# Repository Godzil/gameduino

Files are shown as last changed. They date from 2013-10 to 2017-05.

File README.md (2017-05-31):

gameduino
=========

What is it?
-----------

Gameduino is a game adapter for Arduino - or anything else with an SPI interface - built as a single shield that stacks up on top of the Arduino and has plugs for a VGA monitor and stereo speakers.

Legal stuffs
------------

This project was created by James Bowman <jamesb@excamera.com>. I strongly recommand you to visit his website first as it always will contain the more recent and official information about the Gameduino: http://excamera.com/sphinx/gameduino/index.html

Why this repo?
--------------

This github repository is maintained by Manoel Trapier <godzil@godzil.net> for his own project around Gameduino and by the fact there is missing a central repository with all needed file to build/hack your own Gameduino on Internet. James' website will of course store all of thoses files, but they are stored sparses around, and could be difficult to find.

More informations on Gameduino
-----------------------------

The sound and graphics are definitely old-school, but thanks to the latest FPGA technology, the sprite capabilities are a step above those in machines from the past.

video output is 400x300 pixels in 512 colors
all color processed internally at 15-bit precision
compatible with any standard VGA monitor (800x600 @ 72Hz)
background graphics
512x512 pixel character background
256 characters, each with independent 4 color palette
pixel-smooth X-Y wraparound scroll
foreground graphics
each sprite is 16x16 pixels with per-pixel transparency
each sprite can use 256, 16 or 4 colors
four-way rotate and flip
96 sprites per scan-line, 1536 texels per line
pixel-perfect sprite collision detection
audio output is a stereo 12-bit frequency synthesizer
64 independent voices 10-8000 Hz
per-voice sine wave or white noise
sample playback channel
The adapter is controlled via SPI read/write operations, and looks to the CPU like a 32Kbyte RAM. (Unlike many 8-bit machines, there are no restrictions on when you can access this RAM). There is a handy reference poster showing how the whole system works, and a set of sample programs and library.

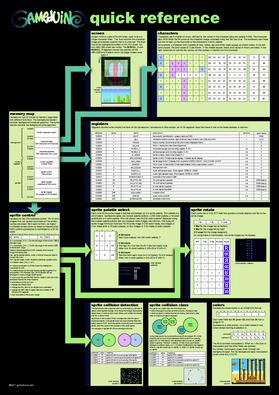
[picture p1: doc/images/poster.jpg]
Poster thumbnail


Contents
--------

You will find here all the data I've collected about the original Gameduino:
 - board/	contain the schematic and PCB design for the Gameduino
 - doc/		Documentation about the Gameduino and j1 CPU
 - fpga/	The FPGA source for the Gameduino
 - gd/		The Arduino library for the Gameduino
 - Python/	A set of tool writen in Python
 - j1/		The original j1 CPU with it's firmware and FPGA source
 - j0/		The slightly modified j1 CPU for the Gameduino, as the j0 is part of the Gameduino, only the firmware part is accessible here
 - archives/    Raw files found on James' website

Licensing
---------

Gameduino is open-source hardware (BSD license) and all its code is GPL licensed.

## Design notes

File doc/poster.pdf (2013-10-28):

# quick reference

# ©2011 gameduino.com

# screen

Screen RAM is a grid of 64×64 bytes, each byte is a single character index. This byte controls the character image and palette used for that 8×8 pixel cell. The total size of the background screen is 512×512 pixels, but only 400×300 pixels are visible. The SCROLL_X and SCROLL_Y registers control the position of this

400×300 pixel window within the larger screen area.

# memory map

### Gameduino has 32 kbytes of memory, organized into different functions. The background section controls background character graphics. The sprite

section controls the foreground sprite graphics.

# sprite control

### Gameduino has 256 hardware sprites: 16×16 pixel

images that can appear anywhere on the screen.

### Sprites are drawn from back-to-front, so higher-

numbered sprites cover up lower-numbered ones.

### Each sprite’s appearance is controlled by a 32-bit word:

# registers

Registers control some simple functions of the Gameduino. Gameduino is little-endian, so 16-bit registers have their lower 8 bits at the lower address in memory.

# characters

Characters are 8×8 grids of pixels, defined by the values in the character data and palette RAMs. The character data RAM holds the 64 pixels of the character image, encoded using two bits per pixel. The hardware uses these two bits to look up the final color in the character’s 4-entry palette.
For example, a character with a palette of blue, yellow, red and white might appear as shown below. In the left-hand square, the pixel values 0–3 are shown. In the middle square, these pixel values in binary are listed. In the right hand column are the hex values, as they appear in memory for this character.

# sprite palette select

Each pixel of the sprite image is fetched and looked up in a sprite palette. This palette is a list of colors. Gameduino gives you several palette options: a 256-color palette, a 16-color

### palette and a 4-color palette. Why not always use the 256-color palette? Because using the smaller palette options lets you squeeze more images into memory. 256 bytes of sprite image RAM can hold one 16x16 sprite image in 256-color mode, two images in

4-bit mode (with a 16 color palette), or four images in 2-bit mode (4 color palette).

# colors

### Gameduino stores colors in an ARGB1555 format:

### Each color field red (R) green (G) and blue (B) has a

range 0–31.

### Gameduino is little-endian, so a color stored in two bytes stored starting at address is:

### The A bit controls transparency. When A=1 the pixel is

transparent and the other fields are ignored.

### For sprites, transparent pixels show through the background layer. For the background layer, transparent

pixels show BG_COLOR.

# sprite rotate

### Each sprite has a 3-bit ROT field that applies a simple rotation and flip to the

sprite image.

background

0x0000

code
sample:
scroll

0x7FFF

control
registers

0x0FFF
0x1000

0x1FFF
0x2000

0x27FF
0x2800

0x2FFF
0x3000

0x37FF
0x3800

0x3FFF
0x2800

sprites

64x64 character screen

character data
256 characters of 8x8 pixels

character palettes
256 characters of 4 colors

control registers
collision RAM

sprite control
256x4 bytes

sprite palette
4 palettes of 256 colors

sprite images
64 images of 16x16 bytes

X X coordinate, 0-511. 0 is the left edge of the screen, 399 is the right edge.
Y Y coordinate, 0-511. 0 is the top edge of the screen, 299 is the bottom edge.
IMAGE Spriteimageselect,0-63. Selects which source image the sprite uses.
PAL Sprite palette select, 4 bits. Controls how pixel data is turned into color.
ROT Sprite rotate, 3 bits. Rotates a sprite by quarter-turns. C Collision class, 0 is J, 1 is K.
To hide a sprite park it off the screen by setting its Y coordinate to 400.
To make a large sprite draw several sprites together in a grid pattern. For example, four 16x16 sprites can be arranged to make a single 32x32 sprite.
To spin a sprite use the ROT field to rotate it, and use extra animation frames for finer rotations.
To animate a sprite you can
- change the IMAGE field
- change the PAL field to do simple color animation
- change the ROT field to apply flips and rotates of 90, 180 and 270 degrees
- load new data to the source image.

31 30 29 28 27 26 25 24 23 22 21 20 19 18 17 16 15 14 13 12 11 10 9 8 7 6 5 4 3 2 1 0
C | IMAGE | Y | PAL | ROT | X

SCROLL_X

SCROLL_Y

00 01 01 01

00 01 10 10

01 01 10 10

01 01 01 01

00 01 10 11

00 01 01 01

01 01 01 01

00 01 01 01

01 01 01 01

10 01 01 01

10 01 01 00

10 01 01 01

11 11 11 11

10 01 01 01

10 01 01 01

10 01 01 01

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
reset value
0x6d
0x10
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
0000 (black)
0000 (black)
0000 (black)
0000 (black)
0
0
0

access
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
name
IDENT
REV
FRAME
VBLANK
SCROLL_X
SCROLL_Y
JK_MODE
SPR_DISABLE
SPR_PAGE
IOMODE
BG_COLOR
SAMPLE_L
SAMPLE_R
SCREENSHOT_Y
PALETTE 16A
PALETTE 16B
PALETTE 4A
PALETTE 4B
COLLISION
VOICES
SCREENSHOT

bytes
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
address
0x2800
0x2801
0x2802
0x2803
0x2804
0x2806
0x2808
0x280A
0x280B
0x280C
0x280E
0x2810
0x2812
0x281E
0x2840
0x2860
0x2880
0x2888
0x2900
0x2A00
0x2B00

description
Gameduino identification—always reads as 0x6D
Hardware revision number. High 4 bits are major revision, low 4 bits are minor Frame counter, increments at the end of each displayed frame
Set to 1 during the video blanking period
Horizontal background scrolling register, 0–511
Vertical background scrolling register, 0–511
Sprite collision class mode enable 0–1
Sprite control: 0 enable sprite display, 1 disable sprite display
Sprite page select: 0 display from locations 0x3000–0x33FF, 1 from 0x3400–0x37FF Pin 2 mode: 0=disconnect, 0x46=flash enable, 0x4A=coprocessor control Background color
Audio left sample value, 16 bit signed -32768 to +32767
Audio right sample value, 16 bit signed -32768 to +32767
Screenshot line select 0–299
16-color sprite A palette
16-color sprite B palette
4-color sprite A palette
4-color sprite B palette
Collision RAM
Audio voice controls
Screenshot line RAM

### 8–bit mode Each byte indexes into 256-color palette, P

3 | 2 | 1 | 0
0 | 0
0 | 1 | N | AB
1 | N | AB

P

### 2–bit mode Two bits from each byte (N=3 is highest, N=0 is lowest) index into 4-color palette A (AB=0) or B (AB=1)

### 4–bit mode The high (N=1) or low (N=0) 4 bits from each byte index into 16-color palette A (AB=0) or B (AB=1)

code sample:
palettes
Y flip | X flip | XY swap
2 | 1 | 0

### Y flip flip the image top-to-bottom X flip flip the image left-to-right XY swap flip the image diagonally By using these in combination, the sprite image can be rotated:

code sample: rotation

ROT | Y flip | X flip | XY swap | results
7 | 1 | 1 | 1
6 | 1 | 1 | 0
5 | 1 | 0 | 1
4 | 1 | 0 | 0
3 | 0 | 1 | 1
2 | 0 | 1 | 0
1 | 0 | 0 | 1
0 | 0 | 0 | 0

code sample:
bgcolor

# sprite collision class

In a game you might have the following rules:
- when the player touches an enemy bomb, the player dies
- when a player’s missile touches an enemy, that enemy dies. Here is a typical in-game situation:

missile
01 (J)

player
player | 02 (K)
00 (J)

bomb
03 (K)

Notice that bomb 04 covers both bomb 03 and player 00. In this situation we’re much more interested that bomb 04 is covering player 00. For this reason, the hardware has a mode JK_MODE where it ignores “friendly” collisions. In this mode, each sprite belongs a collision class J or K. Collision notifications only happen when a J sprite covers up a K sprite, or when a K sprite covers up a J sprite.

code sample:
jkcollision

sprite 00 no collision

meaning

sprite 01 no collision
sprite 02 covers some pixels from sprite 01 sprite 03 no collision
sprite 04 covers some pixels from sprite 00

0x2900

address

0x2901
0x2902
0x2903
0x2904

FF

value

FF
01
FF
00

bomb
04 (K)

# sprite collision detection

The Gameduino has a special memory area that you can use to detect when sprites overlap. As it draws the image, Gameduino keeps track of which pixels cover others, and writes the results into the collision RAM.
Each byte in the collision RAM corresponds with the same numbered sprite. If the sprite does not cover another then the byte’s value is 0xFF. But if the sprite covers any part of another sprite, then the value is the number of the other sprite.
For example, if sprites 00–03 are arranged like this:
00 | 01 | 02

code sample:
collision

sprite 00 did not cover up any other sprite

meaning

sprite 01 covered up some pixels from sprite 00 sprite 02 did not cover up any other sprite sprite 03 covered some pixels from sprite 02

0x2900

address

0x2901
0x2902
0x2903

FF

value

00
FF
02

03

15 | 14 | 13 | 12 | 11 | 10 | 9 | 8 | 7 | 6 | 5 | 4 | 3 | 2 | 1 | 0
A | | | R | | | | | G | | | | | B

A

G2 | G1 | G0 | B4
7 | 6 | 5 | 4 | 3 | 2 | 1 | 0
| | | | B3 | B2 | B1 | B0
| R4 | R3 | R2 | R1 | R0 | G4 | G3

address

address+1

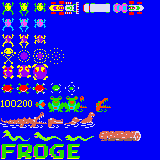
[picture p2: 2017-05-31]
python/471fcf9e.png

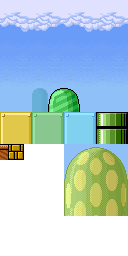
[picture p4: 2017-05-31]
python/platformer.png

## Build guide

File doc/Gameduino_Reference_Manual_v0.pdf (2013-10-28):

!"#$%&'()*+$,$-$(.$*/"(&"0

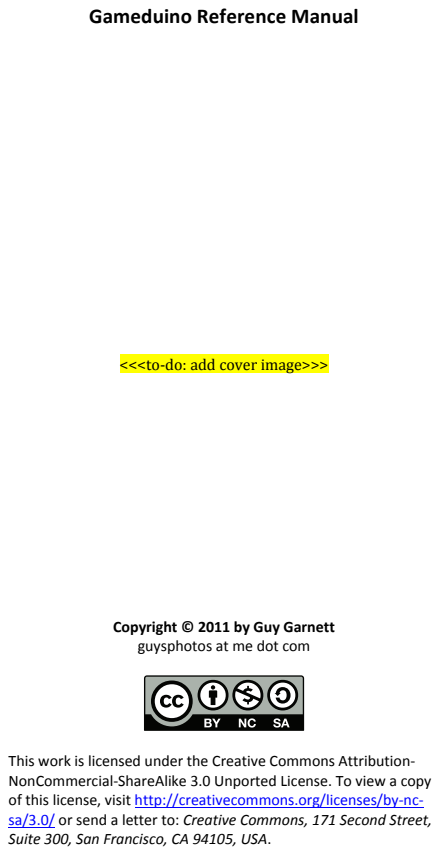
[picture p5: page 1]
/&0$)1'23)0$)40.,5$,-)"5-,2)(&,)62,*(07,)6'++'5$)8((209"(0'5: ;'56'++,2.0*4:<&*2,8403,)=>?)@5%'2(,-)A0.,5$,>)/')70,1)*).'%#) 'B)(&0$)40.,5$,C)70$0()&((%DEE.2,*(07,.'++'5$>'2!E40.,5$,$E9#:5.: $*E=>?E '2)$,5-)*)4,((,2)('D)!"#$%&'#(!)**)+,-(./.(0#1)+2(0%"##%-( 03&%#(455-(0$+(6"$+1&,1)-(!7 89.5:-(;07>

12345!6(.+&7-8$!2+9+,+8)+!:(87(;

1)(6$(6<
=.>()?0$%4$#$(6< @@@@@@@@@@@@@@@@@@@@@@@@@@@@@@@@@@@@@@@@@@@@@@@@@@@@@@@@@@@@@@@@@@@@@@@@@@@@@@@@@@: A(6-)%&.6')( @@@@@@@@@@@@@@@@@@@@@@@@@@@@@@@@@@@@@@@@@@@@@@@@@@@@@@@@@@@@@@@@@@@@@@@@@@@@@@@@@@@@@@@@@@@@@: !"#$*B-)4-"##'(4*?'65*!"#$%&'()@@@@@@@@@@@@@@@@@@@@@@@@@@@@@@@@@@@@@@@@@@@@@@@@@@@@@@@8
6+##-8/!<#(,#+&============================================================================================================================================================ > !"#$%"#&((((((((((((((((((((((((((((((((((((((((((((((((((((((((((((((((((((((((((((((((((((((((((((((((((((((((((((((((((((((((((((((((((((((((((((((((((((((((((((((((((((((() *&+&,-./&01'20+3#-0/&01((((((((((((((((((((((((((((((((((((((((((((((((((((((((((((((((((((((((((((((((((((((((((((((((((((((((((((((((((((((((((((((((((((4 1+*+;$?-8/!(!6(.+ =================================================================================================================================================== @ 5$$;A!(8&!5+)B8-C7+A============================================================================================================================================== D 50313",'6-%&#78. (((((((((((((((((((((((((((((((((((((((((((((((((((((((((((((((((((((((((((((((((((((((((((((((((((((((((((((((((((((((((((((((((((((((((((((((((((((((((9 :"/&$;30-'6<1=-0'813,313&>(((((((((((((((((((((((((((((((((((((((((((((((((((((((((((((((((((((((((((((((((((((((((((((((((((((((((((((((((((((((((((((((((((9 ?-0>&#+30@'A#$;30-'B&/-#< ((((((((((((((((((((((((((((((((((((((((((((((((((((((((((((((((((((((((((((((((((((((((((((((((((((((((((((((((((((((((((((((((C :"/&$;30-'D&>-;#E&'F3G#"#< (((((((((((((((((((((((((((((((((((((((((((((((((((((((((((((((((((((((((((((((((((((((((((((((((((((((((((((((((((((((((((((((C
C65$-*=220'."6')(<@@@@@@@@@@@@@@@@@@@@@@@@@@@@@@@@@@@@@@@@@@@@@@@@@@@@@@@@@@@@@@@@@@@@@@@@@@@@@@@@@@@@D
6+8+,(;%E7,?$A+!1-A?;(F!3&(?#+,====================================================================================================================== G H8&7A#,-(;!E,$)+AA!I$8#,$;===================================================================================================================================== G

### =%E"(.$%*!"#$%&'()*B-)4-"##'(4@@@@@@@@@@@@@@@@@@@@@@@@@@@@@@@@@@@@@@@@@@@@@@@@@@@@@@@@@F

G'%$)*H'#'(4 @@@@@@@@@@@@@@@@@@@@@@@@@@@@@@@@@@@@@@@@@@@@@@@@@@@@@@@@@@@@@@@@@@@@@@@@@@@@@@@@@@@@@@@@@@@@F
4,(.+!2(#+ =================================================================================================================================================================== J K+(.!<F8)B,$8-L(#-$8 ==========================================================================================================================================MN *-;G,&'H;II&#30@ ((((((((((((((((((((((((((((((((((((((((((((((((((((((((((((((((((((((((((((((((((((((((((((((((((((((((((((((((((((((((((((((((((((((((((((((((((((( JK 8.$"130@'LII7ME#&&0'LGN&E1> (((((((((((((((((((((((((((((((((((((((((((((((((((((((((((((((((((((((((((((((((((((((((((((((((((((((((((((((((((((((((((((( JJ O&#13E",'H,"0P30@ (((((((((((((((((((((((((((((((((((((((((((((((((((((((((((((((((((((((((((((((((((((((((((((((((((((((((((((((((((((((((((((((((((((((((((((((((((( J) D">1&#'?=">30@(((((((((((((((((((((((((((((((((((((((((((((((((((((((((((((((((((((((((((((((((((((((((((((((((((((((((((((((((((((((((((((((((((((((((((((((((((((((((( J4 K-#.(??+&!6,(?B-)A===============================================================================================================================================MD
I"-%?"-$*I".>'(4 @@@@@@@@@@@@@@@@@@@@@@@@@@@@@@@@@@@@@@@@@@@@@@@@@@@@@@@@@@@@@@@@@@@@@@@@@@@@@@@@@@:J 1'-.&'6*K)"-%*/)%','."6')(< @@@@@@@@@@@@@@@@@@@@@@@@@@@@@@@@@@@@@@@@@@@@@@@@@@@@@@@@@@@@@@@@@@@@:J
6(.+&7-8$!:$&-9-)(#-$8A ====================================================================================================================================MO P$FA#-)Q!<B-+;&!:$&-9-)(#-$8A==============================================================================================================================MO
L)MA6MN)&-<$0,*B-)O$.6<@@@@@@@@@@@@@@@@@@@@@@@@@@@@@@@@@@@@@@@@@@@@@@@@@@@@@@@@@@@@@@@@@@@@@@@@@@@@:D
H8?7#A!(8&!I$8#,$;;+,A ==========================================================================================================================================MG R8);$A7,+A!(8&!I(A+A=============================================================================================================================================MG
!"#$%&'()*H$.5('."0*+$,$-$(.$@@@@@@@@@@@@@@@@@@@@@@@@@@@@@@@@@@@@@@@@@@@@@@@@@@@@@@@@@@@@@:F I"-%?"-$*A(6$-,".$@@@@@@@@@@@@@@@@@@@@@@@@@@@@@@@@@@@@@@@@@@@@@@@@@@@@@@@@@@@@@@@@@@@@@@@@@@@@@@@@@:F
S(,&T(,+!I$.?(#-U-;-#F=======================================================================================================================================MJ <EH!I$..78-)(#-$8 ================================================================================================================================================MV F3G#"#<'M;..-#1 ((((((((((((((((((((((((((((((((((((((((((((((((((((((((((((((((((((((((((((((((((((((((((((((((((((((((((((((((((((((((((((((((((((((((((((((((((((((( )K A,1&#0"1&'M65'A$$#&>>(((((((((((((((((((((((((((((((((((((((((((((((((((((((((((((((((((((((((((((((((((((((((((((((((((((((((((((((((((((((((((((((((((((((((((( )K
/$#)-3*/"2@@@@@@@@@@@@@@@@@@@@@@@@@@@@@@@@@@@@@@@@@@@@@@@@@@@@@@@@@@@@@@@@@@@@@@@@@@@@@@@@@@@@@@@@@@89
6(.+&7-8$!:+.$,F!:(?=====================================================================================================================================>M

I$8#,$;!2+/-A#+,A =====================================================================================================================================================>> M="#&$'D&@3>1&#>(((((((((((((((((((((((((((((((((((((((((((((((((((((((((((((((((((((((((((((((((((((((((((((((((((((((((((((((((((((((((((((((((((((((((((((((((((((( )4
G'%$)*L'<20"3@@@@@@@@@@@@@@@@@@@@@@@@@@@@@@@@@@@@@@@@@@@@@@@@@@@@@@@@@@@@@@@@@@@@@@@@@@@@@@@@@@@@@@@@@@8F
<),$;;-8/=======================================================================================================================================================================>V Q#"."#-;0$(((((((((((((((((((((((((((((((((((((((((((((((((((((((((((((((((((((((((((((((((((((((((((((((((((((((((((((((((((((((((((((((((((((((((((((((((((((((((((((( )R M.,31'ME#&&0'ME#-,,30@((((((((((((((((((((((((((((((((((((((((((((((((((((((((((((((((((((((((((((((((((((((((((((((((((((((((((((((((((((((((((((((((((((((((((((( 4K K()Q/,$78&!I$;$,====================================================================================================================================================WN IB(,()#+,!6,(?B-)A =================================================================================================================================================WN DABS65?T'6,"<I3&,$'63E1;#& ((((((((((((((((((((((((((((((((((((((((((((((((((((((((((((((((((((((((((((((((((((((((((((((((((((((((((((((((((((((((((((((((( 4J DABS?!DT'6,"<I3&,$'?="#"E1&#'M&1(((((((((((((((((((((((((((((((((((((((((((((((((((((((((((((((((((((((((((((((((((((((((((((((((((((((((((((((((( 4J DABS6AFT'6,"<I3&,$'?="#"E1&#'6",&11&>(((((((((((((((((((((((((((((((((((((((((((((((((((((((((((((((((((((((((((((((((((((((((((((((((((((((( 4) <?,-#+A===========================================================================================================================================================================@W M.#31&'?-01#-,(((((((((((((((((((((((((((((((((((((((((((((((((((((((((((((((((((((((((((((((((((((((((((((((((((((((((((((((((((((((((((((((((((((((((((((((((((((((((((( U4 M.#31&'?-,,3>3-0'*&1&E13-0 (((((((((((((((((((((((((((((((((((((((((((((((((((((((((((((((((((((((((((((((((((((((((((((((((((((((((((((((((((((((((((((((((((( UU M.#31&'5/"@&'*"1"((((((((((((((((((((((((((((((((((((((((((((((((((((((((((((((((((((((((((((((((((((((((((((((((((((((((((((((((((((((((((((((((((((((((((((((((((( U9 M.#31&'6",&11&>((((((((((((((((((((((((((((((((((((((((((((((((((((((((((((((((((((((((((((((((((((((((((((((((((((((((((((((((((((((((((((((((((((((((((((((((((((((((((( U9 I$;$, ==============================================================================================================================================================================@G F-@3E",'?-,-# ((((((((((((((((((((((((((((((((((((((((((((((((((((((((((((((((((((((((((((((((((((((((((((((((((((((((((((((((((((((((((((((((((((((((((((((((((((((((((((( UV !"#$%"#&'?-,-# ((((((((((((((((((((((((((((((((((((((((((((((((((((((((((((((((((((((((((((((((((((((((((((((((((((((((((((((((((((((((((((((((((((((((((((((((((((((( UV L;1.;1'?-,-# (((((((((((((((((((((((((((((((((((((((((((((((((((((((((((((((((((((((((((((((((((((((((((((((((((((((((((((((((((((((((((((((((((((((((((((((((((((((((((((( UW
=&%')@@@@@@@@@@@@@@@@@@@@@@@@@@@@@@@@@@@@@@@@@@@@@@@@@@@@@@@@@@@@@@@@@@@@@@@@@@@@@@@@@@@@@@@@@@@@@@@@@@@@@@PQ
<$78&!<F8#B+A-A!2+/-A#+,A===================================================================================================================================@V O-3E&'?-01#-,((((((((((((((((((((((((((((((((((((((((((((((((((((((((((((((((((((((((((((((((((((((((((((((((((((((((((((((((((((((((((((((((((((((((((((((((((((((((((((( UR D30@'B-$;,"1-# (((((((((((((((((((((((((((((((((((((((((((((((((((((((((((((((((((((((((((((((((((((((((((((((((((((((((((((((((((((((((((((((((((((((((((((((((((((((( 9J <(.?;+!2+/-A#+,A======================================================================================================================================================DM
R:*1)2-).$<<)-@@@@@@@@@@@@@@@@@@@@@@@@@@@@@@@@@@@@@@@@@@@@@@@@@@@@@@@@@@@@@@@@@@@@@@@@@@@@@@@@@@@@@@@@ST
I$?,$)+AA$,!H8#+,9()+============================================================================================================================================DW ?-.#-E&>>-#'?-01#-,((((((((((((((((((((((((((((((((((((((((((((((((((((((((((((((((((((((((((((((((((((((((((((((((((((((((((((((((((((((((((((((((((((((((((((((( 94 ?-.#-E&>>-#'B3E#-E-$&((((((((((((((((((((((((((((((((((((((((((((((((((((((((((((((((((((((((((((((((((((((((((((((((((((((((((((((((((((((((((((((((((((((((( 94 ?-.#-E&>>-#'?-//;03E"13-0>'H,-EP((((((((((((((((((((((((((((((((((((((((((((((((((((((((((((((((((((((((((((((((((((((((((((((((((((((((((((((( 94 ?-.#-E&>>-#7L0,<'D&@3>1&#>(((((((((((((((((((((((((((((((((((((((((((((((((((((((((((((((((((((((((((((((((((((((((((((((((((((((((((((((((((((((((((((((( 9U PM!3,)B-#+)#7,+!(8&!E,$/,(..-8/ ===================================================================================================================DO X-#1=7H">&$'A>>&/G,<'F"0@;"@&((((((((((((((((((((((((((((((((((((((((((((((((((((((((((((((((((((((((((((((((((((((((((((((((((((((((((((((((((((( 9W 8>30@'1=&'YJ'A>>&/G,&#(((((((((((((((((((((((((((((((((((((((((((((((((((((((((((((((((((((((((((((((((((((((((((((((((((((((((((((((((((((((((((((((((((((((((( CJ YJ'A>>&/G,<'F"0@;"@&'D&I&#&0E&((((((((((((((((((((((((((((((((((((((((((((((((((((((((((((((((((((((((((((((((((((((((((((((((((((((((((((((((((((( CJ I$&+!X?#-.-L(#-$8===================================================================================================================================================GD YJ'B3E#-E-$&(((((((((((((((((((((((((((((((((((((((((((((((((((((((((((((((((((((((((((((((((((((((((((((((((((((((((((((((((((((((((((((((((((((((((((((((((((((((((((((( VV
U.-$$(<5)6*V$"6&-$@@@@@@@@@@@@@@@@@@@@@@@@@@@@@@@@@@@@@@@@@@@@@@@@@@@@@@@@@@@@@@@@@@@@@@@@@@@@@@@@@DF
<),++8AB$#!Y-8+!<+;+)#!2+/-A#+, ========================================================================================================================GJ <),++8AB$#!Y-8+!K799+, ==========================================================================================================================================GV
!0)<<"-3@@@@@@@@@@@@@@@@@@@@@@@@@@@@@@@@@@@@@@@@@@@@@@@@@@@@@@@@@@@@@@@@@@@@@@@@@@@@@@@@@@@@@@@@@@@@@@@@@@F9
3),$8F.A ====================================================================================================================================================================JN 5-.+===============================================================================================================================================================================JN

-*

1)%$
<Q+#)B!M'!Z(-#!9$,!6(.+&7-8$!H8-#-(;-L(#-$8================================================================================== D <Q+#)B!>'!H8-#-(;-L(#-$8!T-#B!<?;(AB!<),++8 ==================================================================================== D <Q+#)B!W'!6(.+!Y$$?!7A-8/!61''T(-#*U;(8Q[\=============================================================================MW <Q+#)B!@'!<EH!H8-#-(;-L(#-$8===================================================================================================================>N <Q+#)B!D'!PM!3AA+.U;F!E,$/,(.!5+.?;(#+====================================================================================DO <Q+#)B!O'!R](.?;+!<7U,$7#-8+===========================================================================================================GW <Q+#)B!G'!R](.?;+!:7;#-?;+%R8#,F!<7U,$7#-8+ ===========================================================================GW <Q+#)B!J'!H8),+.+8#-8/!Y$$? =============================================================================================================G@ <Q+#)B!V'!1+),+.+8#-8/!Y$$? ============================================================================================================G@

*

H";0$<
5(U;+!M'!JNN]ONN!<^63!^-&+$!X7#?7#============================================================================================== J 5(U;+!>'!^-&+$!4,(.+!2(#+ ==================================================================================================================== V 5(U;+!W'!^+,#-)(;!K;(8Q-8/====================================================================================================================M> 5(U;+!@'!S$A#!H8#+,9()+==========================================================================================================================MJ 5(U;+!D'!S(,&T(,+!I$.?(#-U-;-#F!Y-A#============================================================================================MJ 5(U;+!O'!6(.+&7-8$!:+.$,F!:(?===================================================================================================>M 5(U;+!G'!H1R_5!2+/-A#+, =======================================================================================================================>@ 5(U;+!J'!2R^!2+/-A#+, ============================================================================================================================>@ 5(U;+!V'!423:R!2+/-A#+,======================================================================================================================>@ 5(U;+!MN'!^KY3_`!2+/-A#+, ================================================================================================================>@ 5(U;+!MM'!<I2XYYab!(8&!<I2XYYac!2+/-A#+,A============================================================================>D 5(U;+!M>'!P`a:X1R!2+/-A#+,===============================================================================================================>O 5(U;+!MW'!PMa2R<R5!2+/-A#+, ==============================================================================================================>O 5(U;+!M@'!<E2a1H<3KYR!2+/-A#+,======================================================================================================>O 5(U;+!MD'!<E2aE36R!2+/-A#+,=============================================================================================================>G 5(U;+!MO'!HX:X1R!2+/-A#+, ================================================================================================================>G 5(U;+!MG'!K6aIXYX2!2+/-A#+,============================================================================================================>G 5(U;+!MJ'!<3:EYRaY!(8&!<3:EYRa2!2+/-A#+,A==========================================================================>G 5(U;+!MV'!<I2RR_<SX5ac!2+/-A#+,=================================================================================================>J 5(U;+!>N'!<I2XYY!2+/-A#+,A================================================================================================================>V 5(U;+!>M'!K6aIXYX2!2+/-A#+,============================================================================================================WN 5(U;+!>>'!23:aIS2!K-#.(?!X,/(8-L(#-$8 ===================================================================================WM 5(U;+!>W'!IB(,()#+,!<+#A=======================================================================================================================W> 5(U;+!>@'!23:aE3Y!E(;+##+!4$,.(# ================================================================================================WW 5(U;+!>D'!23:aEHI!:+.$,F!:(?=====================================================================================================W@ 5(U;+!>O'!23:aIS2!:+.$,F!:(?===================================================================================================WD 5(U;+!>G'!23:aE3Y!:+.$,F!:(?====================================================================================================WV 5(U;+!>J'!<?,-#+!I$8#,$;!Z$,&===========================================================================================================@W 5(U;+!>V'!<?,-#+!E(;+##+!:$&+A==========================================================================================================@@ 5(U;+!WN'!<?,-#+!2$#(#-$8=====================================================================================================================@@ 5(U;+!WM'!<?,-#+!H.(/+!K-#.(?==========================================================================================================@D 5(U;+!W>'!23:a<E2E3Y!:+.$,F!:(?============================================================================================@O 5(U;+!WW'!E3YR55RMO!:+.$,F!:(?===============================================================================================@O 5(U;+!W@'!MO%I$;$,!<?,-#+!E(;+##+ =====================================================================================================@O 5(U;+!WD'!E3YR55R@!:+.$,F!:(?==================================================================================================@G 5(U;+!WD'!@%I$;$,!<?,-#+!E(;+##+========================================================================================================@G 5(U;+!WO'!E(;+##+!R8#,F!4$,.(#=========================================================================================================@J 5(U;+!WG'!I$;$,!<?()+ ============================================================================================================================@J 5(U;+!WV'!^XHIR<!:+.$,F :(? ========================================================================================================@V 5(U;+!@N'!<3:EYRaY!(8&!<3:EYRa2!2+/-A#+,A==========================================================================D> 5(U;+!WJ'!PMa2R<R5!2+/-A#+, ==============================================================================================================DW 5(U;+!WV'!PMaIX1R!:+.$,F!:(?======================================================================================================DW 5(U;+!@N'!IX::!:+.$,F!:(?==========================================================================================================D@

*-

5(U;+!@M'!cYH_R!2+/-A#+, =====================================================================================================================D@ 5(U;+!@>'!4E63!HI3E!2+/-A#+,A==========================================================================================================DD 5(U;+!@W'!42RdSe!(8&!42Rd5HI`!2+/-A#+,A===============================================================================DD 5(U;+!@@'!E>!HfX!2+/-A#+,A===================================================================================================================DD 5(U;+!@D'!23_1X:!2+/-A#+,===============================================================================================================DO 5(U;+!@O'!IYXI`!2+/-A#+,====================================================================================================================DO 5(U;+!@G'!4Y3<S!<EH!2+/-A#+,A ==========================================================================================================DO 5(U;+!@J'!PM!3AA+.U;F!Y(8/7(/+!<7..(,F =================================================================================DV 5(U;+!@V'!PM!3AA+.U;+,!1-,+)#-*+A ===================================================================================================OM 5(U;+!DN'!PM!Y-#+,(;!H8A#,7)#-$8A =======================================================================================================O> 5(U;+!DM'!PM!3_<!4$,#B!H8A#,7)#-$8A================================================================================================OW 5(U;+!D>'!PM!3&&-#-$8(;!H8A#,7)#-$8A ===============================================================================================OO 5(U;+!DW'!PM!:7;#-%Z$,&!H8A#,7)#-$8A=============================================================================================OO 5(U;+!D@'!PM!:+,/+&!H8A#,7)#-$8A =====================================================================================================OG 5(U;+!DD'!PM!3AA+.U;+,!4;$T!I$8#,$; =============================================================================================GM 5(U;+!DO'!PM!:-),$)$&+!H8A#,7)#-$8A ===============================================================================================GG 5(U;+!DG'!3Yg!X?+,(#-$8!I$&+A ========================================================================================================GJ 5(U;+!DJ'!1(#(!<#()Q!3&h7A#.+8# =====================================================================================================GJ 5(U;+!DV'!2+#7,8!<#()Q!3&h7A#.+8#=================================================================================================GJ 5(U;+!ON'!<I2RR_<SX5ac!2+/-A#+,=================================================================================================GJ 5(U;+!OM'!<I2RR_<SX5!:+.$,F!:(?===========================================================================================GV

*--

V'4&-$<
4-/7,+!M'!^-&+$!1-A?;(F!Y(F+,A==========================================================================================================>G 4-/7,+!>'!<),$;;-8/ ===================================================================================================================================>G 4-/7,+!W'!<),$;;!Z,(?(,$78&==============================================================================================================>J 4-/7,+!@'!PM!Y$/-)(;!3,)B-#+)#7,+ ======================================================================================================DO

*---

+$<)&-.$<
2+A$7,)+!M'!S(,&T(,+!<$7,)+A =========================================================================================================== > 2+A$7,)+!>'!<$9#T(,+!1$T8;$(&!Y-8QA ============================================================================================ W

M

## FMK'6*!"#'(4*?'65*=-%&'()*"(%*!"#$%&'()

=.>()?0$%4$#$(6<
P(.+A!K$T.(8!),+(#+&!#B+!6(.+&7-8$i!(8&!T-#B$7#!B-A!B+;?i!-8?7#i!(8&!)$,,+)#-$8A! #B-A!&$)7.+8#!T$7;&!8$#!+]-A#=!!38F!*(;7(U;+!-89$,.(#-$8!-8!#B-A!.(87(;!7;#-.(#+;F! )$.+A!9,$.!P(.+Ai!(8&!(8F!+,,$,A!#B(#!T+,+!-8#,$&7)+&!-8!#B+!?,$)+AA!(,+!.-8+=

5B+!.+.U+,A!$9!#B+!6(.+&7-8$%K+#(!.(-;-8/!;-A#i!?(,#-)7;(,;F!I$;-8 1$$;+F! ?,$*-&+&!*(;7(U;+!9++&U()Q!(8&!+8)$7,(/+.+8#!U(A+&!$8!-8-#-(; &,(9#A!$9!#B-A! .(87(;=
A(6-)%&.6')(
:$&+,8!.-),$)$8#,$;;+,Ai!;-Q+!#B+!3#.+;!3^2!?,$)+AA$,A!#B(#!?$T+,!#B+!$?+8% A$7,)+!3,&7-8$!U$(,&Ai!(,+!(#!;+(A#!(A!?$T+,97;!(A!#B+!J%U-#!IEgA!#B(#!?$T+,+&! (,)(&+!*-&+$!/(.+A!-8!#B+!j/$;&+8!(/+k!$9!#B+!MVJNlA=!!4$,!+](.?;+i!#B+!e-;$/!eJN! T(A!(8!(&*(8)+&!J%U-#!IEg!#B(#!(;A$!9+(#7,+&!;-.-#+&!MO%U-#!-8A#,7)#-$8A=!!5B+!eJN! ,(8!(#!A?++&A!$9!7?!#$!(!.-;;-$8!-8A#,7)#-$8A!?+,!A+)$8&i!(8&!?$T+,+&!);(AA-)!/(.+A! A7)B!(A E()!:(8i!1$8Q+F!`$8/i!(8&!6(;(]-(8=!!KF!)$.?(,-A$8i!#B+!35.+/(W>J!#B(#! -A!(#!#B+!B+(,#!$9!#B+!3,&7-8$!g8$!+]+)7#+A!7?!#$!MO .-;;-$8!J%U-#!-8A#,7)#-$8A!?+,! A+)$8&=

5B+!6(.+&7-8$!-A!(8!3,&7-8$!AB-+;&!#B(#!?,$*-&+A!^63 *-&+$!(8&!A#+,+$!(7&-$! $7#?7# A7-#(U;+!9$,!j);(AA-)k!*-&+$!/(.-8/!7A-8/!)7A#$. 4E63 B(,&T(,+= g8;-Q+! $#B+,!3,&7-8$%U(A+&!*-&+$!/(.+!?,$h+)#Ai!#B+!6(.+&7-8$!?,$*-&+A!+]#+8A-*+! B(,&T(,+!A7??$,#!9$,!9$,+/,$78&!(8&!U()Q/,$78&!)$;$,!/,(?B-)Ai!)$;;-A-$8! &+#+)#-$8i!(8&!A$78&!/+8+,(#-$8=!!5B+!6(.+&7-8$!7A+A!(!A-.?;+!<EH!-8#+,9()+!A$!-#!-A! (&(?#(U;+!#$!.(8F!&-99+,+8#!.-),$)$8#,$;;+,Ai!(8&!-A!?$T+,97;!(8&!9;+]-U;+!+8$7/B! #B(#!-#!)(8!U+!7A+&!9$,!A-/8-9-)(8#!8$8%/(.+!(??;-)(#-$8A=

>

!"#$*B-)4-"##'(4 ?'65*!"#$%&'()

!"##$%&'(#)*#"+

I"-%?"-$
5$!&$!(8F#B-8/ 7A+97;!T-#B!(!6(.+&7-8$i!F$7!T-;;!8++&!(!)$.?(#-U;+! .-),$)$8#,$;;+,i!(!6(.+&7-8$!U$(,&i!(A!T+;;!(A!(!.$8-#$,i!A?+(Q+,Ai!(8&!A$.+!A$,#! $9!/(.+!)$8#,$;;+,!$,!$#B+,!-8?7#!&+*-)+=!!H9!F$7!T(8#!#$!/+#!A#(,#+&!T-#B!#B+!+](.?;+! )$&+!(8&!AQ+#)B+A!-8!#B-A!U$$Qi!-8 (&&-#-$8!#$!F$7,!)$.?7#+,i!F$7!T-;;!8++&'
- 38!3,&7-8$!g8$!$,!:+/(>DON
- 3!6(.+&7-8$ AB-+;&i!(8&
- 3!<?(,Q478!h$FA#-)Q!AB-+;&m!?;7A
- <?+(Q+,A!$,!B+(&?B$8+A!9$,!A$78&!$7#?7#i!(8&
- 3!.$8-#$,!#B(#!A7??$,#A!JNN]ONN!n!G>SL!(8&!(8!(8(;$/!^63!-8?7#= 5B+!S(,&T(,+!<$7,)+A!#+]#!U$]!U+;$T!A7//+A#A!A$.+!?;()+A!TB+,+!F$7!)(8!$U#(-8! #B+!)$.?$8+8#A!.+8#-$8+&!-8!#B-A!U$$Q=!!X#B+,!B(,&T(,+!)$89-/7,(#-$8A!(,+! )+,#(-8;F!?$AA-U;+!o A-8)+!#B-A!-A!(8!3,&7-8$!?,$h+)#i!),+(#-*+!$,!B$.+%U7-;#!A$;7#-$8A! (,+!+8)$7,(/+&=

"""5$%&$'!,+9+,+8)+!(!A+)#-$8!$8!U7-;&-8/!F$7,!$T8!-8#+,9()+!B(,&T(,+000

!"#$%"#&'())&*+,-
3,,(8/+!#B+!.$8-#$,!(8&!A?+(Q+,A!-8!F$7,!T$,Q!(,+(!A$!#B(#!#B+F!(,+!())+AA-U;+!U7#! $7#!$9!#B+!T(F=!!c$7!T-;;!T(8#!#$!?;()+!#B+!3,&7-8$!(8&!6(.+&7-8$!B(,&T(,+! A$.+TB+,+!)$8*+8-+8#i!A$ #B(#!F$7!)(8!7A+!#B+!h$FA#-)Q!U$(,&!#$!#+A#!F$7,!/(.+! AQ+#)B+A!TB-;+!Q++?-8/!-#!)$88+)#+&!#$!F$7,!)$.?7#+,!(8&!#B+!.$8-#$,!(8&! A?+(Q+,A=!!5B+8!?7#!+*+,F#B-8/!#$/+#B+,'
M= IB+)Q!#B+!AB-+;&A!9$,!U+8#!?-8Ai!(8&!/+8#;F!A#,(-/B#+8!(8F!#B(#!(,+!$7#!$9! ?;()+=
>= <#()Q #B+!6(.+&7-8$!AB-+;&!$8!#$?!$9!#B+!3,&7-8$i!(8&!?7AB!#B+!AB-+;&lA!?-8A! -8#$!#B+!B+(&+,=!!IB+)Q!9$,!U+8#!?-8A!(8&!.(Q+!A7,+!#B+!AB-+;&!-A!A+)7,+;F! A+(#+&=

3,&7-8$ U$(,&A'!B##?'ff(,&7-8$=))f+8f:(-8fK7F

6(.+&7-8$!AB-+;&'!5$!U+!&+#+,.-8+&p

P$FA#-)Q!AB-+;&!Q-#'!B##?'ffTTT=A?(,Q978=)$.f?,$&7)#AfVGON K(,+!h$FA#-)Q!AB-+;&!U$(,&'!B##?'ffTTT=A?(,Q978=)$.f?,$&7)#AfV@VN

!"#$%&'"()*(+,&-.,&"(/$%&'"#

W

W= <#()Q!#B+!h$FA#-)Q!AB-+;&!$8!#$?!$9!#B+!6(.+&7-8$i!(/(-8!)B+)Q-8/!9$,!U+8#! ?-8A!(8&!+8A7,-8/!#B(#!#B+ AB-+;&!-A!9-,.;F!A+(#+&=!!H#!T$7;&!8$#!&$!#$!B(*+!#B+! A#()Q!)$.+!(?(,#!TB-;+!?;(F-8/!F$7,!/(.+!AQ+#)B=
@= I$88+)#!#B+!.$8-#$,!(8&!A?+(Q+,A!#$!#B+!?$,#A!$8!#B+!6(.+&7-8$=

.*/0&'1&)2
3!jA.$Q+!#+A#k!-A!#B+!-8-#-(;!#+A#!$9!(!8+T!B(,&T(,+!AFA#+.!o #B+!-&+(!-A!#$!.(Q+!A7,+! #B(#!+*+,F#B-8/!T$,QA![(8&!&$+A8l#!B(*+!(8F!AB$,#!)-,)7-#A!$,!$#B+,!AB$T%A#$??+,A\! U+9$,+!&$-8/!(8F#B-8/!.$,+!)$.?;-)(#+&=!!5$!#+A#!F$7,!B(,&T(,+'
M= E$T+,%$8!#B+!.$8-#$,!(8&!A?+(Q+,A=
>= K$$#!7?!F$7,!)$.?7#+,=!!X8)+!#B+!)$.?7#+,!-A!,788-8/i
W= I$88+)#!F$7,!)$.?7#+,!#$!#B+!3,&7-8$!7A-8/!(!g<K!)(U;+![$,!$?#-$8(;;Fi!F$7! )(8!7A+!(!T(;;%?$T+,!(&(?#+,!A7-#(U;+!9$,!#B+!3,&7-8$\=
@= E,+AA!#B+!,+A+#!U7##$8!$8!#B+!h$FA#-)Q!AB-+;&=

c$7!AB$7;&!/+#!A$.+!$7#?7#!9,$.!#B+!6(.+&7-8$!$8!#B+!.$8-#$,!(8&!A?+(Q+,A=!! ZB(#!F$7!/+#!T-;;!&+?+8&!$8!TB(#!-A!;$(&+&!$8#$!#B+!AFA#+.i!+-#B+,'
- 5B+!3A#+,$-&A!/(.+!AQ+#)B!T-;;!A#(,#!T-#B!#B+!j3<5R2XH1<k!;$/$!A),$;;i!-9! F$7,!3,&7-8$!)(.+!T-#B!#B+!6(.+&7-8$i!-#!AB$7;&!U+!?,+%;$(&+&!T-#B!#B-A! AQ+#)Bm!$,!
- H9!F$7!B(*+!(!jA#$)Qk!3,&7-8$!#B(#!&$+A8l#![F+#\!B(*+!(8F!6(.+&7-8$%(T(,+! AQ+#)B+A!;$(&+&!$8#$!-#i!F$7!T-;;!/+#!#B+!6(.+&7-8$lA!U$$#!A),++8i!9+(#7,-8/! #B+!6(.+&7-8$!;$/$!(8&!A#(,#%7?!A$78&= H9!F$7!&$8l#!/+#!$7#?7#!9,$.!#B+!6(.+&7-8$i!$,!/+#!A$.+#B-8/!T-;&;F!&-99+,+8#i!#,F! A$.+!$9!#B+!#,$7U;+AB$$#-8/!A#+?A!U+;$T!#$!-A$;(#+!#B+!?,$U;+.=

1#/3+,&)4//2567

"""5$%&$'!(&&!#,$7U;+AB$$#-8/!-89$,.(#-$8000

L$E$0)2#$(6*W(E'-)(#$(6
_$T!#B(#!#B+!B(,&T(,+!-A!A+#!7?i!F$7!T-;;!(;A$!8++&!(!&+*+;$?.+8#!+8*-,$8.+8#! U+9$,+!F$7!)(8!A#(,#!),+(#-8/!F$7,!$T8!*-&+$!/(.+!AQ+#)B+A=!!5B+!U(A-)!6(.+&7-8$! &+*+;$?.+8#!+8*-,$8.+8#!)$8A-A#A!$9'
- 3!)$.?7#+,!,788-8/!,+)+8#!*+,A-$8A!$9!+-#B+,!Z-8&$TAi!:()!X<!bi!$,!Y-87]i!
- 5B+!3,&7-8$!-8#+/,(#+&!&+*+;$?.+8#!+8*-,$8.+8#![H1R\i (8&!
- 5B+!6(.+&7-8$!A$9#T(,+!&+*+;$?.+8#!Q-#![<1`\=
^-A-# #B+!&$T8;$(&!;-8QA!;-A#+&!U+;$T #$!/+#!#B+!A$9#T(,+!F$7!8++&=

3,&7-8$!H1R' B##?'ff(,&7-8$=))f+8f:(-8f<$9#T(,+
6(.+&7-8$!<1`' B##?'ff+])(.+,(=)$.fA?B-8]f/(.+&7-8$fA(.?;+Af-8&+]=B#.;

!"#$%&'"(0*(/$12.,&"(3$.45$,-(6748#

@

86)2",,"25/6'"6$'.&29:;
X8)+!F$7!B(*+!(;;!$9!#B+!?-+)+Ai!F$7!)(8!A+#!7?!F$7,!&+*+;$?.+8#!+8*-,$8.+8#=!!5B+! +]()#!A#+?A!T-;;!*(,F!&+?+8&-8/!$8!F$7,!)B$-)+!$9!$?+,(#-8/!AFA#+.i!U7#!#B+! 9$;;$T-8/!A#+?A!AB$7;&!A+,*+!#$!/+#!F$7!A#(,#+&'
M= H8A#(;;!#B+!3,&7-8$!H1R!9$;;$T-8/!#B+!-8A#,7)#-$8A!#B(#!)(.+!T-#B!#B+!U-8(,F! &-A#,-U7#-$8!9$,!F$7,!?;(#9$,.=!!
>= ^+,-9F!#B(#!#B+!3,&7-8$!H1R!-A!T$,Q-8/!)$,,+)#;F!UF!;(78)B-8/!#B+!H1R!(8&! A+;+)#-8/!(8!+](.?;+!AQ+#)B!9,$.!#B+!4-;+!.+87=!!1$!8$#!(##+.?#!#$!)$.?-;+! $,!,78!#B-A!+](.?;+m!T+!(,+!h7A#!*+,-9F-8/!#B(#!#B+!3,&7-8$!H1R!-A!T$,Q-8/= W= g8?()Q!#B+!6(.+&7-8$!<1`!&-A#,-U7#-$8!UF!78L-??-8/!#B+!6(.+&7-8$=eHE! (,)B-*+!9-;+=!!5B-A!T-;;!),+(#+!(!j6(.+&7-8$k!&-,+)#$,F!T-#B!.7;#-?;+!9-;+A!(8&! A7U&-,+)#$,-+A!-8A-&+!$9!-#=!!_$#+!#B+!;$)(#-$8!$9!#B+!6(.+&7-8$!&-,+)#$,F!9$,! 7A+!-8!A#+?!O!U+;$T=
@= Y$)(#+!F$7,!3,&7-8$!AQ+#)BU$$Q!&-,+)#$,F=!!5B+!&+9(7;#!;$)(#-$8!T-;;!*(,F! &+?+8&-8/!$8!F$7,!$?+,(#-8/!AFA#+.i!U7#!AB$7;&!U+!(!A7U&-,+)#$,F!$9!F$7,! 7A+,!$,!B$.+!&-,+)#$,F=!!c$7!)(8!9-8&!(8&!)B(8/+!#B+!AQ+#)BU$$Q!;$)(#-$8! 7A-8/!#B+!E,+9+,+8)+A!$?#-$8!$9!#B+!3,&7-8$!H1R=
D= H9!-#!&$+A8l#!(;,+(&F!+]-A#i!),+(#+!(!&-,+)#$,F!)(;;+&!j;-U,(,-+Ak!-8A-&+!$9!#B+! 3,&7-8$!AQ+#)BU$$Q!&-,+)#$,F=!!H9!#B+!&-,+)#$,F!(;,+(&F!+]-A#Ai!AQ-?!#B-A!A#+?= O= :$*+!#B+!6(.+&7-8$!&-,+)#$,F!9,$.!A#+?!W!-8#$!#B+!;-U,(,-+A!&-,+)#$,F! ),+(#+&!-8!A#+?!D!(U$*+=

8<='"6$'.<>'1&)2567
X8)+!+*+,F#B-8/!-A!-8A#(;;+&i!F$7!AB$7;& #+A# #B+!6(.+&7-8$!&+*+;$?.+8#! +8*-,$8.+8#!U+9$,+!A#(,#-8/!#$!T$,Q!$8!F$7,!$T8!AQ+#)B+A=!!5$!#+A#!#B+!#$$;!)B(-8' M= d7-#!#B+!3,&7-8$!H1R!-9!-#!-A!A#-;;!,788-8/i!#B+8!;(78)B!#B+!3,&7-8$!H1R=!! d7-##-8/!(8&!,+%A#(,#-8/!#B+!H1R!9$,)+A!-#!#$!,+%A)(8!#B+!AQ+#)BU$$Q!(8&! ;-U,(,-+A=
>= Y$(&!(!6(.+&7-8$!&+.$!?,$/,(.'!/$!#$!#B+!4-;+!.+87i!(8&!7A-8/!#B+! A7U.+87A!?-)Q!R](.?;+Ai!6(.+&7-8$i!@=1+.$i!(8&!9-8(;;F!jU(;;k=!!5B+!U(;;! AQ+#)B!AB$7;&!$?+8!-8!(!8+T!T-8&$T=
W= I$.?-;+!#B+!AQ+#)B!7A-8/!#B+!^+,-9F!U7##$8!$8!#B+!3,&7-8$!H1R=!!H#!AB$7;&! )$.?-;+!T-#B!8$!+,,$,A!$,!T(,8-8/A=
@= g?;$(&!#B+!AQ+#)B!#$!#B+!3,&7-8$!(8&!,78!-#i!UF!7A-8/!#B+!g?;$(&!U7##$8!$8! #B+!H1R=!!39#+,!(!U,-+9!?(7A+i!#B+!U$78)-8/%U(;;!&+.$!AB$7;&!U+!&-A?;(F+&!$8! #B+!.$8-#$,!T-#B!())$.?(8F-8/!(7&-$!$7#?7#!$8!#B+!A?+(Q+,A= I$8/,(#7;(#-$8Ap!!c$7!8$T!B(*+!(!978)#-$8-8/!6(.+&7-8$!&+*+;$?.+8#! +8*-,$8.+8#i!(8&!F$7!(,+!,+(&F!#$!A#(,#!T,-#-8/!F$7,!9-,A#!/(.+!AQ+#)B=
,"-"./0$%&')'!)1"

"""#$%&$'!(&&!-89$,.(#-$8!(A!#B+!5Sg1!/(.+!-A!&+*+;$?+&000

D

2//.3')%+'2"45%$67"3

A('6'"0*B)?$-MX2
4$;;$T-8/!(!B(,&!,+A+#i!A7)B!(A!-8-#-(;!?$T+,%$8i!#B+!6(.+&7-8$!,+C7-,+A!(!AB$,# (.$78#!$9!#-.+!#$!,+U$$#i!;$(&!#B+!4E63!)$89-/7,(#-$8i!(8&!-8-#-(;-L+!U+9$,+!-#!-A! ,+(&F!#$!())+?#!)$..(8&A=!5B-A!-A8l#!8$,.(;;F!(8!-AA7+!TB+8!&+*+;$?-8/!)$&+!-8!#B+! 3,&7-8$!H1Ri!A-8)+!&$T8;$(&-8/!(!8+T!AQ+#)B!$,!,+A+##-8/!#B+!3,&7-8$!&$+A8l#!9$,)+! (!6(.+&7-8$!,+A+#=!!5B+!6(.+&7-8$!;-U,(,F!8$,.(;;F!B(8&;+A!#B-A!-8!#B+!61=U+/-8[\! .+#B$&!UF!.(Q-8/!A7,+!#B(#!#B+!6(.+&7-8$!-A!,+(&F!#$!())+?#!)$..(8&A!U+9$,+! -8-#-(;-L-8/!#B+!U$(,&!(8&!,+#7,8-8/=

H9!F$7!(,+!8$#!7A-8/!#B+!;-U,(,Fi!F$7,!AQ+#)B!T-;;!B(*+!#$!B(8&;+!#B-A!.(87(;;F=!H#! #(Q+A!#B+!6(.+&7-8$!U+#T++8!MGD.A (8&!>DN.A #$!)$.?;+#+!-#A!?$T+,%$8! -8-#-(;-L(#-$8=!!5B+!6(.+&7-8$!.(F!-/8$,+!$,!9(-;!#$!97;;F!,+A?$8&!#$ <EH!)$..(8&A! #B(#!(,,-*+!U+9$,+!#B-A!#-.+i!A$!AQ+#)B+A!.(F B(*+!78?,+&-)#(U;+!A$78&!(8&!/,(?B-)! (,#-9()#A!78#-;!#B+!3,&7-8$!-A!,+A+#=!!2+A+##-8/!#B+!3,&7-8$!9-]+A!#B+!?,$U;+.i!A-8)+! #B+!,+A+#!9$,)+A!#B+!3,&7-8$!#$!,+%,78!-#A A+#7?[\!.+#B$& T-#B$7#!9$,)-8/!(!B(,&! ,+A+#!$9!#B+!6(.+&7-8$=!!S$T+*+,i!#B-A!A$;7#-$8!-A8l#!*+,F!?,()#-)(;!9$,!9-8(;!)$&+! #B(#!-A!/$-8/!#$!U+!+.U+&&+&!-8!(!&+*-)+=

5B+!U+A#!A$;7#-$8!#$!#B+!?,$U;+.!-A!#$!
+8A7,+!#B(#!#B+!6(.+&7-8$!-A!
,+A?$8&-8/!#$!)$..(8&A!U+9$,+!
A+8&-8/!-8A#,7)#-$8A!#$!-#=!!<Q+#)B!M'!
Z(-#!9$,!6(.+&7-8$!H8-#-(;-L(#-$8 AB$TA!$8+!A7)B!(??,$()B!7A-8/!61!;-U,(,F!978)#-$8A!9$,!U,+*-#F!(8&!);(,-#F=!!5B-A! )$&+!9,(/.+8#!,+?+(#+&;F!T,-#+A!(!Q8$T8i!8$8%&+9(7;#!*(;7+!#$!6(.+&7-8$!23:i! 78#-;!(##+.?#-8/!#$!,+(&!#B+!23:!,+A7;#A!-8!#B+!*(;7+!T,-##+8!o &+.$8A#,(#-8/!#B(#! #B+!6(.+&7-8$!B(A!())+?#+& (8&!?,$)+AA+&!U$#B!)$..(8&A=

38$#B+,!(??,$()B!-A!#$!-8A+,#!(!&+;(F!
-8#$!#B+!)$&+!U+9$,+!(##+.?#-8/!#$!
)$..78-)(#+!T-#B!#B+!6(.+&7-8$=!!3! &+;(F!$9!(#!;+(A#!>DN.A!T-;;!(;;$T!#B+!
6(.+&7-8$!+8$7/B!#-.+!#$!-8-#-(;-L+!
(8&!,+A?$8&!#$!)$..(8&Am!(!;$8/+,! &+;(F!T-;;!(;;$T!#B+!?$T+,%$8!A?;(AB!A),++8!#$!&-A?;(F=!!!3A!AB$T8!UFi!<Q+#)B!>'! H8-#-(;-L(#-$8!T-#B!<?;(AB!<),++8+*+8!-9!F$7!(,+!7A-8/!#B+!6(.+&7-8$!;-U,(,Fi! -8A+,#-8/!(!&+;(F!U+9$,+!)(;;-8/!61=U+/-8[\!T-;;!(;;$T!#B+!A?;(AB!A),++8!#$!(??+(,!(#! ?$T+,%7?=

!"#$%&'()*B365)(*X6'0'6'$<

"""#$%&$'!(&&!-89$,.(#-$8!(U$7#!#B+!EF#B$8!7#-;-#F!?()Q(/+000

do {
GD.wr(RAM_SPRIMG, 0xFF);
} while (GD.rd(RAM_SPRIMG) != 0xFF); GD.wr(RAM_SPRIMG, 0x00);

/8"2'9()*(:,72(1$&(;,<"-%74$(=4727,57>,27$4(

void setup() {
delay(2500);
GD.begin();
}

/8"2'9(0*(=4727,57>,27$4(.729(/?5,#9(/'&""4

O

1)(<$-E'(4*=-%&'()*/$#)-3

"""#$%&$'!(&&!8$#+!(U$7#!E2X6:R:!9,$.!#B+!)$$QU$$Q!?(/+000 """#$%&$'!(&&!8$#+A!9,$.!6(.+&7-8$%K+#(!;-A#!(U$7#!)$8A+,*-8/ .+.$,F000

!"#$%&'()*+$<)&-.$*Y';-"-3

"""#$%&$'!(&&!&+A),-?#-$8!$9!#B+!;-U,(,F!(8&!B$T!#$!())+AA!-#000

G

C65$-*=220'."6')(<
5B+!6(.+&7-8$!B(A!(!87.U+,!$9!?$T+,97;!8$8%/(.+!(??;-)(#-$8A!(A!(!*+,A(#-;+! *-&+$!(&(?#+,!9$,!3,&7-8$!(8&!?$#+8#-(;;F!$#B+,!.-),$)$8#,$;;+,A=!!<-8)+!-#!7A+A! A#(8&(,&!^63!.$8-#$,A!9$,!-89$,.(#-$8!$7#?7#i!-#!-A!(!)$A#%+99+)#-*+!(8&!*+,A(#-;+! &-A?;(F!(&(?#+,=!I$.?(,+&!#$!.$A#!$#B+,!3,&7-8$!$7#?7#!&+*-)+Ai!#B+!6(.+&7-8$lA! *-&+$!&-A?;(F!)(8!?,+A+8#!(!;$#!$9!-89$,.(#-$8=!!3!6(.+&7-8$!)(8!?,+A+8#!(#!;+(A#!#+8! #-.+A!#B+!)B(,()#+,!-89$,.(#-$8!(A!(!#F?-)(;!.7;#-%;-8+!YI1!&-A?;(Fi!$,!(;.$A#!#T-)+! (A!.(8F!$8%A),++8!?-]+;A!(A!(!d^63!A),++8=!!
!"%"*).897*0/3"',$30.):';+)0#"*
3A!(!/+8+,(;%?7,?$A+!&-A?;(F!(&(?#+,i!#B+!6(.+&7-8$!^63!A),++8!)(8!)$8#(-8!WG! ;-8+A!$9!DN!)B(,()#+,A!+()Bi!TB-)B!)$.?(,+A!T+;;!#$!(!#F?-)(;!A+,-(;!YI1=!!<+,-(;!YI1A! )$..$8;F!7A+&!T-#B!#B+!3,&7-8$!&-A?;(F!M!#$!@!;-8+A!$9!J!#$!W>!)B(,()#+,A=!!5B+!#T$! &+*-)+A!#F?-)(;;F!B(*+!A-.-;(,!-8#+,9()+!,+C7-,+.+8#A'!(8!<EH!$,!A+,-(;!)$88+)#-$8 7A+A!(!9+T!3,&-8$!?-8A=!!:(8F!YI1!)$8#,$;;+,A!T-;;!(;A$!())+?#!&$T8;$(&(U;+! )B(,()#+,!A+#Ai!(;;$T-8/!#B+!?,$/,(..+,!#$!&+9-8+!(??;-)(#-$8%A?+)-9-)!/;F?BA=

g8;-Q+!A+,-(;!&-A?;(F!(&(?#+,Ai!#B+!6(.+&7-8$!,+C7-,+A!.$,+!-8-#-(;-L(#-$8'!(! )$.?;+#+!)B(,()#+,!A+#![+*+8!#B+!U(A+!3<IHH!/;F?BA\!.7A#!U+!A#$,+&!-8!#B+!B$A#! .-),$)$8#,$;;+,lA!?,$/,(.!RRE2X:!(8&!&$T8;$(&+&!#$!#B+!6(.+&7-8$!U+9$,+!(8F! &(#(!)(8!U+!$7#?7#=!!:$A#!YI1!&-A?;(FA!-8);7&+!(!U7-;#%-8!+]#+8&+&!3<IHH!)B(,()#+,! A+#!#B(#!)(8!U+!7A+&!-..+&-(#+;F=

<?,-#+!/,(?B-)A!)(8!U+!7A+&!#$!-.?;+.+8#!)7,A$,A!$,!?$-8#+,A=!!3;#+,8(#-*+;Fi!#B+! 6(.+&7-8$lA!A?,-#+!.+.$,F!)(8!U+ (,,(8/+&!(A!(!B-/B%,+A$;7#-$8!/,(?B-)A!$*+,;(F #B(#!)(8!U+!(&&,+AA+&!(#!#B+!A-8/;+!?-]+;!;+*+;i!(A!&+A),-U+&!-8 #B+!A+)#-$8!$8 K-#.(??+&!6,(?B-)A U+/-88-8/!$8!?(/+!MD=!!5B-A!(;;$TA!(8!(,+(!$9!(,U-#,(,F!B-/B% ,+A$;7#-$8!/,(?B-)A!$8!(8!$#B+,T-A+!#+]#%U(A+&!A),++8=
<%+73#*$).'9*/4"33'=/%#*/.
5B+!6(.+&7-8$!)(8!(;A$!U+!7A+&!9$,!-8&7A#,-(;!?,$)+AA%)$8#,$;!(8&!AFA#+.A!A#(#7A! .$8-#$,-8/!(??;-)(#-$8A=!!K+)(7A+!-#!B(A!(!,+;(#-*+;F!A-.?;+i!<EH%U(A+&!B$A#!-8#+,9()+i! -#!)(8!U+!)$8#,$;;+&!UF!8+(,;F!(8F!?,$)+AA!)$8#,$;;+,!$,!(7#$.(#-$8!.-),$)$8#,$;;+,! #B(#!A7??$,#A!<EH!)$..78-)(#-$8=!!K+)(7A+!#B+!+8#-,+!)B(,()#+,!A+#!-A!)7A#$.-L(U;+! $8!#B+!6(.+&7-8$i!A?+)-(;-L+&!AF.U$;A!A?+)-9-)!#$!#B+!(??;-)(#-$8!)(8!U+! &$T8;$(&+&!(8&!+(A-;F!&-A?;(F+&=!!!!

IB(,()#+,!/,(?B-)A!-8!)$.U-8(#-$8!T-#B!#B+!6(.+&7-8$lA!A?,-#+!/,(?B-)A!)(8!U+! 7A+&!#$!-.?;+.+8#!/(7/+A!(8&!?$-8#+,Ai!(8&!?,$*-&+!(!78-C7+!T(F!$9!?,+A+8#-8/! -89$,.(#-$8!-8!(8!+(AF%#$%78&+,A#(8&!*-A7(;!9$,.(#=!!4$,!+](.?;+i!(!U(,!/,(?B!A)(;+! )(8!U+!U7-;#!9,$.!(!A.(;;!87.U+,![W!$,!@\!$9!)B(,()#+,Ai!(8&!(!A?,-#+!)(8!U+!7A+&!(A! (8!-8&-)(#$,!#$!*-A7(;;F!,+?,+A+8#!#B+!.+(A7,+.+8#!*(;7+=

"""#$%&$'!-8A+,#!A),++8AB$#!(8&!+](.?;+!AQ+#)B!AB$T-8/!/(7/+A000

J

=%E"(.$%*!"#$%&'() B-)4-"##'(4
G'%$)*H'#'(4
5B+!6(.+&7-8$!/+8+,(#+A!(!<^63!*-&+$!A-/8(;!#B(#!)$89$,.A!#$!#B+!A#(8&(,&A!9$,! G>SL!JNN]ONN!*-&+$!T-#B!(!DN:BL!&$#!);$)Q=!!5(U;+!M'!JNN]ONN!<^63!^-&+$!X7#?7# A7..(,-L+A!#B+!),-#-)(;!*-&+$!#-.-8/!?(,(.+#+,A=!!<++!B##?'ff#-8F*/(=)$.f*/(% #-.-8/fJNN]ONNnG>SL 9$,!&+#(-;+&!^R<3!^63!A-/8(;!#-.-8/!-89$,.(#-$8=

@,A5"()*(BCCDECC(/F;G(F7-"$(H%2?%2
S$,-L$8#(;!5-.-8/
E-]+;!I;$)Q | DN=N:BL!!!!
4,+C7+8)F | @J=NGGQSL
2+A$;7#-$8 | JNN!?-]+;A!qMr
3)#-*+!^-&+$ | MO=NsA
K;(8Q-8/ | @=JsA
^+,#-)(;!5-.-8/
4,+C7+8)F | G>SL
2+A$;7#-$8 | ONN!;-8+A!q>r
3)#-*+!^-&+$ | M>=@JN.A
K;(8Q-8/ | M=WG>J.A
_$#+A'
qMr 6(.+&7-8$!&$7U;+A ?-]+;A!9$,!(!B$,-L$8#(;!,+A$;7#-$8!$9!@NN!&$7U;+%A-L+!?-]+;A=
q>r 6(.+&7-8$!&$7U;+A!A)(8!;-8+A!9$,!(!*+,#-)(;!,+A$;7#-$8!$9!WNN!&$7U;+%A-L+!?-]+;A=

5B+,+!(,+!#T$!Q+FA!#$!()B-+*-8/!A.$$#B!*-&+$!/(.+!(8-.(#-$8'!9,(.+!,(#+A!(8&! U+(.!AF8)B,$8-L(#-$8=!4,(.+!,(#+!,+9+,A!#$!B$T!$9#+8!T+!7?&(#+!#B+!A),++8! -89$,.(#-$8i!(8&!U+(.!AF8)B,$8-L(#-$8!&-)#(#+A!TB+8!T+!7?&(#+!#B(#!-89$,.(#-$8=
>*)1"'?)#"
5B+!6(.+&7-8$!/+8+,(#+A!*-&+$!(#!G>SLi!$,!G>!9,(.+A!?+,!A+)$8&![9?A\!8$!.(##+,! TB(#!$7,!/(.+!?,$/,(..-8/!-A!&$-8/=!S$T+*+,i!T+!)(8!)B$$A+!B$T!$9#+8!$7,! ?,$/,(.!7?&(#+A!#B+!A),++8i!,+A7;#-8/!-8!(!;$/-)(;!9,(.+!,(#+!#B(#!&-99+,A!9,$.!#B+! G>9?A!B(,&T(,+!9,(.+!,(#+=!KF!7?&(#-8/!#B+!&-A?;(F!+*+,F!>⁸&i!W,&i!$,!@#B 9,(.+i! 6(.+&7-8$!A$9#T(,+!)(8!/+8+,(#+!;$T+,%9,+C7+8)F!&-A?;(FA=!5B+!;$T+,!&-A?;(F! 9,+C7+8)-+A!(;;$T!#B+!/(.+!?,$/,(.!.$,+!)$.?7#(#-$8!#-.+!U+#T++8!7?&(#+Ai!(8&! (;A$!,+&7)+!#B+!(.$78#!$9!-89$,.(#-$8!#B(#!B(A!#$!U+!#,(8A9+,,+&!+()B!A+)$8&=

^-&+$!&-A?;(FA!&+?+8&!$8!?+,A-A#+8)+!$9!*-A-$8!#$!A.$$#B!$7#!#B+!9;-)Q+,!U+#T++8! &-99+,+8#!9,(.+A=!5B+!?$-8#!TB+,+!-8&-*-&7(;!9,(.+A!A.$$#B!$7#!*(,-+A!U+#T++8! ?+,A$8!#$!?+,A$8i!)B(8/+A!T-#B!&-99+,+8#!;-/B#-8/!)$8&-#-$8Ai!(8&!)(8!(;A$!&+?+8&!$8! #B+!A?++&!$9!#B+!/(.+!$,!(8-.(#-$8=!3!B-/B+,!9,(.+!,(#+!.+(8A!.$,+!9,+C7+8#! [9(A#+,\!7?&(#+A!.+(8!#B(#!$8%A),++8!$Uh+)#A!(??+(,!#$!.$*+!A.$$#B;F=!3!;$T!9,(.+! ,(#+!.(Q+A!$8%A),++8!$Uh+)#A!(??+(,!#$!9;-)Q+,!$,!h+,Q!(),$AA!#B+!A),++8=!38! -8)$8A-A#+8#!$,!*(,-(U;+!9,(.+!,(#+!.(F!.(Q+!#B-8/A!(??+(,!#$!A#7##+,!$,!.$*+! +,,(#-)(;;F=!5B+!?$-8#!TB+,+!#B-8/A!(??+(,!#$!U+!A.$$#B!-A!7A7(;;F!A$.+TB+,+!

V

U+#T++8!WN9?A!(8&!ON9?Ai!U7#!&+?+8&A!/,+(#;F!$8!U$#B!#B+!)$8#+8#!$9!#B+!A),++8!(8&! #B+!*-+T+,=!!4$,!+](.?;+i!.$*-+!#B+(#+,A!7A+!(!>@9?A!9,(.+!,(#+!9$,!.$A#!)-8+.(#-)! ,+;+(A+Ai!U7#!A#-;;!()B-+*+!#B+!-;;7A-$8!$9!A.$$#B!)$8#-87$7A!.$#-$8=

5B+!6(.+&7-8$lA!G>9?A!B(,&T(,+!*-&+$!/+8+,(#-$8!-A!)$.9$,#(U;F!(U$*+!#B-A!*-A7(;! ;-.-#=!6(.+A!#B(#!)(8!,78!(#!#B-A!,(#+!AB$7;&!U+!A.$$#B!(8&!9;-)Q+,%9,++i!A$!.$A#! /(.+!AQ+#)B+A!AB$7;&!A#,-*+!9$,!#B-A!/$(;=!<$9#T(,+!.(F!()B-+*+!B-/B+,!7?&(#+! 9,+C7+8)-+Ai!U7#!#B+!B(,&T(,+!#B(#!/+8+,(#+A!#B+!^63!$7#?7#!A-/8(;!$8;F!7?&(#+A!#B+! A),++8!G>!#-.+A!?+,!A+)$8&=

3!WO9?A!9,(.+!,(#+i!$,!7?&(#+A!+*+,F!$#B+,!9,(.+i!-A!A#-;;!9(A#!+8$7/B!#$!(??+(,! A.$$#B!78&+,!.(8F )$8&-#-$8A=!4(A#%.$*-8/!$Uh+)#A [;-Q+!(!?,$h+)#-;+\!$,!B-/B% )$8#,(A#!-#+.A![;-Q+!TB-#+!A#(,A!$8!(!U;()Q!U()Q/,$78&\ .(F!(??+(,!#$!9;-)Q+,!$,! A#7##+,!9$,!A$.+!*-+T+,A=!5B-A!,(#+!-A!$9#+8!(!/$$&!)$.?,$.-A+i!A-8)+!-#!(;;$TA!#T-)+! #B+!)$.?7#(#-$8!#-.+!U+#T++8!9,(.+A!U7#!-A!A#-;;!A.$$#B=

5B+!>@9?A!9,(.+!,(#+!-A!#B+!A(.+!(A!.$*-+!?,$h+)#$,Ai!(8&!-A!#B+!A;$T+A#!,(#+!#B(#! )(8!(??+(,!A.$$#B!#$!.$A#!*-+T+,A=!XUh+)#-$8(U;+!9;-)Q+,i!h-##+,i!$,!$#B+,!*-A7(;! (,#-9()#A!.(F!U+!(??(,+8#!78&+,!A$.+!;-/B#-8/!)$8&-#-$8Ai!$8!9(A#%.$*-8/!$Uh+)#Ai!$,! TB+8!#B+,+!-A!B-/B!)$8#,(A#!U+#T++8!A+C7+8#-(;!9,(.+A=

4,(.+!,(#+A!$9!MJ9?A!T-;;!(??+(,!#$!9;-)Q+,i!A#7##+,i!$,!B(*+!8$#-)+(U;+!*-A7(;!(,#-9()#A! #$!.$A#!*-+T+,A=!S$T+*+,i!#B-A!9,(.+!,(#+!(;;$TA!9$,!?;+8#F!$9!)$.?7#(#-$8!#-.+! U+#T++8!9,(.+Ai!(8&!.(F!U+!A7-#(U;+!9$,!)+,#(-8!Q-8&A!$9!/(.+Ai!?(,#-)7;(,;F! A#,(#+/-)!/(.+A!#B(#!&$8l#!9+(#7,+!9(A#%.$*-8/!()#-$8=

<$.+!Q-8&A!$9!/(.+A!)(8!U+8+9-#!9,$.!A+;+)#-*+!7?&(#+A'!9(A#%.$*-8/!$,!B-/B )$8#,(A#!?$,#-$8A!$9!#B+!&-A?;(F!AB$7;&!U+!7?&(#+&!.$,+!9,+C7+8#;Fi!TB-;+!$#B+,! -#+.A!(,+!7?&(#+&!;+AA!$9#+8=!!4$,!+](.?;+i!(!A?()+!/(.+!.-/B#!7?&(#+!(!A),$;;-8/! U()Q/,$78&!(#!G>9?Ai!U7#!)$7;&!7A+!(!WO9?A!9,(.+!,(#+!9$,!A?,-#+!(8-.(#-$8A!#$!A(*+! .+.$,F!(8&!?,$)+AA$,!#-.+=

5B+!.(-8!,+(A$8!9$,!)B$$A-8/!(!;$/-)(;!9,(.+!,(#+!;$T+,!#B(8!G>9?A!-A!#$!(;;$T! ?,$/,(.A!#B(#!,+C7-,+!+]#+8A-*+!)$.?7#(#-$8!U+#T++8!9,(.+A!#$!)$.?;+#+!#B+-,! T$,Q!(8&!7?&(#+!#B+!A),++8=!5B+!#(U;+!U+;$T!AB$TA!B$T!.7)B!#-.+!-A!(*(-;(U;+=

@,A5"(0*(F7-"$(I&,<"(!,2"
2(#+ | 1-* | <Q-? | 5-.+ | IF);+A!?+,!4,(.+
3,&7-8$ | <EH | PM
G>!9?A | M | N | MW=JJ.A | >>>i>>> | MWiJJJ | OV@i@@@
WO!9?A | > | M | >G=GG.A | @@@i@@@ | >GiGGG | MiWJJiJJJ
>@!9?A | W | > | @M=OO.A | OOOiOOO | @MiOOO | >iNJWiWWW
MJ!9?A | @ | W | DD=DD.A | JJJiJJJ | DDiDDD | >iGGGiGGG
D"1&'!Y$/-)(;!9,(.+!,(#+i!-8!9,(.+A!?+,!A+)$8&![9?A\=
*3+'!4,(.+!,(#+!&-*-A$,= Y$/-)(;!9,(.+!,(#+!t!G>9?A!B(,&T(,+!9,(.+!,(#+!u!1-*= MP3.'!_7.U+,!$9!9,(.+A!AQ-??+&!U+#T++8!7?&(#+A=

MN

Z3/&'!R;(?A+&!#-.+!U+#T++8!7?&(#+Ai!-8!.-;;-A+)$8&A![.Am!M.A!t!MvMN%W!A+)$8&A\= A#$;30-'!_7.U+,!$9!-8A#,7)#-$8!)F);+A!U+#T++8!7?&(#+A!(AA7.-8/!(!MO:BL!35.+/(J! ?,$)+AA$,= <$.+!3^2!-8A#,7)#-$8A!#(Q+!.$,+!#B(8!$8+!)F);+= M65'!_7.U+,!$9!<EH!UF#+!#,(8A9+,A!U+#T++8!7?&(#+A!(AA7.-8/!(!MO:BL!<EH!U7A!);$)Q= 5B+!6(.+&7-8$!<EH!-8#+,9()+!,+C7-,+A!#T$!(&&,+AA!UF#+A!#$!A+#!7?!(!#,(8A9+,i!?;7A! $8+!UF#+!?+,!&(#(!UF#+!,+(&!$,!T,-##+8!#$!6(.+&7-8$!.+.$,F= YJ'!_7.U+,!$9!-8A#,7)#-$8!)F);+A!U+#T++8!7?&(#+A!9$,!#B+!6(.+&7-8$lA!PM!)$?,$)+AA$,= :$A#!)$?,$)+AA$,!-8A#,7)#-$8A!#(Q+!$8+!)F);+i!(;#B$7/B!.+.$,F!,+(&!(8&!T,-#+! -8A#,7)#-$8A!#(Q+!#T$!)F);+A=
@")1'(:%45*/%$A)#$/%
3;#B$7/B!#B+!6(.+&7-8$lA!&$7U;+%?$,#+&!23:!(;;$TA!?,$/,(.A!#$!7?&(#+!/,(?B-)A! &(#(!T-#B$7#!?,+*+8#-8/!#B+!*-&+$!/+8+,(#$,!9,$.!9+#)B-8/!&(#(i!7?&(#-8/!/,(?B-)A! &(#( #B(#!-A!)7,,+8#;F!U+-8/!&,(T8!$8!#B+!A),++8!)(8!)(7A+!#+(,-8/!$,!$#B+,!/;-#)B+A! -8!#B+!*-&+$!$7#?7#=!4$,!+](.?;+i!-9!T+!7?&(#+!(!A?,-#+lA!c!?$A-#-$8!TB-;+!-#!-A!U+-8/! &,(T8!$8!A),++8i!(!9+T!;-8+A!$9!#B+!A?,-#+!T-;;!(??+(,!(#!#B+!$;&!;$)(#-$8i!(8&!#B+!,+A#! T-;;!(??+(,!(#!#B+!8+T!;$)(#-$8i!.(Q-8/!#B+!A?,-#+!;$$Q!;-Q+!-#!-A!#$,8!-8!B(;9=

"""#$%&$'!-8A+,#!#$,8!A?,-#+!-.(/+000

5B+!A$;7#-$8!-A!#$!7?&(#+!$Uh+)#A!TB+8!#B+F (,+!8$#!U+-8/!&,(T8!$8!#B+!A),++8=!!5B-A! )(8!U+!&$8+!*-(!&$7U;+!U799+,-8/i!7?&(#-8/!$99%A),++8!$Uh+)#Ai!UF!T(-#-8/!9$,!*+,#-)(;! U;(8Q-8/i!(8&!UF!,(A#+,!)B(A-8/!#+)B8-C7+A=

L)&;0$*K&,,$-'(4
X8+!$U*-$7A!A$;7#-$8!#$!#B+!?,$U;+.!-A!#$!Q++?!#T$!)$?-+A![U799+,A\!$9!+*+,F#B-8/'! $8+!-A!7A+&!#$!&,(T!#B+!&-A?;(F TB-;+ #B+!$#B+,!-A!U+-8/!7?&(#+&=!ZB+8!#B+!7?&(#+!-A! &$8+i!#B+!#T$!U799+,A!(,+!AT(??+&!(8&!#B+!8+T;F!7?&(#+&!)$?F!-A!7A+&!#$!&,(T!#B+! 8+]#!9,(.+!$9!#B+!&-A?;(F=!5B+!U-/!&,(TU()Q!#$!&$7U;+!U799+,-8/!-A!#B(#!-#!,+C7-,+A!(! ;$#!$9!.+.$,Fi!(8&!A$.+!T(F!$9!C7-)Q;F AT(??-8/!#B+!#T$!U799+,A=!5B+!6(.+&7-8$! B(,&T(,+!A7??$,#A!#,7+!&$7U;+!U799+,-8/!9$,!A?,-#+!)$8#,$;!&(#(i!(8&!;-.-#+&!&$7U;+! U799+,-8/!9$,!#B+!A?,-#+!U-#.(?A!(8& )B(,()#+,!?-)#7,+=

1$7U;+!U799+,-8/!9$,!A?,-#+A!-A!)$8#,$;;+&!UF!#B+!<E2aE36R!,+/-A#+,!(#!N]>JNK! [MN>DM!&+)-.(;\=!!ZB+8!<E2aE36R!-A!Ni!A?,-#+!)$8#,$;!&(#(!?(/+!N!-A!$8!A),++8'!#B+! &(#(!-8!;$)(#-$8A!N]WNNN!#$!N]WW44![M>>JJ!#$!MWWMM!&+)-.(;\!-A!7A+&!#$!/+8+,(#+! #B+!&-A?;(F=!!ZB+8!?(/+!N!-A!U+-8/!&-A?;(F+&i!#B+!A?,-#+!)$8#,$;!&(#(!A#,7)#7,+A!$8! ?(/+!M!(#!;$)(#-$8A!N]W@NN!#$!N]WG44![MWWM>!#$!M@WWD!&+)-.(;\!)(8!U+!7?&(#+&! T-#B$7#!)(7A-8/!*-A7(;!/;-#)B+A=!!<+##-8/!<E2aE36R!#$!M!,+*+,A+A!#B+!A-#7(#-$8'!?(/+! M!&(#(!-A!7A+&!#$!&,(T!#B+!A),++8!&-A?;(Fi!(8&!?(/+!N!)(8!U+!7?&(#+&=

5$!-.?;+.+8#!A?,-#+!&$7U;+!U799+,-8/!-8!F$7,!AQ+#)B+Ai!(AA7.-8/!#B(#!F$7,!AQ+#)B!-A! 9(A#!+8$7/B!#$!7?&(#+!#B+!A?,-#+A!+*+,F!9,(.+'
M= H8-#-(;-L+!A?,-#+!)$8#,$;!&(#(!?(/+A!N!(8&!M!T-#B!#B+!A(.+!&(#(i!&+9-8-8/!#B+! A(.+!A?,-#+A!$8!+()B!?(/+=
>= H8-#-(;-L+!<E2aE36R!#$!N=
W= Z(-#!9$,!*+,#-)(;!U;(8Q-8/=

MM

@= 5$//;+!<E2aE36R'!A+#!-#!#$!M!-9!-#!-A!)7,,+8#;F!Ni!$,!A+#!-#!#$!N!-9!-#!T(A!M=
D= g?&(#+!A?,-#+!?$A-#-$8Ai!U-#.(?Ai!(8&!$#B+,!(##,-U7#+A!UF!)B(8/-8/!*(;7+A!-8! #B+!8$8%&-A?;(F+&!?(/+'!-9!<E2aE36R!-A!Ni!7?&(#+!#B+!A?,-#+A!A#(,#-8/!(#! N]W@NNm!-9!<E2aE36R!-A!M!7?&(#+!#B+!A?,-#+A!A#(,#-8/!(#!N]WNNN=
O= 6$!#$!<#+? W!#$!&,(T!#B+!8+]#!9,(.+=

H9!F$7,!/(.+!&$+A8l#!7A+!(;;!$9!#B+!A?,-#+!U-#.(?!.+.$,Fi!F$7!)(8!(;A$!&$7U;+!U799+,! A?,-#+!U-#.(?A=!!Z-#B$7#!7A-8/!#B-A!#F?+!$9!&$7U;+!U799+,-8/i!#B+!*+,#-)(;!U;(8Q-8/! ?+,-$&!-A!A$!AB$,#!#B(#!-#!-A!&-99-)7;#!#$!,+&+9-8+!A?,-#+!-.(/+!&(#(!-8!23:a<E2H:6 U+9$,+!#B+!&-A?;(F!-A!&,(T8=!!K+)(7A+!+()B!U-#.(?!-A!>DO!UF#+Ai #B+,+!-A!+8$7/B!#-.+! #$!7?&(#+!@!$,!D!A?,-#+!U-#.(?A!-9!#B+!<EH!U7A!-A8l#!7A+&!9$,!(8F#B-8/!+;A+!&7,-8/! *+,#-)(;!U;(8Q-8/=!!S$T+*+,i!UF!&$7U;+!U799+,-8/!A?,-#+!U-#.(?Ai!)B(8/+A!)(8!U+! .(&+!&7,-8/!#B+!+8#-,+!*-&+$!9,(.+i!(;;$T-8/!?;+8#F!$9!#-.+!#$!7?&(#+!W>!U-#.(?A=! K-#.(?A!#B(#!(,+8l#!)7,,+8#;F!U+-8/!7A+&!)(8!U+!)B(8/+&!78&+,!?,$/,(.!)$8#,$;i! (8&!#B+8!#B+!A?,-#+!A$7,)+!-.(/+!&(#(![U-#A!>D%WN!$9!#B+!A?,-#+!)$8#,$;!&(#(! A#,7)#7,+\!)(8!U+!)B(8/+&!#$!?$-8#!#$!#B+!.$&-9-+&!U-#.(?=!!4$,!+](.?;+i!(!/-*+8! A?,-#+!)$7;&!7A+!A$7,)+!-.(/+A!N!(8&!W>=!!ZB+8!A$7,)+!-.(/+!N!-A!U+-8/!7A+&!UF!#B+! A?,-#+i!A$7,)+!-.(/+!W> )(8!U+!7?&(#+&=!!5B+!A?,-#+lA!&(#(!A#,7)#7,+!)(8!U+!)B(8/+&! #$!AT(?!A$7,)+!-.(/+!U-#.(?A!&7,-8/!#B+!*+,#-)(;!U;(8Q-8/!?+,-$&i!,+A7;#-8/!-8! /;-#)B%9,++!A?,-#+!U-#.(?!(8-.(#-$8= 5B-A!A)B+.+!T$,QA!U+A#!TB+8!#B+,+!(,+!9+T! +8$7/B!A?,-#+A!#B(#!#T$!U-#.(?A!)(8!U+!(;;$)(#+&!#$!+()B!A?,-#+=!!5B(#!T(Fi!;$T% 87.U+,+&!U-#.(?A![N!#$!WM\!)(8!U+!7?&(#+&!TB-;+!B-/B%87.U+,+&!U-#.(?A![W>!#$! OW\ (,+!$8!A),++8i!(8&!*-)+%*+,A(=

<-.-;(,;Fi!AQ+#)B+A!)(8!,+&+9-8+!#B+!)B(,()#+,!U-#.(?A=!!H9!#B+!)B(,()#+,!U+-8/! ,+&+9-8+&!-A8l#!?,+A+8#!$8%A),++8i!#B+!U-#.(?!)(8!U+!7?&(#+&!(#!(8F!#-.+=!!5B+!A(.+! ;$TfB-/B!A)B+.+!)(8!U+!7A+&!T-#B!)B(,()#+,!U-#.(?Ai!U7#!78;-Q+!A?,-#+Ai!+()B! )B(,()#+,!$8!#B+!&-A?;(F!.7A#!U+!)B(8/+&!-8&-*-&7(;;F!&7,-8/!#B+!*+,#-)(;!U;(8Q-8/! ?+,-$&!#$!(8-.(#+!#B+!U-#.(?i!TB-)B!A+*+,+;F!;-.-#A!#B+!+99+)#-*+8+AA!$9!#B+! (??,$()B=

ZB+8!&+A-/8-8/!&$7U;+%U799+,-8/!A)B+.+Ai!-#!-A!(!/$$&!-&+(!#$!.(]-.-L+!<EH!&(#(! #,(8A9+,!+99-)-+8)F!UF!Q++?-8/!(;;!$9!#B+!&(#(!#$!U+!7?&(#+&!-8!(!)$8#-/7$7A!U;$)Q=!! 4$,!+](.?;+i!7?&(#-8/!W>!A?,-#+!U-#.(?A!-8!(!A-8/;+!U;$)Q!#(Q+A!JMV@!<EH!)F);+A![>!#$! A+#!7?!#B+!(&&,+AA!(8&!JMV>!#$!#,(8A9+,!W>!U-#.(?A!$9!>DO!UF#+A!+()B\=!!g?&(#-8/!W>! A?,-#+!U-#.(?A!-8&-*-&7(;;F!,+C7-,+A!J>DO!<EH!)F);+A![W>!U-#.(?Ai!+()B!$9!TB-)B! ,+C7-,+A!(!>%UF#+!(&&,+AA!9$;;$T+&!UF!>DO!&(#(!UF#+A\i!A$!Q++?-8/!#B+!&(#(!#$/+#B+,! A(*+A!O>!<EH!)F);+A=

X2%"6'(4*C,,MU.-$$(*C;O$.6< 5B+!6(.+&7-8$!B(A!(!;$/-)(;!DM>vDM>!?-]+;!&-A?;(Fi!U7#!)(8!$8;F!AB$T!(!@NNvWNN! ?-]+;!T-8&$T!$8!#B+!.$8-#$,=!!H89$,.(#-$8!#B(#!-A!8$#!)7,,+8#;F!*-A-U;+!T-#B-8!#B+! &-A?;(F!T-8&$T!)(8!U+!7?&(#+&!T-#B$7#!)(7A-8/!*-A7(;!/;-#)B+A=!!5B-A!#+)B8-C7+!-A! 9,+C7+8#;F!7A+&!UF!A),$;;-8/%A),++8!*-&+$!/(.+A=!!E$,#-$8A!$9!#B+!?;(F9-+;&!#B(#!(,+! )7,,+8#;F!$7#A-&+!$9!#B+!*-A-U;+!T-8&$T!(,+!7?&(#+&i!(8&!+*+8#7(;;F!A),$;;!-8#$!#B+!

M>

*-A-U;+!T-8&$T=!!5B+!/(.+!AQ+#)B!)$8A#(8#;F!7?&(#+A!#B+!?;(F9-+;&!j(B+(&k!$9!#B+! A),$;;-8/=

G$-6'."0*K0"(>'(4
^-&+$!&-A?;(F!#-.-8/!-A!U(A+&!(,$78&!#B+!8++&!#$!A)(8!(8!+;+)#,$8!U+(.!(),$AA!(! )(#B$&+%,(F!#7U+=!!17,-8/!?(,#!$9!#B-A!A)(8i!#B+!U+(.!-A #7,8+& $99!(8&!,+#7,8+&!#$! #B+!#$?!$9!#B+!A),++8!A$!#B(#!-#!-A U+!,+(&F!#$!&,(T!(!8+T!9,(.+!$9!&(#(=!!5B+!?+,-$&! $9!#-.+!#B(#!#B+!U+(.!-A #7,8+&!$99!(8&!U+-8/!,+#7,8+&!#$!#B+!#$?!$9!#B+!A),++8!-A!#B+! *+,#-)(;!U;(8Q-8/!-8#+,*(;=!!ZB-;+!.$&+,8!YI1!?(8+;A!&$8l#!7A+ +;+)#,$8!U+(.Ai!#B+! #-.-8/!9$,!#B(#!*+,#-)(;!U;(8Q-8/!-8#+,*(;!-A!A#-;;!U7-;#!-8#$!#B+!^63!*-&+$!A#(8&(,&=

<-8)+!8$!*-&+$!-A!$7#?7#!&7,-8/!#B+!*+,#-)(;!U;(8Q-8/!-8#+,*(;i!$7,!/(.+!A$9#T(,+!)(8! 7A+!#B-A!#-.+!#$!7?&(#+!#B+!A),++8!T-#B$7#!)(7A-8/!*-A7(;!/;-#)B+A!$8!#B+!A),++8=!!5B+! *+,#-)(;!U;(8Q-8/!-8#+,*(;!-A!8$.-8(;;F!M=WG>J.A=! H8!(!A-8/;+!*+,#-)(;!U;(8Q-8/! -8#+,*(;'
- 38!3,&7-8$lA!35.+/(!IEg!,788-8/!(#!MO:SL!)(8!+]+)7#+!>MiVO@!.()B-8+! )F);+A=!:(8F!3^2!-8A#,7)#-$8A!#(Q+!$8+!)F);+i!U7#!A$.+!#(Q+!>i!Wi!$,!@!)F);+A=
- 5B+!6(.+&7-8$lA!PM!)$?,$)+AA$,!)(8!+]+)7#+!OJiO@N!.()B-8+!)F);+A=!3;.$A#! (;;!PM!-8A#,7)#-$8A!#(Q+!$8+!)F);+i!U7#!A$.+![-8);7&-8/!.+.$,F!,+(&A!(8&! T,-#+A\!#(Q+!>!)F);+A=
- 5B+!3,&7-8$!)(8!7A+!-#A!<EH!U7A!)(8!#,(8A9+,!MiWG>!UF#+Ai!(AA7.-8/!#B+! .(]-.7.!<EH!);$)Q!A?++&=!<EH!&(#(!#,(8A9+,A!,+C7-,+!A+8&-8/!>!(&&,+AA!UF#+A! #$!A+#!7?!(!#,(8A9+,!?;7A!M!UF#+!?+,!&(#(!UF#+!,+(&!9,$.!$,!T,-##+8!#$!#B+! 6(.+&7-8$=
5B+!T$,Q!#B(#!)(8!U+!&$8+!-A!A7..(,-L+&!-8!5(U;+!W'!^+,#-)(;!K;(8Q-8/=

@,A5"(J*(F"&27',5(K5,4874L
^+,#-)(;!K;(8Q-8/ | M=WG>J.A
3,&7-8$!IEg | >MiVO@ )F);+A
PM!I$?,$)+AA$, | OJiO@N )F);+A
<EH!#,(8A9+, | MiWG> UF#+A

3;#B$7/B!-8!#B+$,F!(;;!#B,++!#F?+A!$9!()#-*-#-+A!)(8!U+!/$-8/!$8!(#!$8)+i!-8!?,()#-)+! #B+,+!(,+!A$.+!;-.-#(#-$8A=!!4-,A#i!#B+!3,&7-8$!IEg!-A!,+A?$8A-U;+!9$,!-8-#-(#-8/!<EH! #,(8A()#-$8A!(8&!Q++?-8/!#B+!<EH!U7A!U7AFi!A$!#B+!(.$78#!$9!(&&-#-$8(;!T$,Q!#B(#!-#! )(8!/+#!&$8+!(#!#B+!A(.+!-A!;-.-#+&=!<-.-;(,;Fi!TB-;+!#B+!PM!)$?,$)+AA$,!)(8!+]+)7#+! -#A!-8A#,7)#-$8A!-8&+?+8&+8#;F!$9!#B+!3,&7-8$i!+()B!<EH!,+(&!$,!T,-#+!$?+,(#-$8! A#+(;A!(!.()B-8+!)F);+!9,$.!#B+!PMi!,+&7)-8/!-#A!?+,9$,.(8)+!UF!(U$7#!>w=!!4-8(;;Fi! U+)(7A+!$9!#B+!T(F!#B(#!#B+!6(.+&7-8$lA!*-&+$%)$.?$A-#-$8!B(,&T(,+!T$,QAi!#B+! ()#7(;!#-.+!TB+,+!-#!-A!A(9+!#$!7?&(#+!#B+!A),++8!.(F!*(,F!UF!7?!#$!>w!9,$.!#B+! 8$.-8(;!9-/7,+=!!<++!#B+!&-A)7AA-$8!78&+,!2(A#+,!IB(A-8/ U+;$T!9$,!(!.$,+! )$.?,+B+8A-*+!&-A)7AA-$8=

MW

<&2&?2567'@&#25?",'A,"60567' 3,&7-8$!AQ+#)B+A!(8&!)$?,$)+AA$,!)$&+!)(8!7A+!#B+!^KY3_`!,+/-A#+,!#$!AF8)B,$8-L+! #B+-,!7?&(#+A!#$!#B+!*+,#-)(;!U;(8Q-8/!-8#+,*(;=!^KY3_` T-;;!,+(&!M!TB+8!#B+! 6(.+&7-8$!-A!/+8+,(#-8/!(!*+,#-)(;!U;(8Q-8/!A-/8(;i!$,!N!$#B+,T-A+=

5B+!61!;-U,(,F!?,$*-&+A!(!978)#-$8i!T(-#*U;(8Q[\!#B(#!T-;;!T(-#!9$,!^KY3_` #$!/$! 9,$.!N!#$!M!7A-8/!( TB-;+!
;$$?=!!5B+!/+8+,(;!A#,7)#7,+!
$9!(!/(.+!AQ+#)B!#B(#!7A+A!
T(-#*U;(8Q[\ -A!-;;7A#,(#+&! -8!<Q+#)B!W'!6(.+!Y$$?!
7A-8/!61''T(-#*U;(8Q[\ (#! #B+!,-/B#=!!gA-8/!#B-A!
978)#-$8!/7(,(8#++A!#B(#!
#B+!3,&7-8$!B(A!#B+!

.(]-.7.!(.$78#!$9!#-.+!#$!7?&(#+!#B+!A),++8'!-#!T(-#A!9$,!^KY3_`!#$!)B(8/+!9,$.! N!#$!M!U+9$,+!,+#7,8-8/=!!H9!F$7,!AQ+#)B!)(;;A!T(-#*U;(8Q[\!-8!#B+!.-&&;+!$9!(!*+,#-)(;! U;(8Q-8/!-8#+,*(;i!-#!T-;;!T(-#!9$,!#B+!8+]#!*+,#-)(;!U;(8Q-8/!-8#+,*(;i!AQ-??-8/!(8 +8#-,+!9,(.+i!#$!+8A7,+!#B(#!F$7,!AQ+#)B!B(A!#B+!97;;!#-.+!(*(-;(U;+=

ZB-;+!#B-A!(??,$()B!-A!A799-)-+8#!9$,!.(8F!/(.+!AQ+#)B+Ai!-#!-A!A$.+TB(#!T(A#+97;'! #B+!3,&7-8$!)(8!&$!8$#B-8/!+])+?#!,+A?$8&!#$!-8#+,,7?#A TB-;+!-#!-A!T(-#-8/ 9$,!#B+! *+,#-)(;!U;(8Q-8/ -8#+,*(;!#$!A#(,#=!!X8!#$?!$9!#B(#i!)$8#-87$7A!<EH!,+(&!)F);+A!7A+&!#$! ,+?+(#+&;F!)B+)Q!^KY3_`!A#+(;!(!9+T!.+.$,F!)F);+A!9,$.!#B+!)$?,$)+AA$,i!)(7A-8/! -#!#$!,78!A;-/B#;F!A;$T+,=!!5B-A!)(8!U+!(8!-AA7+!-9!F$7,!)$?,$)+AA$,!)$&+!&+?+8&A!$8! ?,+)-A+!#-.-8/ o9$, +](.?;+i!-9!F$7!(,+!(;A$!&$-8/!,(A#+,!)B(A-8/=!!

38$#B+,!T(F!$9!AF8)B,$8-L-8/!3,&7-8$!)$&+!T-#B!*+,#-)(;!U;(8Q-8/!-A!#$!B(*+! )$?,$)+AA$,!.-),$)$&+!#B(#!(;;$TA!#B+!PM!)$?,$)+AA$,!-8#+,,7?#!#B+!3,&7-8$!(#!#B+! A#(,#!$9!#B+!*+,#-)(;!U;(8Q-8/!-8#+,*(;=!!38!"""+](.?;+!AQ+#)B000!-A!AB$T8!(#!,-/B#=!! 5B-A!AQ+#)B!)(8!U+!+]#+8&+&!UF!(&&-#-$8!(&&-#-$8(;!)$?,$)+AA$,!)$&+!(9#+,!#B+! -8#+,,7?#!-A!-AA7+&!#B(#!T-;;!U+!+]+)7#+&!&7,-8/!*+,#-)(;!U;(8Q-8/=

"""#$%&$'!-8A+,#!-8#+,,7?#!AQ+#)B000

+"<6$-*15"<'(4
P7A#!(A!#B+!*-&+$!U+(.!8++&A!#$!U+!,+#7,8+&!#$!#B+!#$?!$9!#B+!A),++8!U+9$,+!A#(,#-8/! +()B!9,(.+i!-#!(;A$!8++&A!#$!U+!,+#7,8+&!#$!#B+!;+9#!A-&+!$9!#B+!A),++8!?,-$,!#$!+()B! ;-8+!$9!*-&+$=!!S$,-L$8#(;!U;(8Q-8/!-A!#B+!?+,-$&!$9!#-.+!#B(#!#B+!*-&+$!A-/8(;!-A! #7,8+&!$99!TB-;+!-#!-A!U+-8/!,+#7,8+&!#$!#B+!;+9#!A-&+!$9!#B+!A),++8=!!<-8)+!#B+,+!(,+! B78&,+&A!$9!;-8+A!?+,!9,(.+i!#B+!B$,-L$8#(;!U;(8Q-8/!#-.+!$9!@=JsA -A!.7)B!AB$,#+,! #B(8!#B+!*+,#-)(;!U;(8Q-8/!-8#+,*(;= H9!#B+!()#-$8!#$!U+!#(Q+8!-A!U(A+&!$8!#B+!)7,,+8#! ;-8+i!#B+8!#B+!#+)B8-C7+!-A!Q8$T8!(A!j,(A#+,!)B(A-8/k=!!4$,!+](.?;+i!(!?,$/,(.!)$7;&! )B(8/+!#B+!U()Q/,$78&!)$;$,!U(A+&!$8!#B+!)7,,+8#!;-8+=!!

loop()
{
// Code that does game calculations here. waitvblank()
// Code that updates the Gameduino screen here. }

/8"2'9(J*(;,<"(6$$?(%#74L(;3**.,72MA5,48NO

M@

S$T+*+,i!#B+!6(.+&7-8$!&$+A8l#!$7#?7#!^63!*-&+$!&-,+)#;F=!!H8A#+(&i!+()B!?-]+;!-A! &$7U;+&!B$,-L$8#(;;F!(8&!*+,#-)(;;F=!!5$!&$!#B-Ai!#B+!6(.+&7-8$!)$.?$A+A!+()B!;-8+! $9!*-&+$!-8#$!$8+!$9!#T$ U799+,A UF!U7-;&-8/!-#!7?!9,$.!#B+!U()Q/,$78&!)$;$,i! )B(,()#+,!/,(?B-)Ai!(8&!A?,-#+A=!!X8)+!#B+!;-8+!-A!U7-;#!7?!-8!#B+!U799+,i!-#!-A!$7#?7#!#$! #B+!&-A?;(Fi!(8&!#B+!$#B+,!U799+,!-A!(*(-;(U;+!#$!)$.?$A+!#B+!8+]#!;-8+=!5B+! 6(.+&7-8$!$7#?7#A!+()B!?-]+;!#T-)+!#$!&$7U;+!#B+-,!A-L+!B$,-L$8#(;;Fi!(8&!+()B!;-8+! -A!$7#?7#!#T-)+!#$!&$7U;+!-#!*+,#-)(;;F=!!5B+,+!-A!(!U,-+9!?(7A+!#$!AT-#)B!U799+,A!(8&! AF8)B,$8-L+!#B+!#-.-8/!$9!#B+!)$.?$A-#$,!U+9$,+!#B+ 6(.+&7-8$!U+/-8A!)$.?$A-8/! #B+!8+]#!;-8+=!!

<$i!-8A#+(&!$9!(!A#(8&(,&!^63!B$,-L$8#(;!,+#,()+i!#B+!6(.+&7-8$!B(A!(!A.(;;!#-.+! T-8&$T!U+#T++8 )$.?$A-8/!A7))+AA-*+!;-8+A!$9!#B+!&-A?;(F=!17,-8/!#B-A!T-8&$Ti!-#! -A!A(9+!#$!7?&(#+!$8%A),++8!-89$,.(#-$8i!A-8)+!8$!*-&+$!)$.?$A-#-$8!-A!/$-8/!$8=!! <-8)+!+()B!;-8+!$9!*-&+$!)(8!#(Q+!(!&-99+,+8#!(.$78#!$9!#-.+!#$!)$.?$A+&i!U(A+&! .(-8;F!$8!#B+!87.U+,!$9!A?,-#+A!?,+A+8#!-8!#B(#!;-8+i!#B+!A-L+!$9!#B+!T-8&$T!)(8!U+! &-99+,+8#!9,$.!;-8+!#$!;-8+'!#B+!T-8&$T!-A!(#!;+(A#!@D!PM!)F);+A!;$8/i!(8&!)(8!U+!(A!;$8/! (A!MOGG!)F);+A= 5B+!#-.+!#(Q+8!&+?+8&A!$8!#B+!87.U+,!$9!A?,-#+A!#B(#!.7A#!U+! )$.?$A-#+&!$8#$!#B+!;-8+'!#B+!.-8-.7.!#-.+!$9!@D!)F);+A!)$,,+A?$8&A!#$!#B+! .(]-.7.!$9!VO!A?,-#+A!?+,!;-8+=!!

5B+,+!-A!8$!&-,+)#!+C7-*(;+8#!#$!#B+!VBLANK ,+/-A#+,!#$!-8&-)(#+!TB+8!-#!-A!A(9+!#$! ?+,9$,.!7?&(#+Ai!U7#!#B+,+!3> )$?,$)+AA$,%$8;F!,+/-A#+,![YLINEi!(#!N]JNNN\!#B(#! -8&-)(#+A!#B+!)7,,+8#!B$,-L$8#(;!;-8+!87.U+,=!5B+!6(.+&7-8$!-8),+.+8#A YLINE -..+&-(#+;F!(9#+,!#B+!,-/B#.$A#!?-]+;!$9!( ;-8+!-A )$.?$A+&=!!PM!?,$/,(.A!#B(#!T(-#! 9$,!YLINE #$!)B(8/+!(,+!/7(,(8#++&!#$!B(*+!(#!;+(A#!@D!)F);+Ai!(8&!?$AA-U;F!;$8/+,i! #$!.(Q+!)B(8/+A!#$!#B+!*-&+$!&(#(=

YLINE -A!(!)$?,$)+AA$,%$8;F!,+/-A#+,=!!5B+,+!-A!8$!+C7-*(;+8# (*(-;(U;+!#$!#B+! 3,&7-8$!#B(#!-8&-)(#+A!TB+8!B$,-L$8#(;!U;(8Q-8/!-A!#(Q-8/!?;()+!o (8&!8$#!+8$7/B! #-.+!#$!#(Q+!(&*(8#(/+!$9!-#!+*+8!-9!#B+,+!T+,+'!+*+8!(!A-8/;+%UF#+!<EH!#,(8A9+,! ,+C7-,+A!MJN!PM!)F);+Ai!A$!#B+!T-8&$T!.(F!T+;;!U+!);$A+&!U+9$,+!#B+!&(#(!)$7;&!U+! T,-##+8= 5B+!)$?,$)+AA$,!)$7;&!-8#+,,7?#!#B+!3,&7-8$!TB+8!(!)B(8/+!-8!YLINE -A! &+#+)#+& 7A-8/!(!?,$/,(.!A-.-;(,!#$!#B+!$8+!&+A),-U+&!(U$*+!9$,!*+,#-)(;!U;(8Q-8/i! U7#!#B+,+!-A!A$!;-##;+!#-.+!(*(-;(U;+!#B(#!-#!T$7;&!U+!)B(;;+8/-8/!#$!T,-#+!(8!-8#+,,7?#! A+,*-)+!,$7#-8+!#B(#!&-&!(8F#B-8/!7A+97;=

5B+!U+A#!(??,$()B!9$,!-A!#$!T,-#+!(!)$?,$)+AA$,!,$7#-8+!#B(# &+#+)#A!(!)B(8/+!-8!#B+! YLINE ,+/-A#+, &$+A!#B+!8+)+AA(,F!T$,Q=!5B+,+!-A!8$!-8&-)(#-$8!TB+8!*-&+$! )$.?$A-#-8/!,+A7.+Ai!A$!)$?,$)+AA$,!?,$/,(.A!#B(#!7?&(#+!#B+!A),++8!&7,-8/!#B-A! T-8&$T!AB$7;&!&$!#B+-,!T$,Q!C7-)Q;F= 5B+!""+](.?;+!AQ+#)B00!#$!#B+!,-/B#! -;;7A#,(#+A!,(A#+,%)B(A-8/!#+)B8-C7+A!#B(#!.(8-?7;(#+!#B+!K6IXYX2!,+/-A#+,!#$! ),+(#+!(!AQF!(8&!/,$78&!U()Q/,$78&!+99+)#=

"""#$%&$'!-8A+,#!,(A#+,%)B(A-8/!+](.?;+000

MD

BC8D='@",5$52-
ZB+8!)$&-8/!PM!,$7#-8+A!#B(#!T$,Q!T-#B!cYH_Ri!,+.+.U+,!#B(# #B+ *(;7+!$9!cYH_R!-A! 78&+9-8+&!&7,-8/!#B+!*+,#-)(;!U;(8Q-8/!-8#+,*(;=!!I$?,$)+AA$,!)$&+!)(8!)$78#!$8! cYH_R!/$-8/!9,$.!N!#$!>VV!&7,-8/!#B+!*-A-U;+!?$,#-$8!$9!#B+!&-A?;(Fi!(8&!(!*(;7+! /,+(#+,!#B(8!>VV!&7,-8/!*+,#-)(;!U;(8Q-8/=!S$T+*+,i!&7,-8/!*+,#-)(;!U;(8Q-8/!#B+! cYH_R!,+/-A#+,!.(F!#(Q+!$8!78?,+&-)#(U;+!(8&!(,U-#,(,F!*(;7+A!(U$*+!>VV=!4$,! +](.?;+i!-# .(F!)$78#!9,$.!N!#$!>VV!&7,-8/!#B+!*-A-U;+!9,(.+i!(8&!#B+8!)$78#!WNNi! WNMi!WN>i!WNWi!@J>i!@JWi!+#)=!TB-;+!#B+!&-A?;(F!-A!U;(8Q+&!9$,!*+,#-)(;!,+#,()+=
@$#1)00"+'!*)05$43

"""#$%&$'!&+A),-U+!B$T!#$!7A+!A?,-#+A!#$!.(Q+!(!U-#.(?!/,(?B-)A!9-+;&000

MO

I"-%?"-$*I".>'(4
1'-.&'6*K)"-%*/)%','."6')(<

!)1"+7$%/'B/+$C$4)#$/%3
5B+!6(.+&7-8$!U$(,&!-A!&+A-/8+&!#$!7A+!3,&7-8$!?-8!V!(A!#B+!A+;+)#![<RY!$,!<<\!?-8! 9$,!<EH!)$..78-)(#-$8=!!S$T+*+,i!#B+!6(.+&7-8$!.(F!8++&!#$!)$%+]-A#!T-#B!$#B+,! B(,&T(,+!#B(#!7A+A!?-8!V!9$,!-#A!$T8!?7,?$A+A=!!H#!B(A!U++8!&+A-/8+&!#$!+8(U;+!#B-A! #$!U+!)B(8/+&!-9!8++&+&!UF!)7##-8/!(!#,()+!$8!#B+!)-,)7-#!U$(,&!(8&!-8A#(;;-8/!(! h7.?+,!T-,+=!!

38F!(*(-;(U;+!&-/-#(;!?-8!)(8!U+!7A+&!(A!#B+!8+T!<EH!<RY!?-8i!U7#!8$#+!#B(#!&-/-#(;! ?-8A!MMi!M>i!(8&!MW!(,+!7A+&!UF!#B+!6(.+&7-8$lA!<EH!-8#+,9()+i!(8&!&-/-#(;!?-8!>!.(F! (;A$!U+!-8!7A+!UF!A$.+!AQ+#)B+A=!!5$!,+)$89-/7,+!#B+!6(.+&7-8$!#$!7A+!(!&-99+,+8#! ?-8!9$,!<EH!<RY'

M= K,+(Q!#B+!)-,)7-#!U$(,&!#,()+!(#!;$)(#-$8!b $8!#B+!?B$#$/,(?Bi!(8&

>= <$;&+,!(!h7.?+,!T-,+!9,$.!#B+!#B,$7/B%B$;+!(#!;$)(#-$8!3 #$!#B+!8+T!<EH!<RY! ?-8m!#B+!+]()#!?-8!T-;;!&+?+8&!$8!F$7,!AFA#+.lA!B(,&T(,+!)$89-/7,(#-$8=

"""5$%&$'!-8A+,#!?B$#$!B+,+000

### D/:3#$4E'(5$".+'B/+$C$4)#$/%3

5B+!<?(,Q478!h$FA#-)Q!AB-+;&!-A!(A!);$A+!(A!(8F#B-8/!/+#A!#$!(!A#(8&(,&!/(.-8/!-8?7#! &+*-)+!9$,!#B+!3,&7-8$=!!4,$.!#B+!?$-8#!$9!*-+T!$9!7A-8/!-#!T-#B!(!6(.+&7-8$i!-#!B(A! $8+!A-/8-9-)(8#!&,(TU()Q'!#B+!h$FA#-)Q!?7ABU7##$8!-A!(##()B+&!#$!3,&7-8$!&-/-#(;!?-8! >=!!5B-A!.(F!U+!(8!-AA7+!U+)(7A+!?-8!>!)(8!U+!7A+&!UF!6(.+&7-8$!)$?,$)+AA$,!)$&+! #$!-8#+,,7?#!#B+!3,&7-8$i!$,!?-8 >!)(8!U+!7A+&!#$!())+AA!#B+!6(.+&7-8$lA!$8U$(,&! 4;(AB!.+.$,F=!!Y7)Q-;Fi!-#!-A!,+;(#-*+;F!+(AF!#$!.$&-9F!#B+!h$FA#-)Q!AB-+;&!#$!,+.(?! #B-A!U7##$8!#$!(!&-99+,+8#!-8?7#=!!Z+!,+)$..+8&!,+.(??-8/!#B+!-8?7#!#$!?-8!G!T-#B! #B+!9$;;$T-8/!?,$)+&7,+'

M= K,+(Q!#B+!)-,)7-#!U$(,&!#,()+!(#!;$)(#-$8!b -8!#B+!?B$#$/,(?Bi!(8&

>= <$;&+,!(!h7.?+,!T-,+!9,$.!;$)(#-$8!K #$!3,&7-8$!&-/-#(;!?-8!G!(#!;$)(#-$8!I=

"""#$%&$'!-8A+,#!?B$#$!B+,+000

MG

## L)MA6MN)&-<$0,*B-)O$.6<

<%07#3')%+'=/%#*/.."*3

"""#$%&$'!-89$,.(#-$8!(U$7#!U7-;&-8/!F$7,!$T8!)$8#,$;;+,000

F%4./37*"3')%+'=)3"3

"""#$%&$'!-89$,.(#-$8!(U$7#!U7-;&-8/!F$7,!$T8!U$]!$,!)(A+000

MJ

!"#$%&'()*H$.5('."0*+$,$-$(.$ I"-%?"-$*A(6$-,".$
3;#B$7/B!&+A-/8+&!(A!(8!3,&7-8$!AB-+;&i!#B+!B(,&T(,+!-A!;(,/+;F!A+;9%)$8#(-8+&i!(8&! )(8!U+!-8#+,9()+&!T-#B!(8F!.-),$?,$)+AA$,!$,!)$.?7#+,!AFA#+.!#B(#!)(8!?,$*-&+! ?$T+,!(8&!(!<EH!-8#+,9()+=!38!(&&-#-$8(;!$7#?7#!9,$.!#B+!6(.+&7-8$!-A!)$88+)#+&!#$! 3,&7-8$!&-/-#(;!?-8!>!9$,!7A+!(A!(8!-8#+,,7?#!9,$.!#B+!6(.+&7-8$!#$!#B+!B$A#!AFA#+.=! 5B+A+ )$88+)#-$8A!(,+!A7..(,-L+&!-8!5(U;+!@'!S$A#!H8#+,9()+=

@,A5"(P*(+$#2(=42"&1,'"
3,&7-8$!E-8 | 478)#-$8
6_1 | <-/8(;!6,$78&
xW=W^ | <7??;F!^$;#(/+i!W=W^1I
xD^ | <7??;F!^$;#(/+i!D=N^1Ii!>W.3
> | H8#+,,7?#![$?#-$8(;\
V | <EH!<RY!$,!<<
MM | <EH!:X<H
M> | <EH!:H<X
MW | <EH!<I`

### G)*+H)*"'=/10)#$I$.$#:

5B+!6(.+&7-8$!-A!A?+)-9-)(;;F!-8#+8&+&!9$,!7A+!T-#B!#B+!3,&7-8$!g8$=!!H#!-A! ?BFA-)(;;F!(8&!+;+)#,-)(;;F!)$.?(#-U;+!T-#B!.$A# 3,&7-8$!U$(,&A!A7)B!(A!#B+! -8);7&-8/!#B+!:+/(!>DONi!17+.-;(8$*+i!:+/(i!(8&!1-+)-.-;(=!35.(/(MOJ%U(A+&! U$(,&A!;-Q+!1-+)-.-;(!(8&!+(,;-+,!,+*-A-$8A!$9!#B+!17+.-;(8$*+!.(F!8$#!B(*+!+8$7/B! 4;(AB!.+.$,F!$,!<#(#-)!23:![<23:\!9$,!.(8F!6(.+&7-8$!AQ+#)B+A!?,+A+8#+&!-8! #B-A!.(87(;=!3,&7-8$%&+,-*+&!&+A-/8A!A7)B!(A!#B+!4,++&7-8$!(8&!<+++&7-8$!#B(#! -8)$,?$,(#+!(8!35.+/(W>Ji!35.+/(M>JNi!$,!35.+/(>DON!AB$7;&!(;A$!T$,Q!T-#B! #B+!6(.+&7-8$=!!X#B+,!&+*+;$?.+8#!U$(,&A!T-#B!3,&7-8$%)$.?(#-U;+!B+(&+,A!)(8! (;A$!A7??$,#!#B+!6(.+&7-8$m!A$.+!$9!#B+A+!;-Q+!#B+!_+#&7-8$i!4Re!1$.-8$i!$,!4Re! E(8&(!-8)$,?$,(#+!)$8A-&+,(U;F!.$,+!)$.?7#(#-$8(;!?$T+,!#B(8!#B+!A#(8&(,&! 3,&7-8$!?;(#9$,.=!!5B+!A#(#7A!$9!Q8$T8!B$A#!U$(,&A!9$,!#B+!6(.+&7-8$!-A!?,+A+8#+&! -8!5(U;+!D'!S(,&T(,+!I$.?(#-U-;-#F!Y-A#=

@,A5"(Q*(+,&-.,&"(R$<?,27A7572S(67#2
S$A#!K$(,& | | | I$.?(#-U-;-#F!(8&!<7??$,#
_(.+ | E,$)+AA$, | :+.$,F | | S(,&T(,+ | <$9#T(,+ | 3)#-*+ | _$#+
3,&7-8$!g8$ | MO:SL!35.+/(W>J | W>f> | | c+A | c+A | c+A
3,&7-8$!:+/(>DON | MO:SL!35.(/(>DON | >DOfJ | | c+A | c+A | c+A
3,&7-8$!17+.-;(8$*+ | MO:SL!35.+/(W>J | W>f> | | c+A | c+A
3,&7-8$!17+.-;(8$*+ | MO:SL!35.+/(MOJ | MOfM | | c+A | :(FU+ | | M
3,&7-8$!1-+)-.-;( | MO:SL!35.+/(MOJ | MOfM | | c+A | :(FU+ | | M
3,&7-8$!:+/( | MO:SL!35.+/(M>JN | M>JfJ | | c+A | c+A
4,++&7-8$ *>=> | MO:SL!35.+/(W>J | W>f> | | | | | >
<++&7-8$ *>=> | MO:SL!35.+/(W>J | W>f> | | | | | >

MV

S$A#!K$(,& | | | I$.?(#-U-;-#F!(8&!<7??$,#
_(.+ | E,$)+AA$, | :+.$,F | | S(,&T(,+ | <$9#T(,+ | 3)#-*+ | _$#+
Y+(9Y(UA!:(?;+ | G>:SL!32:!I$,#+] | M>Nf>N | | c+A | c+A | c+A | @
_+#&7-8$ | @J:SL!32:G | M>VfON | | | _$ | | W
_+#&7-8$!E;7A | @J:SL!32:G | O@f>J | | | _$ | | W
4Re!1$.-8$ | G>:SL!32:G | M@JfO> | | | _$ | | W
4Re!E(8&( | G>:SL!32:G | M@JfO> | | | _$ | | W
4Re!E(8&(!HH | G>:SL 32:G | M@JfO> | | | _$ | | W
S$A#!K$(,&'!_(.+!$9!#B+!B$A#!U$(,&= E,$)+AA$,'!IEg!A?++&!(8&!&+A-/8(#-$8i!?,$/,(.![4;(AB\!(8&!,+(&fT,-#+![<23:\!.+.$,F!-8!QUF#+A= I$.?(#-U-;-#F!(8&!<7??$,#'!<#(#7A!$9!#B+!6(.+&7-8$!$8!+()B!?;(#9$,.i!A++!U+;$T=
!"#$%"#& E 6=<>3E",'"0$ &,&E1#3E",'E-/."13G3,31<'%31='1=&':"/&$;30-T
- c+A!t!47;;F!)$.?(#-U;+i!)$88+)#A!#$!B$A#!U$(,&!(A!(!AB-+;&
- :(FU+!t!I(8!U+!.(&+!#$!T$,Q!UF!.$&-9F-8/!U$(,&A!$,!,788-8/!T-,+A
- _$!t!1$+A!8$#!T$,Q
- K;(8Q!t!_$#!#+A#+&i!-89$,.(#-$8!8++&+&=
./F2%"#& [ ?-/."13G3,31<'%31='>-;#E&'E-$&'30E,;$&$'30'1=3>'G--PT
- c+A!t!I$.?(#-U;+i!97;;!61!;-U,(,F!A7??$,#!(8&!(;;!AQ+#)B+A!T$,Q
- :(FU+!t!<$.+!AQ+#)B+A!.(F!8$#!T$,Q!&7+!#$!.+.$,F!$,!#-.-8/!)$8A#,(-8#Ai! A++!8$#+A
- _$!t!_$#!3,&7-8$!A$7,)+%)$&+!)$.?(#-U;+i!A++!8$#+A=
- K;(8Q!t!_$#!#+A#+&i!-89$,.(#-$8!8++&+&
(?25G& [ A+"3,"G3,31<'-I':*',3G#"#<'"0$'"E13+&'E-//;031<'>;..-#1T
- c+A!t!^+,F!()#-*+!)$..78-#F!(8&!A7??$,#+&!61!;-U,(,F
- <$.+!t!Y-.-#+&!()#-*-#F!U7#!A$.+!T$,Q!-A!U+-8/!&$8+i!A++!8$#+A
- W,&!E(,#F t!3)#-*+!&+*+;$?.+8#!)$..78-#F!7A-8/!(!W,&%?(,#F!61!;-U,(,Fi!A++! 8$#+A
- _$!t!_$!()#-*-#F!(8&!8$!;-U,(,Fi!?,$U(U;F!U+)(7A+!$9!-8)$.?(#-U-;-#F
- K;(8Q!t!g8Q8$T8i!-89$,.(#-$8!8++&+&=
D/2& [ M<>1&/7>.&E3I3E'E-/."13G3,31<'0-1&>T
M= 5B+A+!AFA#+.A!(,+!.+)B(8-)(;;F!(8&!+;+)#,-)(;;F!)$.?(#-U;+i!U7#!;-.-#+&! ?,$/,(.!A#$,(/+!(8&!<23:!.(F!?,+*+8#!.(8F!AQ+#)B+A!9,$.!T$,Q-8/=!!! g8#+A#+&!(#!#B-A!#-.+=
>= K+;-+*+&!#$!U+!97;;F!)$.?(#-U;+i!U7#!78#+A#+&!(#!#B-A!#-.+=
W= K$(,&A!U(A+&!$8!=_+#!:-),$!4,(.+T$,Q!AB$7;&!U+!B(,&T(,+!)$.?(#-U;+m! 78#+A#+&!(8&!8$!)$..78-#F!$,!;-U,(,F!A7??$,#!(#!#B-A!#-.+=
@= K$(,&A!U(A+&!$8!3,&7-8$fE,$)+AA-8/!H1R!T-#B!32:!),$AA%)$.?-;+,=!! <$9#T(,+!-A A$7,)+%)$&+![U7#!8$#!$Uh+)#%)$&+\!)$.?(#-U;+=
(9<'=/117%$4)#$/%
5B+!6(.+&7-8$lA!?,$/,(..-8/!-8#+,9()+!-A!(!W>%Q-;$UF#+!(&&,+AA!A?()+!#B(#!-A! (*(-;(U;+!#$!#B+!B$A#!)$.?7#+,!*-(!(8!<EH!-8#+,9()+=!!5B+!6(.+&7-8$!+]?+)#A!&(#(!#$! U+!A+8#!:<K!9-,A#![1X21tN\i!7A-8/!<EH!:$&+!N!9$,!(!);$)Q!A-/8(;!#B(#lA!;$T!TB+8!-&;+! [1X21tN\!(8&!A(.?;+&!$8!#B+!,-A-8/!+&/+![IES3tN\=!!ZB-;+!#B+!6(.+&7-8$!AB$7;&!

>N

U+!(U;+!#$!Q++?!?()+!T-#B!(8!<EH!);$)Q!7?!#$!MO=G:SLi!-#!B(A!$8;F!U++8!#+A#+&!#$!#B+! 3,&7-8$lA!.(]-.7.!);$)Q!A?++&!$9!J:SL=

Y';-"-3*U&22)-6
5B+!3,&7-8$!+8*-,$8.+8#!-8);7&+A!(!
A#(8&(,&!;-U,(,F!9$,!B(8&;-8/!<EH! )$..78-)(#-$8A=!!<Q+#)B!@'!<EH! H8-#-(;-L(#-$8 AB$TA!#B+!3,&7-8$!)$&+!#$!
A+#!7?!#B+!<EH!;-U,(,F!#$!)$..78-)(#+!
T-#B!(!6(.+&7-8$=!!5B+!61!;-U,(,F!9$,! 3,&7-8$!?,$*-&+A!)$8*+8-+8#!T,(??+,!978)#-$8A!(,$78&!#B+!<EH!;-U,(,F!9$,!)$..$8! 6(.+&7-8$!$?+,(#-$8A=

=06$-("6$*UBA*=%%-$<<
H5$ !"#$%&'()*;)"-%*'<*%$<'4($%*6)*&<$ =-%&'()*2'(*Q*"<*65$*

## <$0$.6*ZUWY*)-*UU[*2'(*,)-*UBA*.)##&('."6')(@**I)?$E$-\*65$*

;)"-%*5"<*;$$(*%$<'4($%*6)*$(";0$*65'<*6)*;$*.5"(4$%*',*($$%$%]* ,)-*$^"#20$\*6)*.)M$^'<6*?'65*)65$-*5"-%?"-$*65"6*&<$<*2'(*Q*,)-* '6<*)?(*2&-2)<$<@**U$$*1'-.&'6*K)"-%*/)%','."6')(<
6(.+&7-8$!:$&-9-)(#-$8A $8!?(/+!MO -8!#B+!S(,&T(,+!S()Q-8/!A+)#-$8!9$,!&+#(-;+&! -8A#,7)#-$8A=!!
/$#)-3*/"2
5B+A+!.+.$,F!.(?A!?,+A+8#!#B+!6(.+&7-8$!(&&,+AA!A?()+!-8!(A)+8&-8/!$,&+,!9,$.! ;$T+A#!(&&,+AA!#$!B-/B+A#!(&&,+AAm!#B+!)B(,#A!AB$T!(&&,+AA+A!-8),+(A-8/ 9,$.!;+9#!#$! ,-/B#!(8&!#$?!#$!U$##$.= 5B-A!.+(8A!#B(#!3<IHH!)B(,()#+,!A#,-8/A!(,+!?,+A+8#+&!-8!#B+! $,&+,!#B(#!#B+F!T$7;&!U+!,+(&!(A!R8/;-AB!#+]#= 4$,!+](.?;+i!#B+!A#,-8/!jSRYYX! ZX2Y1k!T$7;&!U+ T,-##+8!#$!#B+!7??+,%;+9#!)$,8+,!$9!#B+!)B(,()#+,!?-)#7,+!(A'
3&&,+AA | KF#+!X99A+#!(8&!:+.$,F!I$8#+8#A
[B+]\ | [&+)\ | +0 | +1 | +2 | +3 | +4 | +5 | +6 | +7 | +8 | +9 | +10
0x0000 | 0 | 0x48 | 0x45 | 0x4C | 0x4C | 0x4F | 0x20 | 0x57 | 0x4F | 0x52 | 0x4C | 0x44
| | H | E | L | L | O | | W | O | R | L | D
S$T+*+,i!TB+8!A#$,-8/!MO%U-#!U-8(,F!87.U+,Ai!#B+!6(.+&7-8$!-A!(!;-##;+%+8&-(8! &+*-)+'!MO%U-#!*(;7+A!(,+!A#$,+&!T-#B!#B+!;+(A#%A-/8-9-)(8#!UF#+!-8!#B+!;$T+,!(&&,+AA= 4$,!+](.?;+i!#B+!MO%U-#!*(;7+!N]>4JK!T$7;&!U+!A#$,+&!-8!#B+!>%UF#+!K6aIXYX2! ,+/-A#+,!A#(,#-8/!(#!N]>JNR!(A'
<F.U$; | | 3&&,+AA | Y+8/#B | KF#+!X99A+#!(8&!I$8#+8#A
| | [B+]\ | [&+)\ | [B+]\ | [&+)\ | +0 | +1
BG_COLOR | RW | 0x280E | 10254 | 0x2 | 2 | 0x8B | 0x2F

#define GAMEDUINO_SS 9

pinMode(GAMEDUINO_SS,OUTPUT); SPI.begin();
SPI.setClockDivider(SPI_CLOCK_DIV2); SPI.setBitOrder(MSBFIRST); SPI.setDataMode(MODE0);

/8"2'9(P*(/T=(=4727,57>,27$4

>M

:(8F!6(.+&7-8$!.+.$,F!;$)(#-$8A!(,+!U-#%.(??+&i!T-#B!A?+)-9-)!U-#A!$,!/,$7?A!$9! U-#A!T-#B-8!(!T$,&!B(*-8/!&-A#-8)#!978)#-$8A= ZB+8!.(??-8/!(!UF#+!$,!T$,&i!#B+! -8&-*-&7(;!U-#A!(,+!?,+A+8#+&!-8!(A!&-/-#A!$9!(!87.U+,i!T-#B!#B+!.$A#%A-/8-9-)(8#!U-#! #$!#B+!9(,#B+A#!;+9#!(8&!#B+!;+AA%A-/8-9-)(8#!U-#A!#$!#B+!,-/B#=!H8&-*-&7(;!U-#A!T-#B-8!(! .7;#-%U-#!9-+;&!(,+!-8&-)(#+&!T-#B!A7UA),-?#Ai!T-#B!L+,$!U+-8/!#B+!;+(A#%A-/8-9-)(8#!U-#! (8&!B-/B+,!87.U+,A!-8&-)(#-8/!?,$/,+AA-*+;F!.$,+!A-/8-9-)(8#!U-#A=!4$,!+](.?;+i!KN -A!#B+!;+(A#%A-/8-9-)(8#!U-#!-8!9-+;&!Ki!TB-;+!KO -A!#B+!G#B (8&!.$A#%A-/8-9-)(8#!U-#!-8!(!G% U-#!9-+;&=!
!)1"+7$%/'B"1/*:'B)0

@,A5"(E*(;,<"-%74$(U"<$&S(U,?
<F.U$; | | 3&&,+AA | Y+8/#B | E7,?$A+
RAM_PIC | RW | 0x0FFF 0x0000 | 4096 | R9,&,'2"&(T7'2%&"V()B(,()#+,%.(??+&!?;(F9-+;& 6,-&!$9!O@vO@!M%UF#+!)B(,()#+,A
RAM_CHR | RW | 0x1FFF 0x1000 | 4096 | R9,&,'2"&(K72<,?#V(>DO!)B(,()#+,A JvJ ?-]+;Ai!>!U-#A!?+,!?-]+;![MO!UF#+Af)B(,()#+,\
RAM_PAL | RW | 0x27FF 0x2000 | 2048 | R9,&,'2"&(T,5"22"#V(>DO!?(;+##+A!$9!@!)$;$,A!+()B 326KMDDD 9$,.(#![>!UF#+Af)$;$,\
IDENT | R | 0x2800 | 1 | ;,<"-%74$(=3V (;T(FA!,+(&A!N]O1
REV | R | 0x2801 | 1 | +,&-.,&"(!"M7#7$4V (;T(FA!,+(&A!N]MN
FRAME | R | 0x2802 | 1 | F7-"$(I&,<"(R$%42"&
VBLANK | R | 0x2803 | 1 | F"&27',5(K5,4874L I5,LV(M!&7,-8/!*+,#-)(;!U;(8Q
SCROLL_X | RW | 0x2805 0x2804 | 2 | /'&$55(Wi!)B(,()#+,!?-)#7,+!B$,-L$8#(;!A),$;; <),$;;!$99A+#i!N!#$!DMM!?-]+;A
SCROLL_Y | RW | 0x2806 0x2807 | 2 | /'&$55(Xi )B(,()#+,!?-)#7,+!*+,#-)(;!A),$;; <),$;;!$99A+#i N!#$!DMM!?-]+;A
JK_MODE | RW | 0x2808 | 1 | /?&72"(YZ[(U$-"i!N!#$!&-A(U;+i!M!#$!+8(U;+
J1_RESET | RW | 0x2809 | 1 | R$?&$'"##$&(!"#"2V(M!#$!,+A+#!(8&!B(;#i!N!#$!,78
SPR_DISABLE | RW | 0x280A | 1 | /?&72"(37#,A5"V(M!#$!&-A(U;+!A?,-8#Ai!N!#$!+8(U;+
SPR_PAGE | RW | 0x280B | 1 | /?&72"(T,L"(/"5"'2V(N!9$,!N]WNNNi!M!9$,!N]W@NN
IOMODE | RW | 0x280C | 1 | T74(0(=ZH(U$-"V(N]NNt&-A(U;+i!N]@Dt<EHi!N]@3tPM
| R | 0x280D | 1 | \4%#"-(!"L7#2"&(9$,!97#7,+!7A+i!(;T(FA!,+(&A!N
BG_COLOR | RW | 0x280F 0x280E | 2 | K,'8L&$%4- R$5$&V(9$,!#,(8A?(,+8#!?;(F9-+;&!?-]+;A 326KMDDD 9$,.(#i!B-/B![(;?B(\!U-#!-A!-/8$,+&
SAMPLE_L | RW | 0x2811 0x2810 | 2 | G%-7$(/,<?5"V(;+9#!)B(88+; MO%U-#!A-/8+&!(7&-$!A(.?;+!*(;7+
SAMPLE_R | RW | 0x2813 0x2812 | 2 | G%-7$(/,<?5"V(,-/B#!)B(88+; MO%U-#!A-/8+&!(7&-$!A(.?;+!*(;7+
RING_MOD | RW | 0x2814 | 1 | !74L(U$-%5,2$&i!*$-)+!7A+&!9$,!.$&7;(#-$8i!(99+)#A! (;;!;$T+,%87.U+,+&!*$-)+Am!O@![&+9(7;#\!#$!&-A(U;+=
| R | 0x281D 0x2815 | 9 | \4%#"-(!"L7#2"&#V(,+A+,*+&!9$,!97#7,+!7A+ 3;T(FA!,+(&A!N
SCREENSHOT_Y | RW | 0x281F 0x281E | 2 | /'&""4#9$2(674"(/"5"'2V(N%WMM <+;+)#A!,(A#+,!;-8+!#$!;$(&!-8#$!A),++8AB$#!U799+,
| R | 0x283F 0x2820 | 32 | \4%#"-(!"L7#2"&#V(,+A+,*+&!9$,!97#7,+!7A+ 3;T(FA!,+(&A!N
PALETTE16A/B RAM_SPRPAL16 | RW | 0x287F 0x2840 | 64 | /?&72"(T,5"22"()EV(> ?(;+##+A![3yK\i!MO!)$;$,A +()B 326KMDDD 9$,.(#![>!UF#+Af)$;$,\

>>

<F.U$; | | 3&&,+AA | Y+8/#B | E7,?$A+
PALETTE4A/B RAM_SPRPAL4 | RW | 0x288F 0x2880 | 16 | /?&72"(T,5"22"(Pi!> ?(;+##+A![3yK\i @!)$;$,A +()B 326KMDDD 9$,.(#![>!UF#+Af)$;$,\
COMM | RW | 0x28BF 0x2890 | 48 | R$?&$'"##$&(R$<<%47',27$4#(K5$'8 <?+)-9-)!7A+!#$!U+!&+#+,.-8+&!UF!#B+!?,$/,(..+,
| | 0x28FF 0x28C0 | 64 | \4%#"-(G--&"##(/?,'" 3;T(FA!,+(&A!N
COLLISION | R | 0x29FF 0x2900 | 256 | /?&72"(R$557#7$4(3"2"'27$4V(*(;-&!TB+8!^KY3_`tM <?,-#+!87.U+,!$9!)$;;-&-8/!A?,-#+i!44t8$!)$;;-A-$8
VOICES | RW | 0x2AFF 0x2A00 | 256 | F$7'" R$42&$5V((7&-$!AF8#B+A-A!)$8#,$; O@ *$-)+Ai!@!UF#+Af*$-)+
J1_CODE | RW | 0x2BFF 0x2B00 | 256 | R$?&$'"##$&(U7'&$'$-" M>J!-8A#,7)#-$8Ai!>!UF#+Af-8A#,7)#-$8
SCREENSHOT | R | 0x2F1F 0x2C00 | 800 | /'&""4#9$2(674"(K%11"&i!A+;+)#+&!&-A?;(F!;-8+!&(#( 326KMDDD 9$,.(#![>!UF#+Af?-]+;\i!(;?B(!(;T(FA!N
| R | 0x2FFF 0x2F20 | 224 | \4%#"-(G--&"##(/?,'" 3;T(FA!,+(&A!N
RAM_SPR | RW | 0x37FF 0x3000 | 2048 | /?&72"(R$42&$5V(>!?(/+A!$9!>DO!A?,-#+A!+()B @!UF#+AfA?,-#+
RAM_SPRPAL RAM_SPRPAL256 | RW | 0x3800 0x3FFF | 2048 | /?&72"(T,5"22" 0QEV(@!?(;+##+A!$9!>DO!)$;$,A!+()B 326KMDDD 9$,.(#![>!UF#+Af)$;$,\
RAM_SPRIMG | RW | 0x7FFF 0x4000 | 16384 | /?&72"(=<,L"(3,2, O@!-.(/+Ai!MOvMO!?-]+;Ai!M!UF#+f?-]+;
YLINE | R | 0x8000 | 2 | R%&&"42(!,#2"&(674"V(N%>VV
ICAP_O | R | 0x8002 | 2 | IT;G(=RGT(T$&2V(J%U-#!$7#?7#
| | 0x8004 | 2 | \4%#"-(G--&"##(/?,'"i (;T(FA!,+(&A!N
ICAP | W | 0x8006 | 2 | IT;G(=RGT(T$&2V J%U-#!-8?7# (8&!HI3E!)$8#,$;!U-#A
| | 0x8008 | 2 | \4%#"-(G--&"##(/?,'"i (;T(FA!,+(&A!N
FREQHZ | W | 0x800A | 2 | @7<"&(I&"]%"4'Si!NSL!#$!ODDWDSL
FREQTICK | R | 0x800C | 2 | @7<"&(@7'8i!#$//;+A!U+#T++8!N!(8&!M!(#!42RdSe
P2_V | RW | 0x800E | 2 | T74(0(F,5%"i!N!$,!M
P2_DIR | R | 0x8010 | 2 | T74(0(37&"'27$4V(Nt$7#?7#i!Mt-8?7#
RANDOM | R | 0x8012 | 2 | )E^A72(!,4-$<(F,5%"V 9,$.!TB-#+%8$-A+!/+8+,(#$,
CLOCK | R | 0x8014 | 2 | )E^A72(R5$'8(F,5%"i!DN:SL!.()B-8+!)F);+A
FLASH_MISO | R | 0x8016 | 2 | H4A$,&-(/T=(I5,#9V(:H<X!;-8+
FLASH_MOSI | W | 0x8018 | 2 | H4A$,&-(/T=(I5,#9V(:X<H!;-8+
FLASH_SCK | W | 0x801A | 2 | H4A$,&-(/T=(I5,#9V(<I`!;-8+
FLASH_SSEL | W | 0x801C | 2 | H4A$,&-(/T=(I5,#9V(<<RY!;-8+
K;7+!#+]#!-8&-)(#+A!78$99-)-(;!-89$,.(#-$8 [+=/=!j23:a<E2E3Y@k!-A!(8!78$99-)-(;!;(U+;!9$,!N]>JJN\ Y-8+A!AB(&+&!-8!/,+F (,+!)$?,$)+AA$,%$8;F![)(88$#!U+!())+AA+&!UF!3,&7-8$!<EH!-8#+,9()+\=
=/%#*/.'?"&$3#"*3
5B+!6(.+&7-8$!-A!)$8#,$;;+&!#B,$7/B!<EH!,+(&A!(8&!T,-#+A!-8#$!-#A!(&&,+AA!A?()+=! 5B-A!(&&,+AA!A?()+!)(8!U+!);(AA-9-+&!(A!.+.$,F!(8&!,+/-A#+,Ai!TB+,+!,+/-A#+,A!(,+! $8+%UF#+!$,!#T$%UF#+!.+.$,F!(&&,+AA+A!#B(#!B(*+!A?+)-9-)!978)#-$8A=!!H8!)$8#,(A#i! .+.$,F!(,+(A!(,+!;(,/+!A+)#-$8A!$9!#B+!(&&,+AA!A?()+!#B(#!B(*+!#B+!A(.+!978)#-$8=!! 4$,!+](.?;+i!#B+!6(.+&7-8$!H1!(8&!B(,&T(,+!,+*-A-$8!87.U+,!(,+!,+/-A#+,Ai!TB-;+! ?;(F9-+;&!-.(/+!&(#(!(8&!)B(,()#+,!U-#.(?A!(,+!)$8A-&+,+&!.+.$,F=

>W

U5"-$%*+$4'<6$-<
5B+!6(.+&7-8$!B(A!#T$!A+#A!$9!,+/-A#+,A'!( /,$7? $9!AB(,+&!,+/-A#+,A (#!(&&,+AA+A! MN>@N!#B,$7/B!MNWNW![N]>JNN!o N]>JW4\!#B(#!-A!())+AA-U;+!#$!U$#B!#B+!<EH!-8#+,9()+! (8&!#B+!PM!)$?,$)+AA$,i!(8&!(8$#B+,!/,$7?!A#(,#-8/!(#!W>GOJ![N]JNNN\!#B(#!-A!$8;F! ())+AA-U;+!#$!#B+!)$?,$)+AA$,=!!!5B+!AB(,+&!,+/-A#+,A!(,+!&+A),-U+&!U+;$Ti!TB-;+!#B+! )$?,$)+AA$,%$8;F!,+/-A#+,A!(,+!&+A),-U+&!-8!#B+!

>@

PM!I$?,$)+AA$, )B(?#+,i!A#(,#-8/!$8!?(/+!DW=

;,<"-%74$(=3* H1R_5!-A!(!A-8/;+%UF#+i!,+(&%$8;F ,+/-A#+,!-A!7A+&!#$!-&+8#-9F!(! 6(.+&7-8$!TB+8!A)(88-8/!<EH!?+,-?B+,(;A=!!H9!(!6(.+&7-8$!-A!?,+A+8#i!-AA7-8/!(! ,+(&!)$..(8&!9$,!(&&,+AA!MN>@N![N]>JNN\!T-;;!?,$&7)+!MNV![N]O1i!3<IHH!j.k\=

@,A5"(_*(=3`a@(!"L7#2"&
<F.U$; | | 3&&,+AA | Y+8/#B | I$8#+8#A
| | [B+]\ | [&+)\ | [B+]\ | [&+)\ | [B+]\ | [&+)\
IDENT | R | 0x2800 | 10240 | 0x01 | 1 | 0x6D | 109
+,&-.,&"(F"&#7$4* 2R^!-A!(!A-8/;+%UF#+i!,+(&%$8;F!,+/-A#+,!#B(#!)$8#(-8A!#B+!.(h$,! (8&!.-8$,!,+*-A-$8!87.U+,A![2!(8&!:!,+A?+)#-*+;F!-8!(!2=:!*+,A-$8!87.U+,-8/! A)B+.+\!$9!#B+!6(.+&7-8$!B(,&T(,+!(8&!$8%U$(,&!9-,.T(,+=!!2W%2N -A!#B+!.(h$,! ,+*-A-$8!87.U+,m!:W%:N -A!#B+!.-8$,!,+*-A-$8!87.U+,=

@,A5"(B*(!`F(!"L7#2"&
<F.U$; | | 3&&,+AA | Y+8/#B | I$8#+8#A
| | [B+]\ | [&+)\ | [B+]\ | [&+)\ | [B+]\ | [&+)\
REV | R | 0x2801 | 10241 | 0x01 | 1 | R3R2R1R0 M3M2M1M0 | R!16 + M
F7-"$(I&,<"(R$%42"&*(5B+!423:R!,+/-A#+, )$8#(-8A!(!$8+%UF#+i!,+(&%$8;F!)$78#!$9! *-&+$!9,(.+A!/+8+,(#+&=!!5B+!)$78#!A#(,#A!(#!?$T+,%$8!(#!Ni!)$78#A!7?!#$!>DDi!#B+8 ,+A+#A!#$!N=!!3#!#B+!6(.+&7-8$lA!G>SL!9,(.+!,(#+i!#B+!,+/-A#+,!T,(?A!(,$78&!#$!N! ,$7/B;F!+*+,F!W=DO!A+)$8&A=

@,A5"(b*(I!GU`(!"L7#2"&
<F.U$; | | 3&&,+AA | Y+8/#B | I$8#+8#A
| | [B+]\ | [&+)\ | [B+]\ | [&+)\ | [B+]\ | [&+)\
FRAME | R | 0x2802 | 10242 | 0x01 | 1 | 0x00-0xFF | 0-255
F"&27',5(K5,4874L(I5,L*(^KY3_`!-A!(!A-8/;+%UF#+i!,+(&%$8;F!,+/-A#+,!#B(#!-A!A+#!#$!M! &7,-8/!#B+!*+,#-)(;!U;(8Q-8/!-8#+,*(;i!$,!N!$#B+,T-A+=!5B+!T(-#*U;(8Q[\!.+#B$&!-8! #B+!6(.+&7-8$!;-U,(,F 7A+A!#B-A!9;(/!#$!&+#+,.-8+!TB+8!#$!,+#7,8=!!5B+,+!(,+!G>! *+,#-)(;!U;(8Q-8/!-8#+,*(;A!?+,!A+)$8&![$8+!?+,!9,(.+!$9!*-&+$!/+8+,(#+&\=!!R()B!$8+! ;(A#A!M=WG>J.A=!!<++!#B+!^-&+$!5-.-8/ A+)#-$8!A#(,#-8/!$8!?(/+!J 9$,!.$,+!$8!*+,#-)(;! U;(8Q-8/!(8&!#$!(*$-&!*-A-U;+!/;-#)B+A!TB+8!7?&(#-8/!#B+!A),++8=

@,A5"()C*(FK6Ga[(!"L7#2"&
<F.U$; | | 3&&,+AA | Y+8/#B | I$8#+8#A
| | [B+]\ | [&+)\ | [B+]\ | [&+)\
VBLANK | R | 0x2803 | 10243 | 0x01 | 1 | X X X X X X X V0
^N'!^+,#-)(;!U;(8Q-8/!A#(#7A'!Nt8$#!-8!*+,#-)(;!U;(8Q-8/i!Mt*+,#-)(;!U;(8Q-8/=

/'&""4(/'&$5574L*(5B+!6(.+&7-8$!$7#?7#A!(!@NNvWNN!?-]+;!A),++8!&-A?;(F!T-8&$T! $8#$!(!;$/-)(;!DM>vDM>!?-]+;!-.(/+=!!5B+!<I2XYYab!(8&!<I2XYYac!,+/-A#+,A!A+#!#B+! ;$)(#-$8!$9!#B+!7??+,!;+9#!)$,8+,!$9!#B+!*-A-U;+!T-8&$T!,+;(#-*+!#$!#B+!;(,/+,!;$/-)(;! -.(/+=!!H9!#B+!*-A-U;+!T-8&$T!+]#+8&A!$99!$9!#B+!,-/B#!$,!U$##$.!$9!#B+!;$/-)(;!-.(/+i!

>D

-#!(7#$.(#-)(;;F!T,(?A!(,$78&!#$!#B+!;+9#!$,!#$?![,+A?+)#-*+;F\!$9!#B+!;$/-)(;!-.(/+=!! 4$,!.$,+!-89$,.(#-$8!$8!A),++8!A),$;;-8/i!A++!#B+!+]?;(8(#-$8!$9!<),$;;-8/ #B(#!A#(,#A! $8!?(/+!>V U+;$T=

@,A5"())*(/R!H66cW(,4-(/R!H66cX(!"L7#2"&#
<F.U$; | | 3&&,+AA | Y+8/#B | KF#+!X99A+#!(8&!2+/-A#+,!I$8#+8#A | 1+9(7;#!
| | [B+]\ | [&+)\ | [B+]\ | [&+)\ | +0 | +1
SCROLL_X | RW | 0x2804 | 10244 | 0x2 | 2 | S7S6S5S4S3S2S1S0 | X X X X X X X S8 | 0x0000
SCROLL_Y | RW | 0x2406 | 10246 | 0x2 | 2 | S7S6S5S4S3S2S1S0 | X X X X X X X S8 | 0x0000
b'!g87A+&!U-#!?$A-#-$8i!-/8$,+&m!AB$7;&!U+!N!9$,!)$.?(#-U-;-#F!,+(A$8A= <No<J'!<),$;;!$99A+#!-8!?-]+;Ai!N%DMM=

/?&72"(YZ[(U$-"*(5B+!P`a:X1R!,+/-A#+,!-A!(!$8+%UF#+i!,+(&fT,-#+!*(;7+!#B(#! )$8#,$;A!#B+!U+B(*-$,!$9!#B+!6(.+&7-8$lA!A?,-#+!)$;;-A-$8%&+#+)#-$8!;$/-)=!!ZB+8!A+#! #$!Ni!Pf`!.$&+!-A!&-A(U;+&!(8&!)$;;-A-$8A!(,+!&+#+)#+&!U+#T++8!(;;!A?,-#+A=!!Z,-#-8/!(! M!#$!P`a:X1R!+8(U;+A!/,$7?+&!jPf`k!)$;;-A-$8!&+#+)#-$8=!!H8!#B-A!.$&+i!#B+!A?,-#+A! (,+!&-*-&+&!-8#$!#T$!/,$7?A![;(U+;+&!P!(8&!`!9$,!)$8*+8-+8)+\i!(8&!)$;;-A-$8A!(,+! $8;F!&+#+)#+&!U+#T++8!A?,-#+A!-8!&-99+,+8#!/,$7?A=!!<?,-#+A!#B(#!U+;$8/!#$!#B+!A(.+! /,$7?!(,+!)$8A-&+,+&!j9,-+8&;Fk!T-#B!$8+!(8$#B+,!(8&!&$8l#!)$;;-&+=!!<+##-8/!U-#!WM!$9! #B+!A?,-#+!)$8#,$;!T$,&!#$!N!$,!M!(AA-/8A!#B+!A?,-#+!#$!#B+!P!$,!`!/,$7?i!,+A?+)#-*+;F=!! <++!#B+!
@,A5"(0b*(/?&72"(T,5"22"(U$-"#
T,5"22"(U$-"(TC^TJ | /"5"'2"-(U$-" | T7D"5
(bin) | (dec) | (hex) | colors | palette | bits
0000 | 0 | 0x0 | 256 | 8 | 0 | A | 0-7
0001 | 1 | 0x1 | 256 | 8 | 1 | B | 0-7
0010 | 2 | 0x2 | 256 | 8 | 2 | C | 0-7
0011 | 3 | 0x3 | 256 | 8 | 3 | D | 0-7
0100 | 4 | 0x4 | 16 | 4 | 0 | A | 0-3
0101 | 5 | 0x5 | 16 | 4 | 1 | B | 0-3
0110 | 6 | 0x6 | 16 | 4 | 0 | A | 4-7
0111 | 7 | 0x7 | 16 | 4 | 1 | B | 4-7
1000 | 8 | 0x8 | 4 | 2 | 0 | A | 0-1
1001 | 9 | 0x9 | 4 | 2 | 1 | B | 0-1
1010 | 10 | 0xA | 4 | 2 | 0 | A | 2-3
1011 | 11 | 0xB | 4 | 2 | 1 | B | 2-3
1100 | 12 | 0xC | 4 | 2 | 0 | A | 4-5
1101 | 13 | 0xD | 4 | 2 | 1 | B | 4-5
1110 | 14 | 0xE | 4 | 2 | 0 | A | 6-7
1111 | 15 | 0xF | 4 | 2 | 1 | B | 6-7
E(;+##+!.$&+'!5B+!A+;+)#+&!?(;+##+!.$&+!87.U+,!-8!U-8(,Fi!&+)-.(;i!(8&!B+](&+)-.(;= I$;$,A'!_7.U+, $9!)$;$,A!(8&!U-#!&+?#B!-8!A+;+)#+&!?(;+##+!.$&+= E(;+##+'!5B+!87.U+,!(8&!;+##+,!$9!#B+!?(;+##+!A+;+)#+&!9$,!#B+!A?,-#+= E-]+;!U-#A'!5B+!U-#!?$A-#-$8A!$9!#B+!A?,-#+!-.(/+!7A+&!-8!#B+!A+;+)#+&!.$&+=

@,A5"(JC*(/?&72"(!$2,27$4
!$2,27$4(!C^!0 | /"5"'2"-(U$-" | `11"'2
(bin) | (dec) | (hex) | Yflip | Xflip | XYswap
000 | 0 | 0x0 | 0 | 0 | 0 | _$8+
001 | 1 | 0x1 | 0 | 0 | 1 | :-,,$,+&!;+9#%#$%,-/B#!#B+8 ,$#(#+&!>GNz
010 | 2 | 0x2 | 0 | 1 | 0 | :-,,$,+&!;+9#!#$!,-/B#
011 | 3 | 0x3 | 0 | 1 | 1 | >GNz );$)QT-A+!,$#(#-$8

>O

100 | 4 | 0x4 | 1 | 0 | 0 | :-,,$,+&!;+9#%#$%,-/B#!#B+8!,$#(#+&!MJNz
101 | 5 | 0x5 | 1 | 0 | 1 | VNz );$)QT-A+!,$#(#-$8
110 | 6 | 0x6 | 1 | 1 | 0 | MJNz );$)QT-A+!,$#(#-$8
111 | 7 | 0x7 | 1 | 1 | 1 | :-,,$,+&!;+9#%#$%,-/B#!#B+8 ,$#(#+&!VNz
2$#(#-$8'!5B+!A+;+)#+&!,$#(#-$8!87.U+,!-8!U-8(,Fi!&+)-.(;i!(8&!B+](&+)-.(;= c!9;-?'!4;-?!A?,-#+!-.(/+!-8!c!&-,+)#-$8![#$?%#$%U$##$.\i!Nt8$i!MtF+A= b!9;-?'!4;-?!A?,-#+!-.(/+!-8!b!&-,+)#-$8![;+9#%#$%,-/B#\i!Nt8$i!MtF+A= bc!AT(?'!<T(?!A?,-#+!b!(8&!c!(]+Ai!Nt8$i!MtF+A= R99+)#'!R99+)#!$9!A+;+)#+&!,$#(#-$8!$8!#B+!A?,-#+!-.(/+=
<?,-#+!I$;;-A-$8!1+#+)#-$8 #$?-)!$8!?(/+!@@ 9$,!.$,+!-89$,.(#-$8=

@,A5"()0*(Y[cUH3`(!"L7#2"&
<F.U$; | | 3&&,+AA | Y+8/#B | I$8#+8#A | 1+9(7;#
| | [B+]\ | [&+)\ | [B+]\ | [&+)\
JK_MODE | RW | 0x2808 | 10248 | 0x01 | 1 | X X X X X X X J0 | 0x00
PN'!<?,-#+!Pf`!.$&+!)$;;-A-$8!&+#+)#-$8'!Nt&-A(U;+&![&+#+)#!(;;!)$;;-A-$8A\i!Mt+8(U;+&=

R$?&$'"##$&(!"#"2*(5B+!PMa2R<R5!-A!(!$8+%UF#+i!,+(&fT,-#+!,+/-A#+,!#B(#!(;;$TA!#B+! 3,&7-8$![$,!$#B+,!B$A#!.-),$)$8#,$;;+,\!#$!A#$?!(8&!A#(,#!#B+!PM!)$?,$)+AA$,=!! Z,-#-8/!N]NM!#$!#B-A!,+/-A#+,!B(;#A!(8&!,+A+#A!#B+!)$?,$)+AA$,i!TB-;+!N]NN!,+;+(A+A! #B+!)$?,$)+AA$,=!!4$;;$T-8/!(!,+A+#i!#B+!PM!U+/-8A!+]+)7#-8/!)$&+!A#(,#-8/!(#!PMaIX1Ri! N]>KNN![MMNNJ!&+)-.(;\=!!

@,A5"()J*(Y)c!`/`@(!"L7#2"&
<F.U$; | | 3&&,+AA | Y+8/#B | I$8#+8#A | 1+9(7;#!
| | [B+]\ | [&+)\ | [B+]\ | [&+)\
J1_RESET | RW | 0x2809 | 10249 | 0x1 | 1 | X X X X X X X R0 | 0x00
2N'!I$?,$)+AA$,!)$8#,$;'!NtB(;#!(8&!,+A+#i Mt,78=

/?&72"(37#,A5"*(<E2a1H<3KYR!-A!(!$8+%UF#+i!,+(&fT,-#+!,+/-A#+,!#B(#!)$8#,$;A!#B+! 6(.+&7-8$lA!A?,-#+!/,(?B-)A!A7UAFA#+.=!!5B+!&+9(7;#!$9!N!(;;$TA!A?,-#+!/,(?B-)A!#$! 978)#-$8!8$,.(;;F=!!ZB+8!<E2a1H<3KYR!-A!A+#!#$!Mi!A?,-#+!/,(?B-)A!(,+!&-A(U;+&!(8&! &$!8$#!(??+(,!$8!A),++8=!!

@,A5"()P*(/T!c3=/GK6`(!"L7#2"&
<F.U$; | | 3&&,+AA | Y+8/#B | I$8#+8#A | 1+9(7;#!
| | [B+]\ | [&+)\ | [B+]\ | [&+)\
SPR_DISABLE | RW | 0x280A | 10250 | 0x1 | 1 | X X X X X X X D0 | 0x00
1N'!<?,-#+!/,(?B-)A!&-A(U;+'!NtA?,-#+A!+8(U;+&i MtA?,-#+A!&-A(U;+&=

/?&72"(T,L"(/"5"'2*(5B+!<E2aE36R!-A!(!$8+%UF#+i!,+(&fT,-#+!,+/-A#+,!7A+&!#$! -.?;+.+8#!&$7U;+!U799+,-8/!9$,!A?,-#+!)$8#,$;!&(#(=!!ZB+8!<E2aE36R!-A!Ni!#B+!A?,-#+! /,(?B-)A!AFA#+.!7A+A!#B+!A?,-#+!)$8#,$;!T$,&A!(#!N]WNNN%N]WW44![M>>JJ%MWWMM! &+)-.(;\!#$!/+8+,(#+!#B+!A?,-#+!&-A?;(F=!!ZB+8!-#!-A!Mi!#B+!A?,-#+!)$8#,$;!T$,&A!(#! N]W@NN%N]WG44![MWWM>%M@WWD!&+)-.(;\!(,+!7A+&=!!<++!#B+!A+)#-$8!$8!1$7U;+! K799+,-8/ A#(,#-8/!$8!?(/+!MN 9$,!.$,+!-89$,.(#-$8!(8&!+](.?;+!)$&+=

>G

@,A5"()Q*(/T!cTG;`(!"L7#2"&
<F.U$; | | 3&&,+AA | Y+8/#B | I$8#+8#A | 1+9(7;#!
| | [B+]\ | [&+)\ | [B+]\ | [&+)\
SPR_PAGE | RW | 0x280B | 10251 | 0x1 | 1 | X X X X X X X P0 | 0x00
EN'!<?,-#+!/,(?B-)A!)$8#,$;!?(/+'!NtN]WNNN%N]WW44i MtN]W@NN%N]WG44=

T74(0(=ZH(U$-"*( 5B+!HX:X1R!,+/-A#+,!-A!7A+&!#$!(AA-/8!?-8!>!#$!$8+!$9!#T$! 978)#-$8Ai!$,!#$!&-A(U;+!-#!+8#-,+;F=!!5B+!&+9(7;#!*(;7+!$9!N]NN!)(7A+A!#B+!6(.+&7-8$! #$!-/8$,+!?-8!>=!!ZB+8!A+#!#$!N]@O![&+)-.(;!GN!$,!3<IHH!j4k\i!?-8!>!-A!)$88+)#+&!#$! #B+!6(.+&7-8$lA!$8U$(,&!<EH 9;(AB!.+.$,F!)B-?!(A!#B+!<RY!$,!<<!A-/8(;=!4-8(;;Fi! TB+8!HX:X1R!-A!A+#!#$!N]@3![&+)-.(;!G@!$,!3<IHH!jPk\i!#B+!?-8!-A!)$8#,$;;+&!UF!#B+! )$?,$)+AA$,%$8;F!E>a^!(8&!E>a1H2!,+/-A#+,A=!!X#B+,!*(;7+A!B(*+!8$!+99+)#=

@,A5"()E*(=HUH3`(!"L7#2"&
<F.U$; | | 3&&,+AA | Y+8/#B | I$8#+8#A | 1+9(7;#!
| | [B+]\ | [&+)\ | [B+]\ | [&+)\
IOMODE | RW | 0x280C | 10252 | 0x1 | 1 | 0x00, 0x46, or 0x4A | 0x00
HX:X1R!.7A#!U+!$8+!$9!#B+!9$;;$T-8/!#B,++!*(;7+A'
- N]NN![N!&+)-.(;i!3<IHH!j_gYk\!o E-8!>!-A!-/8$,+&=
- N]@O![GN!&+)-.(;i!3<IHH!j4k\!o E-8!>!-A!6(.+&7-8$!<EH!9;(AB!.+.$,F!<RY=
- N]@3![G@!&+)-.(;i!3<IHH!jPk\!o E-8!>!-A!)$8#,$;;+&!UF!#B+!6(.+&7-8$!)$?,$)+AA$,=

K,'8L&$%4-(R$5$&*(5B+!K6aIXYX2!,+/-A#+,!&+9-8+A!(!U()Q/,$78&!)$;$,!#B(#! (??+(,A!U+B-8&!(;;!$9!#B+!$#B+,!*-&+$!A$7,)+A=!X8!?$T+,%7?i!#B+!U()Q/,$78&!)$;$,!-A! #B+!$8;F!-.(/+!&-A?;(F+&i!(8&!&+9(7;#A!#$!N]NNNN![U;()Q\=!!5B+!K6aIXYX2!*(;7+!-A!(! A#(8&(,&!6(.+&7-8$!MO%U-#!)$;$,!*(;7+!+])+?#!#B(#!K-#!MDi!#B+!(;?B(![3\!)B(88+;!$,! #,(8A?(,+8)F!U-#i!-A!-/8$,+&!-9!A+#=!

@,A5"()_*(K;cRH6H!(!"L7#2"&
<F.U$; | | 3&&,+AA | Y+8/#B | KF#+!X99A+#!(8&!2+/-A#+,!I$8#+8#A | 1+9(7;#!
| | [B+]\ | [&+)\ | [B+]\ | [&+)\ | +0 | +1
BG_COLOR | RW | 0x280E | 10254 | 0x2 | 2 | G2G1G0B4B3B2B1B0 | X R4R3R2R1R0G4G3 | 0x0000
b'!3;?B(!)B(88+;!)$;$,!-89$,.(#-$8i!-/8$,+&=
2@o2N'!2+&!)B(88+;!)$;$,!-89$,.(#-$8i!N%W>=
K@oKN'!6,++8!)B(88+;!)$;$,!-89$,.(#-$8i!N%W>=
K@oKN'!K;7+!)B(88+;!)$;$,!-89$,.(#-$8i!N%W>=

6"12(,4-(!7L92(G%-7$(/,<?5"#*(5B+!6(.+&7-8$!B(A!#B+!(U-;-#F!#$!?;(F!U()Q!A#+,+$! (7&-$!T(*+!&(#(!7A-8/!#B+!<3:EYRaY!(8&!<3:EYRa2 ,+/-A#+,A=!!R()B!,+/-A#+,! ())+?#A!(!A-/8+&!MO%U-#!-8#+/+,!,+9;+)#-8/!#B+!A(.?;+=!5B+!6(.+&7-8$!7?&(#+A!(7&-$! A(.?;+A!+*+,F!O@!)F);+A!$9!-#lA!DN:SL!);$)Qi!)$,,+A?$8&-8/!#$!(8!7?&(#+!9,+C7+8)F! $9!GJM=>DQSLi!A$!*(;7+A!;$(&+&!-8#$!#B+A+!,+/-A#+,A!(,+!,+9;+)#+&!$8!#B+!(7&-$!$7#?7#! )B(88+;A!T-#B-8!M=>JsA=!!

@,A5"()B*(/GUT6`c6(,4-(/GUT6`c! !"L7#2"&#
<F.U$; | | 3&&,+AA | Y+8/#B | KF#+!X99A+#!(8&!2+/-A#+,!I$8#+8#A | 1+9(7;#!
| | [B+]\ | [&+)\ | [B+]\ | [&+)\ | +0 | +1
SAMPLE_L | RW | 0x2810 | 10256 | 0x2 | 2 | L7L6L5L4L3L2L1L0 | L15L14L13L12L11L10L9L8 | 0x0000

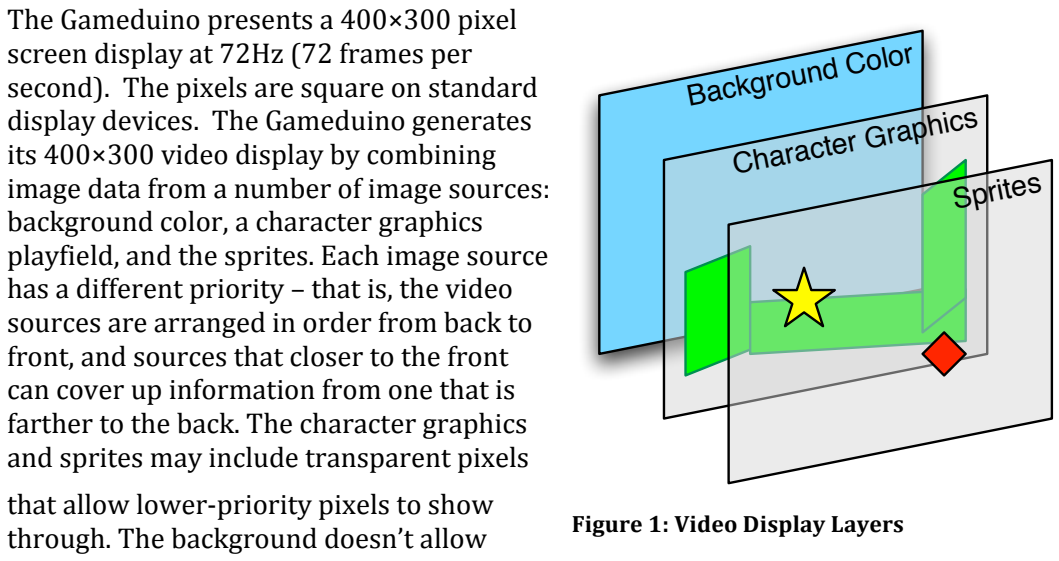
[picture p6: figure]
5B+!6(.+&7-8$ ?,+A+8#A!(!@NNvWNN!?-]+;! A),++8!&-A?;(F (#!G>SL![G>!9,(.+A!?+,! A+)$8&\=!!5B+!?-]+;A!(,+!AC7(,+!$8!A#(8&(,&! &-A?;(F!&+*-)+A=!!5B+!6(.+&7-8$!/+8+,(#+A! -#A @NNvWNN!*-&+$!&-A?;(F!UF!)$.U-8-8/! -.(/+!&(#(!9,$.!(!87.U+,!$9!-.(/+!A$7,)+A'! U()Q/,$78& )$;$,i!(!)B(,()#+,!/,(?B-)A! ?;(F9-+;&i!(8&!#B+!A?,-#+A= R()B!-.(/+!A$7,)+! B(A!(!&-99+,+8#!?,-$,-#F!o #B(#!-Ai!#B+!*-&+$! A$7,)+A!(,+!(,,(8/+&!-8!$,&+,!9,$.!U()Q!#$! 9,$8#i!(8&!A$7,)+A!#B(#!);$A+,!#$!#B+!9,$8#! )(8!)$*+,!7?!-89$,.(#-$8!9,$.!$8+!#B(#!-A! 9(,#B+,!#$!#B+!U()Q= 5B+!)B(,()#+,!/,(?B-)A (8&!A?,-#+A!.(F!-8);7&+!#,(8A?(,+8#!?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

>J

SCROLL_R | RW | 0x2812 | 10258 | 0x2 | 2 | R7R6R5R4R3R2R1R0 | R15R14R13R12R11R10R9R8 | 0x0000
YNoYMD'!Y+9#!(7&-$!)B(88+;!A(.?;+!*(;7+i!MO%U-#!A-/8+&!-8#+/+,![YMD -A!#B+!A-/8!U-#\= 2No2MD'!2-/B#!(7&-$!)B(88+;!A(.?;+!*(;7+i!MO%U-#!A-/8+&!-8#+/+,![2MD -A!#B+!A-/8!U-#\=

/'&""4#9$2(674"(/"5"'2* 5B+!<I2RR_<SX5ac!,+/-A#+,!-A!7A+&!#$!)(?#7,+!(!;-8+!$9! ,(A#+,!&(#(!9,$. #B+!<I2RR_<SX5!U799+,!(#!N]>INN![MM>O@!&+)-.(;\=!!5$!#(Q+!(! A),++8AB$#i!;$(&!(!*(;7+!U+#T++8!N]JNNN!(8&!N]JM>K![&+)-.(;!W>GOJ!(8&!WWNOG\i! )$,,+A?$8&-8/!#$!#B+!9;(/!U-#!4tM!(8&!#B+!<N%<J +C7(;!#$!#B+!;-8+!87.U+,![N!#$!>VV\!#$! U+!)(?#7,+&=!!ZB+8!#B+!9;(/!U-#!$9!#B+!,+/-A#+,!,+(&A!Mi!#B+!A+;+)#+&!;-8+!$9!&(#(!-A! (*(-;(U;+!-8!.+.$,F!;$)(#-$8A!N]>INN%N]>4M4![MM>O@%M>NOW!&+)-.(;\=!Z,-#-8/ (!N! &-A(U;+A!#B+!A),++8AB$#!9+(#7,+i!TB-;+!#B+!;$T!U-#A!<N%<J T-;;!(;T(FA!,+(&!#B+!)7,,+8#! 6(.+&7-8$!A)(8!;-8+=

@,A5"()b*(/R!``a/+H@cX(!"L7#2"&
<F.U$; | | 3&&,+AA | Y+8/#B | KF#+!X99A+#!(8&!2+/-A#+,!I$8#+8#A | 1+9(7;#!
| | [B+]\ | [&+)\ | [B+]\ | [&+)\ | +0 | +1
SCREENSHOT_Y | RW | 0x2406 | 10246 | 0x2 | 2 | S7S6S5S4S3S2S1S0 | F X X X X X X S8 | 0x0000
b'!g87A+&!U-#!?$A-#-$8i!-/8$,+&m!AB$7;&!U+!N!9$,!)$.?(#-U-;-#F!,+(A$8A= <No<J'!2(A#+,!;-8+!#$!)(?#7,+i!N%>VV=
4'!<),++8AB$#!9;(/i!N!$,!M=

\4%#"-(!"L7#2"&# (8& \4%#"-(G--&"##(/?,'"*(<+*+,(;!?$,#-$8A!$9!#B+!6(.+&7-8$! .+.$,F!.(?!(,+!787A+&=!!5B+A+!(&&,+AA+A!B(*+!8$!978)#-$8i!(8&!(,+!8$#!.(??+&!#$! A#$,(/+!$,!)$8#,$;=!!ZB+8!T,-##+8i!#B+A+!;$)(#-$8A!B(*+!8$!+99+)#!(8&!#B+!&(#(! T,-##+8!-A!&-A)(,&+&=!!ZB+8!,+(&i!#B+!;$)(#-$8A!B(*+!8$!A?+)-9-+&!*(;7+ (8&!AB$7;&! ,+(&!Ni!U7#!A$.+!(&&,+AA+A!.(F!,+(&!$#B+,i!78?,+&-)#(U;+!*(;7+A!-8A#+(&=!!H8! ?(,#-)7;(,i!787A+&!,+/-A#+,A!(8&!787A+&!(&&,+AA!A?()+!-A!8$#!)$88+)#+&!#$!23:!$,! $#B+,!A),(#)B?(&!A#$,(/+=
G'%$)*L'<20"3

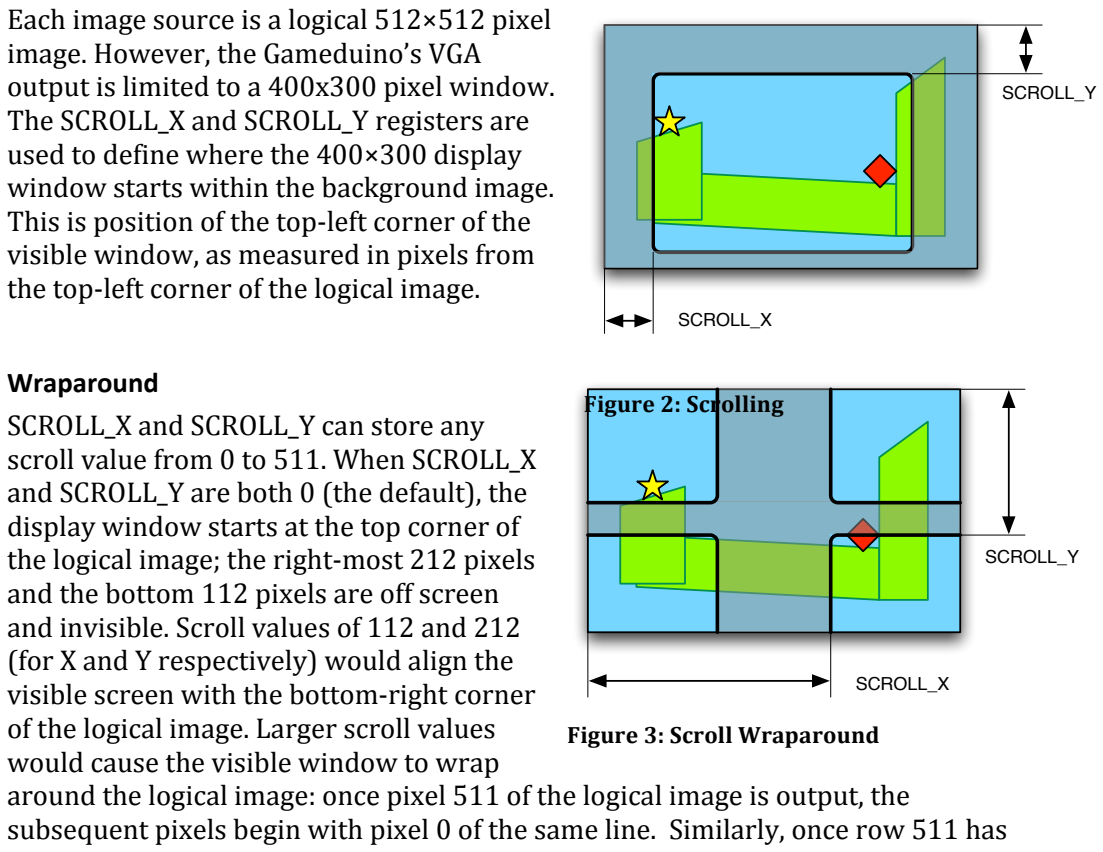
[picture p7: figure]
R()B!-.(/+!A$7,)+!-A!(!;$/-)(;!DM>vDM>!?-]+;! -.(/+= S$T+*+,i!#B+!6(.+&7-8$lA!^63! $7#?7#!-A!;-.-#+&!#$!(!@NN]WNN!?-]+;!T-8&$T= 5B+!<I2XYYab!(8&!<I2XYYac!,+/-A#+,A!(,+! 7A+&!#$!&+9-8+!TB+,+!#B+!@NNvWNN!&-A?;(F! T-8&$T!A#(,#A!T-#B-8!#B+!U()Q/,$78&!-.(/+= 5B-A!-A!?$A-#-$8!$9!#B+!#$?%;+9#!)$,8+,!$9!#B+! *-A-U;+!T-8&$Ti!(A!.+(A7,+&!-8!?-]+;A!9,$.! #B+!#$?%;+9#!)$,8+,!$9!#B+!;$/-)(;!-.(/+=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

>V

#,(8A?(,+8#!?-]+;Ai!A-8)+!#B+,+!-A!8$!;$T+,%?,-$,-#F!-.(/+!#$!AB$T!#B,$7/B=

5B+!A$7,)+A!9$,!#B+!6(.+&7-8$lA!*-&+$!&-A?;(Fi -8!$,&+,!9,$.!U()Q!#$!9,$8#i (,+'
- K()Q/,$78& )$;$,i
- IB(,()#+,!/,(?B-)Ai!(8&
- <?,-#+A!-8!87.+,-)!$,&+,= 4$,!+](.?;+i!-.(/+!&(#(!$8!#B+!?;(F9-+;&!)$*+,A!7?!#B+!U()Q/,$78&!)$;$,i!(8&!A?,-#+! N!-.(/+!&(#(!T$7;&!-8!#7,8!)$*+,!7?!#B+!?;(F9-+;&= <?,-#+!>DD!T$7;&!)$*+,!7?!?-]+;A! 9,$.!(8F!;$T+,%87.U+,+&!A?,-#+![-8);7&-8/!A?,-#+!N\!(A!T+;;!(A!?;(F9-+;&!(8&! U()Q/,$78&!?-]+;A=
(4*/..$%&

U++8!$7#?7#!#$!#B+!^63!A),++8i!#B+!8+]#!,$T!#$!U+!$7#?7#!T-;;!U+!,$T!N!$9!#B+!;$/-)(;! -.(/+=

@,A5"(0C*(/R!H66(!"L7#2"&#
<F.U$; | | 3&&,+AA | Y+8/#B | KF#+!X99A+#!(8&!2+/-A#+,!I$8#+8#A | 1+9(7;#!
| | [B+]\ | [&+)\ | [B+]\ | [&+)\ | +0 | +1
SCROLL_X | RW | 0x2804 | 10244 | 0x2 | 2 | S7S6S5S4S3S2S1S0 | X X X X X X X S8 | 0x0000
SCROLL_Y | RW | 0x2406 | 10246 | 0x2 | 2 | S7S6S5S4S3S2S1S0 | X X X X X X X S8 | 0x0000
b'!g87A+&!U-#!?$A-#-$8i!-/8$,+&m!AB$7;&!U+!N!9$,!)$.?(#-U-;-#F!,+(A$8A=

WN

<No<J'!<),$;;!$99A+#!-8!?-]+;Ai!N%DMM=

E,$/,(..+,A!)(8!#(Q+!(&*(8#(/+!$9!#B-A!T,(?%(,$78&!9+(#7,+!#$!-.?;+.+8#! )$8#-87$7A;F!A),$;;-8/!-.(/+A= IB(,()#+,A!(8&!A?,-#+A!#B(#!(,+!)7,,+8#;F!$99%A),++8! [#B+!/,+F+&%$7#!(,+(A!$9!#B+!9-/7,+A!(U$*+\!)(8!U+!7?&(#+&!TB-;+!#B+!A),++8!A),$;;Ai! /-*-8/!#B+!-;;7A-$8!$9!(8!-89-8-#+!?;(F9-+;&=

"""#$%&$'!-8A+,#!+](.?;+!)$&+!B+,+000

U20'6*U.-$$(*U.-)00'(4
5B+!A),$;;!,+/-A#+,A!(99+)#!#B+!+8#-,+!9,(.+i!A$!)B(8/-8/!#B+!A),$;;!*(;7+A!-8!#B+! .-&&;+!$9!/+8+,(#-8/!(!9,(.+!$8!#B+!&-A?;(F!T-;;!)(7A+!?(,#A!$9!#B+!&-A?;(F!#$!A),$;;! -8&+?+8&+8#;F!$9!#B+!,+A#!$9!#B+!&-A?;(F=!!5B+!6(.+&7-8$lA!PM!)$?,$)+AA$,!)(8!,+;$(&! #B+!A),$;;!,+/-A#+,A!-8!#B+!.-&&;+!$9!*-&+$!/+8+,(#-$8!#$!),+(#+!(!A?;-#%A),++8!$,! .7;#-%?(8+!A),$;;-8/!+99+)#=

"""#$%&$'!-8A+,#!+](.?;+!)$&+ B+,+000
@)4E&*/7%+'=/./*
5B+!U()Q/,$78&!)$;$,!-A!&+9-8+&!UF!#B+!)$8#+8#A!$9!#B+!MO%U-#!K6aIXYX2!,+/-A#+,= 5B-A!)$;$,!(??+(,A!U+B-8&!(;;!$9!#B+!$#B+,!*-&+$ A$7,)+A= X8!?$T+,%7?i!#B+! U()Q/,$78&!)$;$,!-A!#B+!$8;F!-.(/+!&-A?;(F+&i!(8&!&+9(7;#A!#$!N]NNNN![U;()Q\=

5B+!K6aIXYX2!*(;7+!-A!(!A#(8&(,&!6(.+&7-8$!MO%U-#!)$;$,!*(;7+ [A++!#B+!A+)#-$8!$8! I$;$,\i!+])+?#!#B(#!K-#!MDi!#B+!(;?B(![3\ )B(88+;!$,!#,(8A?(,+8)F!U-#i!-A!-/8$,+&!-9!A+#= 5B+!U()Q/,$78&!)(8!8+*+,!U+!#,(8A?(,+8#i!A-8)+!#B+,+!(,+!8$!;$T+,%?,-$,-#F!?-]+;A! #$!AB$T!#B,$7/B= 5B+!U()Q/,$78&!-A!8$,.(;;F!(!A$;-&!)$;$,i!U7#!A++!#B+!A+)#-$8!$8! ,(A#+,!)B(A-8/!9$,!+](.?;+A!-8*$;*-8/!.7;#-)$;$,+&!U()Q/,$78&A=

@,A5" 0)*(K;cRH6H!(!"L7#2"&
<F.U$; | | 3&&,+AA | Y+8/#B | KF#+!X99A+#!(8&!2+/-A#+,!I$8#+8#A | 1+9(7;#!
| | [B+]\ | [&+)\ | [B+]\ | [&+)\ | +0 | +1
BG_COLOR | RW | 0x280E | 10254 | 0x2 | 2 | G2G1G0B4B3B2B1B0 | X R4R3R2R1R0G4G3 | 0x0000
b'!3;?B(!)B(88+;!)$;$,!-89$,.(#-$8i -/8$,+&=
2@o2N'!2+&!)B(88+;!)$;$,!-89$,.(#-$8i!N%W>=
K@oKN'!6,++8!)B(88+;!)$;$,!-89$,.(#-$8i!N%W>=
K@oKN'!K;7+!)B(88+;!)$;$,!-89$,.(#-$8i!N%W>=
=5)*)4#"*'!*)05$43
5$/+#B+,i!#B+!.+.$,F!(,+(A!23:aEHIi!23:aIS2i!(8&!23:aE3Y!&+9-8+!#B+ )B(,()#+,!/,(?B-)A ?-)#7,+ #B(#!-A!&-A?;(F+&!U+B-8&!#B+!/(.+!A?,-#+A!(8&!-8!9,$8#!$9! #B+!U()Q/,$78&!)$;$,= 5B-A ?-)#7,+ )$8A-A#A!$9!(!;$/-)(;!DM>vDM>!?-]+;!-.(/+i!U7#!( 97;;!U-#.(?!$9!>%UF#+!)$;$,A!T$7;&!$))7?F!(!B(;9%.+/(UF#+!o $U*-$7A;F!(8!-AA7+!9$,!(! &+*-)+!T-#B!$8;F!W>QUF#+A!$9!(&&,+AA!A?()+= H8A#+(&i!23:aEHI!)$8#(-8A!(!O@vO@!/,-&! $9!$8+%UF#+!)B(,()#+,Ai!TB+,+!+()B!)B(,()#+,!-8!#B+!/,-&!,+?,+A+8#A!$8+!$9!>DO!JvJ!

WM

?-]+;!U-#.(?A!A#$,+&!-8!23:aIS2= R()B!)B(,()#+,!-8!#B+!/,-&!(;A$ B(A!-#A!$T8!@%)$;$,! ?(;+##+ -8!23:aE3Y=

+=/`BA1a*B0"3,'$0%*B'.6&-$ 23:aEHI!)$8#(-8A!(!O@vO@!/,-&!$9!)B(,()#+,A!#B(#!&+9-8+A!#B+!)B(,()#+,!/,(?B-)A! ?-)#7,+= R()B!UF#+!-8!23:aEHI!,+?,+A+8#A!(!)B(,()#+,!U-#.(?!#$!U+!;$$Q+&!7?!-8! 23:aIS2= IB(,()#+,!U-#.(?A!(,+!JvJ!?-]+;A!(8&!)(8!A+;+)#!$8+!$9!9$7,!)$;$,Am!)$;$,! -89$,.(#-$8!9$,!+()B!?-]+;!-A!&,(T8!9,$.!23:aE3Y= IB(,()#+,!/,(?B-)A!?-]+;A!.(F! U+!#,(8A?(,+8#i!(;;$T-8/!#B+!U()Q/,$78&!)$;$,!#$!AB$T!#B,$7/B= 5B+!,+A7;#!-A!(! DM>vDM>!?-]+;!)B(,()#+,!/,(?B-)A!?-)#7,+!#B(#!9$,.A!#B+!?;(F9-+;&!9$,!/(.+!AQ+#)B+A=!! 5B+!$,/(8-L(#-$8!$9!#B+!?;(F9-+;&!-A!AB$T8!-8!5(U;+!>D'!23:aEHI!:+.$,F!:(?=

3!@NNvWNN!?-]+;![DNvWG{!)B(,()#+,\!T-8&$T $9!#B-A!?-)#7,+!-A!*-A-U;+!$8!A),++8= 5B+!T-8&$T!.(F!U+!A),$;;+&!(,$78&!#B+!?-)#7,+!$8!(!A-8/;+%?-]+;!U(A-Ai!A$!#B(#!?(,#A! $9!(A!.(8F!(A!DMvWV!)B(,()#+,A!.(F!U+!97;;F!$,!?(,#-(;;F!*-A-U;+= 5B+!6(.+&7-8$lA! .+.$,F!-A!&7(;%?$,#+&i!A$!)B(,()#+,A!#B(#!(,+!8$#!)7,,+8#;F!$8!A),++8!)(8!U+! 7?&(#+&!UF!#B+!3,&7-8$!<EH!-8#+,9()+!$,!UF!#B+!PM!)$?,$)+AA$,!T-#B$7#!)(7A-8/! *-A-U;+!(,#-9()#A=

+=/`1I+a*B0"3,'$0%*15"-".6$-*U$6 R()B!)B(,()#+,!)$&+!-8!23:aEHI!-A!;$$Q+&!7?!-8!23:aIS2!#$!&+#+,.-8+!#B+! )$,,+A?$8&-8/!JvJ!?-]+;!)B(,()#+,!U-#.(?!#B(#!AB$7;&!U+!&-A?;(F+&!(#!#B+!)B(,()#+,! ?$A-#-$8=!!5B+,+!(,+!>DO!U-#.(?Ai!$8+!9$,!+()B!?$AA-U;+!)B(,()#+,!)$&+!A#$,+&!-8! 23:aEHI=!!5(U;+!>O'!23:aIS2!:+.$,F!:(? AB$TA!#B+!$,/(8-L(#-$8!$9!#B+! )B(,()#+,!A+# .+.$,F=!!IB(,()#+,!)$&+A!(,+!;-A#+&!-8!B+](&+)-.(;!(8&!&+)-.(;i!(;$8/! T-#B!#B+!3<IHH!/;F?B!9$,!)B(,()#+,A!WW!#B,$7/B!M>O![N]WM!#B,$7/B!N]G4\=!!6;F?BA! #B(#!(,+!8$#!?,-8#(U;+!3<IHH!)B(,()#+,A!(,+!AB(&+&!/,+F=

5B+!23:aIS2!U-#.(?A!&+#+,.-8+!#B+!/,(?B-)!#B(#!-A!&-A?;(F+&!(#!+()B!)B(,()#+,! ;$)(#-$8=!!IB(,()#+,!U-#.(?A!)$8#(-8!@!)$;$,A!(8&!(,+!#B+,+9$,+!>!U-#A!&++?m!+()B! )B(,()#+,!U-#.(?!$))7?-+A!MO!UF#+A=!!5B+!9$,.(#!$9!+()B!)B(,()#+,!U-#.(?!-A!AB$T8! -8 5(U;+!>>'!23:aIS2!K-#.(?!X,/(8-L(#-$8=!!E-]+;A!-8!#B+!)B(,()#+,!U-#.(?!B(*+! )$$,&-8(#+A!A#(,#-8/!(#![NiN\!9$,!#B+!7??+,!;+9#%B(8&!)$,8+,!$9!#B+!U-#.(?i!#$![GiG\!(# #B+!;$T+,!,-/B#=!!R()B!?-]+;!-A!#T$!U-#Ai!#B+!*(;7+!N%W!A+;+)#A!$8+!$9!#B+!9$7,!)$;$,A! A#$,+&!-8!#B+!)$,,+A?$8&-8/!)B(,()#+,!?(;+##+!-8!23:aE3Y=

@,A5"(00*(!GUcR+!(K72<,?(H&L,47>,27$4
2$T X99A+# | KF#+!X99A+#!(8&!K-#.(?!I$8#+8#A
[B+]\ | [&+)\ | +0 | +1
+0x00 | +0 | P001P000 P101P100 P201P200 P301P300 | P401P400 P501P500 P601P600 P701P700
+0x02 | +2 | P011P010 P111P110 P211P210 P311P310 | P411P410 P511P510 P611P610 P711P710
+0x04 | +4 | P021P020 P121P120 P221P220 P321P320 | P421P420 P521P520 P621P620 P721P720
+0x06 | +6 | P031P030 P131P130 P231P230 P331P330 | P431P430 P531P530 P631P630 P731P730
+0x08 | +8 | P041P040 P141P140 P241P240 P341P340 | P441P440 P541P540 P641P640 P741P740
+0x0A | +10 | P051P050 P151P150 P251P250 P351P350 | P451P450 P551P550 P651P650 P751P750
+0x0C | +12 | P061P060 P161P160 P261P260 P361P360 | P461P460 P561P560 P661P660 P761P760
+0x0D | +14 | P071P070 P171P170 P271P270 P371P370 | P471P470 P571P570 P671P670 P771P770
E]FME]FN'!E-]+;!*(;7+!(#!U-#.(?!;$)(#-$8![]iF\i!N%W=

W>

H4"#"?2&#'.&2)I'5(U;+!>O'!23:aIS2!:+.$,F!:(? AB$TA!3<IHH!/;F?BA!9$,! )$8*+8-+8)+=!!H8!3<IHHi!#B+!)$8#,$;!)B(,()#+,A!(#!N!#B,$7/B!WM![N]NN!#B,$7/B!N]M4\! (8&!M>G![N]G4\!(,+8l#!?,-8#(U;+!3<IHH!)B(,()#+,Ai!TB-;+!)B(,()#+,!)$&+A!M>J! #B,$7/B!>DD![N]JN!#B,$7/B!N]44\!(,+!78&+9-8+&=!!5B-A!.(Q+A!#B+A+!)B(,()#+,A!/$$&! )(8&-&(#+A!9$,!7A+!(A!?;(F9-+;&!/,(?B-)A!-8A#+(&!$9!(;?B(U+#-)!(8&!87.+,-)!AF.U$;A=!

3<IHH!-A!(!,+;(#-*+;F!$;&!A#(8&(,&m!A+*+,(;!.$,+!.$&+,8!A#(8&(,&A!+]-A#i!(8&!(;;!(,+! A7?+,A+#A!$9!#B+!3<IHH!A#(8&(,&=!!5(U;+!>W'!IB(,()#+,!<+#A AB$TA!#B+!,+;(#-$8AB-?! U+#T++8!A-]!?$?7;(,!)$&+!?(/+A=!!3;;!AB(,+!#B+!A(.+!&+9-8-#-$8!9$,!)B(,()#+,A![)$&+! ?$-8#A\!U+#T++8!N!(8&!M>G![N]NN!(8&!N]G4\!T-#B!3<IHH=!

@,A5"(0J*(R9,&,'2"&(/"2#
IB(,()#+,!<+# | IB(,()#+,!I$&+A
0x00-0x1F | 0x20-0x7E | 0x7F | 0x80-0x9F | 0xA0-0xFF
3<IHH | I$8#,$; | E,-8#(U;+ | I$8#,$; | g8&+9-8+& | g8&+9-8+&
Z-8&$TA%M>D> | I$8#,$; | E,-8#(U;+ | I$8#,$; | E,-8#(U;+ | E,-8#(U;+
:()!X<!2$.(8 | I$8#,$; | E,-8#(U;+ | I$8#,$; | E,-8#(U;+ | E,-8#(U;+
H<X%JJDV%M | I$8#,$; | E,-8#(U;+ | I$8#,$; | I$8#,$; | E,-8#(U;+
H<X%JJDV%MD | I$8#,$; | E,-8#(U;+ | I$8#,$; | I$8#,$; | E,-8#(U;+
g54%J | I$8#,$; | E,-8#(U;+ | I$8#,$; | :7;#-%UF#+ | :7;#-%UF#+

:$A#!Z-8&$TA!AFA#+.A!)$89-/7,+&!9$,!(!Z+A#+,8!(;?B(U+# 7A+A!#B+!Z-8&$TA%M>D>! )B(,()#+,!A+#=!!3??;+!?,$&7)#A!7A+!:()!X<!2$.(8!9$,!#B+!A(.+!?7,?$A+=!!5B+!#T$! )B(,()#+,!A+#A!$9!)$7,A+!&-99+,!$8!#B+!)B(,()#+,A!(U$*+!)$&+!M>G![N]G4\m!(9#+,!(;;i! TB+8!B(*+!2+&.$8&!(8&!I7?+,#-8$!U++8!(U;+!#$!)$.?;+#+;F!(/,++!$8!(8F#B-8/|

5B+!,+;+*(8#!A#(8&(,&A!(,+!H<X%JJDV%M (8&!-#A!7?&(#+&!*+,A-$8i!H<X%JJDV%MD![TB-)B! -8);7&+A!#B+!R7,$!)B(,()#+,!(8&!(!9+T!$#B+,!.$&-9-)(#-$8A\=!!g54%J!-A!(8!J%U-#! +8)$&-8/!9$,!g8-)$&+!#B(#!.(]-.-L+A!3<IHH!)$.?(#-U-;-#F'!)$&+A!N!#B,$7/B!M>G! [N]NN!#B,$7/B!N]G4\!.(#)B!3<IHHi!TB-;+!#B+!B-/B+,!)$&+A (,+!$8;F!+8)$78#+,+&!(A! ?(,#!$9!.7;#-%UF#+!A+C7+8)+A!#B(#!+8)$&+!#B+!,+A#!$9!#B+!g8-)$&+!)B(,()#+,!A+#=

+=/`B=Ya*B0"3,'$0%*15"-".6$-*B"0$66$< R()B!)B(,()#+,!$8!#B+!?;(F9-+;&!B(A!-#A!$T8!@%)$;$,!?(;+##+!-8!23:aE3Y=!!5B-A!.+(8A! #B(#!+()B!)B(,()#+,!B(A!-#A!$T8!)$;$,!?(;+##+i!(8&!(;A$!#B(#!)B(,()#+,A!#B(#!B(*+! -&+8#-)(;!U-#.(?A!U7#!,+C7-,+!&-99+,+8#!)$;$,A!.7A#!U+!A#$,+&!(A!A+?(,(#+!)B(,()#+,A=!! I$;$,!&(#(!-A!A#$,+&!-8!A#(8&(,&!326KMDDD!9$,.(#i!,+A7;#-8/!-8!>DO!)B(,()#+,! ?(;+##+Ai!+()B!?(;+##+!$))7?F-8/!J!UF#+A=!!5B+!$*+,(;;!A#,7)#7,+!$9!23:aE3Y!-A!AB$T8! -8!5(U;+!>G'!23:aE3Y!:+.$,F!:(?=!!

5B+!-8&-*-&7(;!?(;+##+A!(,+!)$.?$A+&!$9!@!)$;$,!+8#,-+Ai!87.U+,+&!N!#B,$7/B!@ (A! AB$T8!-8!5(U;+!>@'!23:aE3Y!E(;+##+!4$,.(#=!!IB(,()#+,!U-#.(?!?-]+;A!.(?!&-,+)#;F! #$!#B+!?(;+##+!+8#,-+A'!U-#.(?!?-]+;!*(;7+A!$9!N!(,+!&-A?;(F+&!-8!#B+!)$;$,!+8#,F!Ni! ?-]+;!*(;7+!M!-A!&-A?;(F+&!7A-8/!)$;$,!+8#,F!Mi!(8&!A$!$8=!!5,(8A?(,+8)F!)(8!U+!A+#!9$,!

WW

(8F!)$;$,!$,!)$;$,A!-8!#B+!?(;+##+=!!H#!-A!)7A#$.(,F!#$!)$&+!)B(,()#+,!A+#A!A$!#B(#!)$;$,! +8#,F!N![?-]+;!*(;7+!N\!)$,,+A?$8&A!#$!#B+!U()Q/,$78&!$,!#,(8A?(,+8#!)$;$,=

@,A5"(0P*(!GUcTG6(T,5"22"(I$&<,2
I$;$, R8#,F | R8#,F X99A+# | KF#+!X99A+#
xN | xM
N | xN | G2G1G0B4B3B2B1B0 | A R4R3R2R1R0G4G3
M | x> | G2G1G0B4B3B2B1B0 | A R4R3R2R1R0G4G3
> | x@ | G2G1G0B4B3B2B1B0 | A R4R3R2R1R0G4G3
W | xO | G2G1G0B4B3B2B1B0 | A R4R3R2R1R0G4G3
3'!3;?B(!)B(88+;!)$;$,!-89$,.(#-$8i!Nt$?(C7+i!Mt#,(8A?(,+8#= 2No2@'!2+&!)B(88+;!)$;$,!-89$,.(#-$8i!N%W>m!-/8$,+&!TB+8!3tM= KNoK@'!6,++8!)B(88+;!)$;$,!-89$,.(#-$8i!N%W>m!-/8$,+&!TB+8!3tM= KNoK@'!K;7+!)B(88+;!)$;$,!-89$,.(#-$8i!N%W>m!-/8$,+&!TB+8!3tM=

!"#$%&'()*+,-./&"*0*1*.2*&3(.,(4

56

!"#$%&'()&*+,-./0&,%1234&,"5

"/7&8,)9*1 #++1*:: ;/.<*.<: !*0(,4<
=>*?@ =+*2@ =>*?@ =+*2@

0x00 0 0x0000 0 A6&2>(1(2<*1&2/+*: 0x00

0x01 1 0x0040 64 A6&2>(1(2<*1&2/+*: 0x00

0x02 2 0x0080 128 A6&2>(1(2<*1&2/+*: 0x00

0x03 3 0x00C0 192 A6&2>(1(2<*1&2/+*: 0x00

0x04 4 0x0100 256 A6&2>(1(2<*1&2/+*: 0x00

0x05 5 0x0140 320 A6&2>(1(2<*1&2/+*: 0x00

0x06 6 0x0180 384 A6&2>(1(2<*1&2/+*: 0x00

0x07 7 0x01C0 448 A6&2>(1(2<*1&2/+*: 0x00

0x08 8 0x0200 512 A6&2>(1(2<*1&2/+*: 0x00

0x09 9 0x0240 576 A6&2>(1(2<*1&2/+*: 0x00

0x0A 10 0x0280 640 A6&2>(1(2<*1&2/+*: 0x00

0x0B 11 0x02C0 704 A6&2>(1(2<*1&2/+*: 0x00

0x0C 12 0x0300 768 A6&2>(1(2<*1&2/+*: 0x00

0x0D 13 0x0340 832 A6&2>(1(2<*1&2/+*: 0x00

0x0E 14 0x0380 896 A6&2>(1(2<*1&2/+*: 0x00

0x0F 15 0x03C0 960 A6&2>(1(2<*1&2/+*: 0x00

0x10 16 0x0400 1024 A6&2>(1(2<*1&2/+*: 0x00

0x11 17 0x0440 1088 A6&2>(1(2<*1&2/+*: 0x00

0x12 18 0x0480 1152 A6&2>(1(2<*1&2/+*: 0x00

0x13 19 0x04C0 1216 A6&2>(1(2<*1&2/+*: 0x00

0x14 20 0x0500 1280 A6&2>(1(2<*1&2/+*: 0x00

0x15 21 0x0540 1344 A6&2>(1(2<*1&2/+*: 0x00

0x16 22 0x0580 1408 A6&2>(1(2<*1&2/+*: 0x00

0x17 23 0x05C0 1472 A6&2>(1(2<*1&2/+*: 0x00

0x18 24 0x0600 1536 A6&2>(1(2<*1&2/+*: 0x00

0x19 25 0x0640 1600 A6&2>(1(2<*1&2/+*: 0x00

0x1A 26 0x0680 1664 A6&2>(1(2<*1&2/+*: 0x00

0x1B 27 0x06C0 1728 A6&2>(1(2<*1&2/+*: 0x00

0x1C 28 0x0700 1792 A6&2>(1(2<*1&2/+*: 0x00

0x1D 29 0x0740 1856 A6&2>(1(2<*1&2/+*: 0x00

0x1E 30 0x0780 1920 A6&2>(1(2<*1&2/+*: 0x00

0x1F 31 0x07C0 1984 A6&2>(1(2<*1&2/+*: 0x00

"/7&8,)9*1 #++1*:: ;/.<*.<: !*0(,4<

=>*?@ =+*2@ =>*?@ =+*2@

0x20 32 0x0800 2048 A6&2>(1(2<*1&2/+*: 0x00

0x21 33 0x0840 2112 A6&2>(1(2<*1&2/+*: 0x00

0x22 34 0x0880 2176 A6&2>(1(2<*1&2/+*: 0x00

0x23 35 0x08C0 2240 A6&2>(1(2<*1&2/+*: 0x00

0x24 36 0x0900 2304 A6&2>(1(2<*1&2/+*: 0x00

0x25 37 0x0940 2368 A6&2>(1(2<*1&2/+*: 0x00

0x26 38 0x0980 2432 A6&2>(1(2<*1&2/+*: 0x00

0x27 39 0x09C0 2496 A6&2>(1(2<*1&2/+*: 0x00

0x28 40 0x0A00 2560 A6&2>(1(2<*1&2/+*: 0x00

0x29 41 0x0A40 2624 A6&2>(1(2<*1&2/+*: 0x00

0x2A 42 0x0A80 2688 A6&2>(1(2<*1&2/+*: 0x00

0x2B 43 0x0AC0 2752 A6&2>(1(2<*1&2/+*: 0x00

0x2C 44 0x0B00 2816 A6&2>(1(2<*1&2/+*: 0x00

0x2D 45 0x0B40 2880 A6&2>(1(2<*1&2/+*: 0x00

0x2E 46 0x0B80 2944 A6&2>(1(2<*1&2/+*: 0x00

0x2F 47 0x0BC0 3008 A6&2>(1(2<*1&2/+*: 0x00

0x30 48 0x0C00 3072 A6&2>(1(2<*1&2/+*: 0x00

0x31 49 0x0C40 3136 A6&2>(1(2<*1&2/+*: 0x00

0x32 50 0x0C80 3200 A6&2>(1(2<*1&2/+*: 0x00

0x33 51 0x0CC0 3264 A6&2>(1(2<*1&2/+*: 0x00

0x34 52 0x0D00 3328 A6&2>(1(2<*1&2/+*: 0x00

0x35 53 0x0D40 3392 A6&2>(1(2<*1&2/+*: 0x00

0x36 54 0x0D80 3456 A6&2>(1(2<*1&2/+*: 0x00

0x37 55 0x0DC0 3520 A6&2>(1(2<*1&2/+*: 0x00

0x38 56 0x0E00 3584 A6&2>(1(2<*1&2/+*: 0x00

0x39 57 0x0E40 3648 A6&2>(1(2<*1&2/+*: 0x00

0x3A 58 0x0E80 3712 A6&2>(1(2<*1&2/+*: 0x00

0x3B 59 0x0EC0 3776 A6&2>(1(2<*1&2/+*: 0x00

0x3C 60 0x0F00 3840 A6&2>(1(2<*1&2/+*: 0x00

0x3D 61 0x0F40 3904 A6&2>(1(2<*1&2/+*: 0x00

0x3E 62 0x0F80 3968 A6&2>(1(2<*1&2/+*: 0x00

0x3F 63 0x0FC0 4032 A6&2>(1(2<*1&2/+*: 0x00

!"#$%&'()*+,-./&"*0*1*.2*&3(.,(4

5B

!"#$%&'6)&*+,-07*&,%1234&,"5

;>(1(2<*1 #++1*:: ;/.<*.<:
=>*?@ =+*2@ =C@ =>*?@ =+*2@

0x00 0 0x1000 4096 DEDEF&9-<)(GH&IA&9J<*:

0x01 1 0x1010 4112 DEDEF&9-<)(GH&IA&9J<*:

0x02 2 0x1020 4128 DEDEF&9-<)(GH&IA&9J<*:

0x03 3 0x1030 4144 DEDEF&9-<)(GH&IA&9J<*:

0x04 4 0x1040 4160 DEDEF&9-<)(GH&IA&9J<*:

0x05 5 0x1050 4176 DEDEF&9-<)(GH&IA&9J<*:

0x06 6 0x1060 4192 DEDEF&9-<)(GH&IA&9J<*:

0x07 7 0x1070 4208 DEDEF&9-<)(GH&IA&9J<*:

0x08 8 0x1080 4224 DEDEF&9-<)(GH&IA&9J<*:

0x09 9 0x1090 4240 DEDEF&9-<)(GH&IA&9J<*:

0x0A 10 0x10A0 4256 DEDEF&9-<)(GH&IA&9J<*:

0x0B 11 0x10B0 4272 DEDEF&9-<)(GH&IA&9J<*:

0x0C 12 0x10C0 4288 DEDEF&9-<)(GH&IA&9J<*:

0x0D 13 0x10D0 4304 DEDEF&9-<)(GH&IA&9J<*:

0x0E 14 0x10E0 4320 DEDEF&9-<)(GH&IA&9J<*:

0x0F 15 0x10F0 4336 DEDEF&9-<)(GH&IA&9J<*:

0x10 16 0x1100 4352 DEDEF&9-<)(GH&IA&9J<*:

0x11 17 0x1110 4368 DEDEF&9-<)(GH&IA&9J<*:

0x12 18 0x1120 4384 DEDEF&9-<)(GH&IA&9J<*:

0x13 19 0x1130 4400 DEDEF&9-<)(GH&IA&9J<*:

0x14 20 0x1140 4416 DEDEF&9-<)(GH&IA&9J<*:

0x15 21 0x1150 4432 DEDEF&9-<)(GH&IA&9J<*:

0x16 22 0x1160 4448 DEDEF&9-<)(GH&IA&9J<*:

0x17 23 0x1170 4464 DEDEF&9-<)(GH&IA&9J<*:

0x18 24 0x1180 4480 DEDEF&9-<)(GH&IA&9J<*:

0x19 25 0x1190 4496 DEDEF&9-<)(GH&IA&9J<*:
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

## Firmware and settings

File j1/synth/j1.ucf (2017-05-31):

#####################################################
#
# XSA-3S1000 Board FPGA pin assignment constraints
#
#####################################################
#
# Clocks
#
net CLKA          loc=T9  | IOSTANDARD = LVCMOS33 ; # 100MHz
#net CLKB          loc=P8  | IOSTANDARD = LVCMOS33 ; # 50MHz
#net CLKC          loc=R9  | IOSTANDARD = LVCMOS33 ; # ??Mhz
#
# Push button switches
#
#NET SW1_3_N       loc=K2  | IOSTANDARD = LVCMOS33 ; # Flash Block select 
#NET SW1_4_N       loc=J4  | IOSTANDARD = LVCMOS33 ; # Flash Block
#NET SW2_N         loc=E11 | IOSTANDARD = LVCMOS33 ; # active-low pushbutton 
#NET SW3_N         loc=A13 | IOSTANDARD = LVCMOS33 ; # active-low pushbutton
#
# PS/2 Keyboard
#
net PS2_CLK       loc=B16 | IOSTANDARD = LVCMOS33 ; 
net PS2_DAT       loc=E13 | IOSTANDARD = LVCMOS33 ; 
#
# VGA Outputs
#
NET VGA_BLUE<0>   LOC=C9  | IOSTANDARD = LVCMOS33 ;        
NET VGA_BLUE<1>   LOC=E7  | IOSTANDARD = LVCMOS33 ;        
NET VGA_BLUE<2>   LOC=D5  | IOSTANDARD = LVCMOS33 ;        
NET VGA_GREEN<0>  LOC=A8  | IOSTANDARD = LVCMOS33 ;        
NET VGA_GREEN<1>  LOC=A5  | IOSTANDARD = LVCMOS33 ;        
NET VGA_GREEN<2>  LOC=C3  | IOSTANDARD = LVCMOS33 ;        
NET VGA_RED<0>    LOC=C8  | IOSTANDARD = LVCMOS33 ;        
NET VGA_RED<1>    LOC=D6  | IOSTANDARD = LVCMOS33 ;        
NET VGA_RED<2>    LOC=B1  | IOSTANDARD = LVCMOS33 ;        
NET VGA_HSYNC_N   LOC=B7  | IOSTANDARD = LVCMOS33 ;        
NET VGA_VSYNC_N   LOC=D8  | IOSTANDARD = LVCMOS33 ;        
#
# Manually assign locations for the DCMs along the bottom of the FPGA
# because PAR sometimes places them in opposing corners and that ruins the clocks.
#
#INST "u1/gen_dlls.dllint" LOC="DCM_X0Y0";
#INST "u1/gen_dlls.dllext" LOC="DCM_X1Y0";

# Manually assign locations for the DCMs along the bottom of the FPGA
# because PAR sometimes places them in opposing corners and that ruins the clocks.
#INST "u2_dllint" LOC="DCM_X0Y0";
#INST "u2_dllext" LOC="DCM_X1Y0";
#
# SDRAM memory pin assignments
#
#net SDRAM_clkfb  loc=N8  | IOSTANDARD = LVCMOS33 ;  # feedback SDRAM clock after PCB delays
#net SDRAM_clkout loc=E10 | IOSTANDARD = LVCMOS33 ; # clock to SDRAM
#net SDRAM_CKE    loc=D7  | IOSTANDARD = LVCMOS33 ;  # SDRAM clock enable
#net SDRAM_CS_N   loc=B8  | IOSTANDARD = LVCMOS33 ;  # SDRAM chip-select
#net SDRAM_RAS_N  loc=A9  | IOSTANDARD = LVCMOS33 ;  
#net SDRAM_CAS_N  loc=A10 | IOSTANDARD = LVCMOS33 ; 
#net SDRAM_WE_N   loc=B10 | IOSTANDARD = LVCMOS33 ; 
#net SDRAM_DQMH   loc=D9  | IOSTANDARD = LVCMOS33 ;  
#net SDRAM_DQML   loc=C10 | IOSTANDARD = LVCMOS33 ; 
#net SDRAM_A<0>   loc=B5  | IOSTANDARD = LVCMOS33 ;  
#net SDRAM_A<1>   loc=A4  | IOSTANDARD = LVCMOS33 ;  
#net SDRAM_A<2>   loc=B4  | IOSTANDARD = LVCMOS33 ;  
#net SDRAM_A<3>   loc=E6  | IOSTANDARD = LVCMOS33 ;  
#net SDRAM_A<4>   loc=E3  | IOSTANDARD = LVCMOS33 ;  
#net SDRAM_A<5>   loc=C1  | IOSTANDARD = LVCMOS33 ;  
#net SDRAM_A<6>   loc=E4  | IOSTANDARD = LVCMOS33 ;  
#net SDRAM_A<7>   loc=D3  | IOSTANDARD = LVCMOS33 ;  
#net SDRAM_A<8>   loc=C2  | IOSTANDARD = LVCMOS33 ;  
#net SDRAM_A<9>   loc=A3  | IOSTANDARD = LVCMOS33 ;  
#net SDRAM_A<10>  loc=B6  | IOSTANDARD = LVCMOS33 ;  
#net SDRAM_A<11>  loc=C5  | IOSTANDARD = LVCMOS33 ;  
#net SDRAM_A<12>  loc=C6  | IOSTANDARD = LVCMOS33 ;  
#net SDRAM_D<0>   loc=C15 | IOSTANDARD = LVCMOS33 ; 
#net SDRAM_D<1>   loc=D12 | IOSTANDARD = LVCMOS33 ; 
#net SDRAM_D<2>   loc=A14 | IOSTANDARD = LVCMOS33 ; 
#net SDRAM_D<3>   loc=B13 | IOSTANDARD = LVCMOS33 ; 
#net SDRAM_D<4>   loc=D11 | IOSTANDARD = LVCMOS33 ; 
#net SDRAM_D<5>   loc=A12 | IOSTANDARD = LVCMOS33 ; 
#net SDRAM_D<6>   loc=C11 | IOSTANDARD = LVCMOS33 ; 
#net SDRAM_D<7>   loc=D10 | IOSTANDARD = LVCMOS33 ; 
#net SDRAM_D<8>   loc=B11 | IOSTANDARD = LVCMOS33 ; 
#net SDRAM_D<9>   loc=B12 | IOSTANDARD = LVCMOS33 ; 
#net SDRAM_D<10>  loc=C12 | IOSTANDARD = LVCMOS33 ; 
#net SDRAM_D<11>  loc=B14 | IOSTANDARD = LVCMOS33 ; 
#net SDRAM_D<12>  loc=D14 | IOSTANDARD = LVCMOS33 ; 
#net SDRAM_D<13>  loc=C16 | IOSTANDARD = LVCMOS33 ; 
#net SDRAM_D<14>  loc=F12 | IOSTANDARD = LVCMOS33 ; 
#net SDRAM_D<15>  loc=F13 | IOSTANDARD = LVCMOS33 ; 
#net SDRAM_BA<0>  loc=A7  | IOSTANDARD = LVCMOS33 ;  
#net SDRAM_BA<1>  loc=C7  | IOSTANDARD = LVCMOS33 ;  
#
# Flash memory interface

net FLASH_A<0>   LOC=N5  | IOSTANDARD = LVCMOS33 ;
net FLASH_A<1>   LOC=K14 | IOSTANDARD = LVCMOS33 ;
net FLASH_A<2>   LOC=K13 | IOSTANDARD = LVCMOS33 ;
net FLASH_A<3>   LOC=K12 | IOSTANDARD = LVCMOS33 ;
net FLASH_A<4>   LOC=L14 | IOSTANDARD = LVCMOS33 ;
net FLASH_A<5>   LOC=M16 | IOSTANDARD = LVCMOS33 ;
net FLASH_A<6>   LOC=L13 | IOSTANDARD = LVCMOS33 ;
net FLASH_A<7>   LOC=N16 | IOSTANDARD = LVCMOS33 ;
net FLASH_A<8>   LOC=N14 | IOSTANDARD = LVCMOS33 ;
net FLASH_A<9>   LOC=P15 | IOSTANDARD = LVCMOS33 ;
net FLASH_A<10>  LOC=R16 | IOSTANDARD = LVCMOS33 ;
net FLASH_A<11>  LOC=P14 | IOSTANDARD = LVCMOS33 ;
net FLASH_A<12>  LOC=P13 | IOSTANDARD = LVCMOS33 ;
net FLASH_A<13>  LOC=N12 | IOSTANDARD = LVCMOS33 ;
net FLASH_A<14>  LOC=T14 | IOSTANDARD = LVCMOS33 ;
net FLASH_A<15>  LOC=R13 | IOSTANDARD = LVCMOS33 ;
net FLASH_A<16>  LOC=N10 | IOSTANDARD = LVCMOS33 ;
net FLASH_A<17>  LOC=M14 | IOSTANDARD = LVCMOS33 ;
net FLASH_A<18>  LOC=K3  | IOSTANDARD = LVCMOS33 ;
net FLASH_A<19>  LOC=K4  | IOSTANDARD = LVCMOS33 ;

net FLASH_D<0>   LOC=M11 | IOSTANDARD = LVCMOS33 ;
net FLASH_D<1>   LOC=N11 | IOSTANDARD = LVCMOS33 ;
net FLASH_D<2>   LOC=P10 | IOSTANDARD = LVCMOS33 ;
net FLASH_D<3>   LOC=R10 | IOSTANDARD = LVCMOS33 ;
net FLASH_D<4>   LOC=T7  | IOSTANDARD = LVCMOS33 ;
net FLASH_D<5>   LOC=R7  | IOSTANDARD = LVCMOS33 ;
net FLASH_D<6>   LOC=N6  | IOSTANDARD = LVCMOS33 ;
net FLASH_D<7>   LOC=M6  | IOSTANDARD = LVCMOS33 ;
net FLASH_D<8>   LOC=T4  | IOSTANDARD = LVCMOS33 ;
net FLASH_D<9>   LOC=R5  | IOSTANDARD = LVCMOS33 ;
net FLASH_D<10>  LOC=T5  | IOSTANDARD = LVCMOS33 ;
net FLASH_D<11>  LOC=P6  | IOSTANDARD = LVCMOS33 ;
net FLASH_D<12>  LOC=M7  | IOSTANDARD = LVCMOS33 ;
net FLASH_D<13>  LOC=R6  | IOSTANDARD = LVCMOS33 ;
net FLASH_D<14>  LOC=N7  | IOSTANDARD = LVCMOS33 ;
net FLASH_D<15>  LOC=P7  | IOSTANDARD = LVCMOS33 ;
net FLASH_CE_N   LOC=R4  | IOSTANDARD = LVCMOS33 ;
net FLASH_OE_N   LOC=P5  | IOSTANDARD = LVCMOS33 ;
net FLASH_WE_N   LOC=M13 | IOSTANDARD = LVCMOS33 ;
net FLASH_BYTE_N LOC=T8  | IOSTANDARD = LVCMOS33 ;
net FLASH_RDY    LOC=L12 | IOSTANDARD = LVCMOS33 ;
net FLASH_RST_N  LOC=P16 | IOSTANDARD = LVCMOS33 ;
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

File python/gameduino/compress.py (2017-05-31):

import time
import sys
import array

def prefix(s1, s2):
    """ Return the length of the common prefix of s1 and s2 """
    sz = len(s2)
    for i in range(sz):
        if s1[i % len(s1)] != s2[i]:
            return i
    return sz

def runlength(blk, p0, p1):
    """ p0 is the source position, p1 is the dest position
    Return the length of run of common chars
    """
    for i in range(1, len(blk) - p1):
        if blk[p0:p0+i] != blk[p1:p1+i]:
            return i - 1
    return len(blk) - p1 - 1

def runlength2(blk, p0, p1, bsf):
    """ p0 is the source position, p1 is the dest position
    Return the length of run of common chars
    """
    if blk[p0:p0+bsf+1] != blk[p1:p1+bsf+1]:
        return 0
    for i in range(bsf + 1, len(blk) - p1):
        if blk[p0:p0+i] != blk[p1:p1+i]:
            return i - 1
    return len(blk) - p1 - 1

class Bitstream(object):
    def __init__(self):
        self.b = []
    def append(self, sz, v):
        assert 0 <= v
        assert v < (1 << sz)
        for i in range(sz):
            self.b.append(1 & (v >> (sz - 1 - i)))
    def toarray(self):
        bb = [0] * ((len(self.b) + 7) / 8)
        for i,b in enumerate(self.b):
            if b:
                bb[i / 8] |= (1 << (i & 7));
        return array.array('B', bb)

class Codec(object):
    def __init__(self, b_off, b_len):
        self.b_off = b_off
        self.b_len = b_len
        self.history = 2 ** b_off
        refsize = (1 + self.b_off + self.b_len) # bits needed for a backreference
        if refsize < 9:
            self.M = 1
        elif refsize < 18:
            self.M = 2
        else:
            self.M = 3
        # print "M", self.M
        # e.g. M 2, b_len 4, so: 0->2, 15->17
        self.maxlen = self.M + (2**self.b_len) - 1

    def compress(self, blk):
        lempel = {}
        sched = []
        pos = 0
        while pos < len(blk):
            k = blk[pos:pos+self.M]
            older = (pos - self.history - 1)
            candidates = set([p for p in lempel.get(k, []) if (older < p)])
            lempel[k] = candidates  # prune old
            # print pos, repr(k), len(lempel), "lempels", "candidates", len(candidates)
            def addlempel(c):
                if c in lempel:
                    lempel[c].add(pos)
                else:
                    lempel[c] = set([pos])
            if 0:
                # (bestlen, bestpos) = max([(0, 0)] + [(prefix(blk[p:pos], blk[pos:]), p) for p in candidates])
                (bestlen, bestpos) = max([(0, 0)] + [(runlength(blk, p, pos), p) for p in candidates])
                bestlen = min(bestlen, self.maxlen)
            else:
                (bestlen, bestpos) = (0, None)
                for p in candidates:
                    cl = runlength2(blk, p, pos, bestlen)
                    if cl > bestlen:
                        bestlen,bestpos = cl,p
                    if self.maxlen <= bestlen:
                        bestlen = min(bestlen, self.maxlen)
                        break
            if bestlen >= self.M:
                sched.append((bestpos - pos, bestlen))
                for i in range(bestlen):
                    addlempel(blk[pos:pos+self.M])
                    pos += 1
            else:
                addlempel(k)
                sched.append(blk[pos])
                pos += 1
        return sched

    def toarray(self, blk):
        sched = self.compress(blk)
        return self.sched2bs(sched)

    def sched2bs(self, sched):
        bs = Bitstream()
        bs.append(4, self.b_off)
        bs.append(4, self.b_len)
        bs.append(2, self.M)
        bs.append(16, len(sched))
        for c in sched:
            if len(c) != 1:
                (offset, l) = c
                bs.append(1, 1)
                bs.append(self.b_off, -offset - 1)
                bs.append(self.b_len, l - self.M)
            else:
                bs.append(1, 0)
                bs.append(8, ord(c))
        return bs.toarray()

    def to_cfile(self, hh, blk, name):
        print >>hh, "static PROGMEM prog_uchar %s[] = {" % name
        bb = self.toarray(blk)
        for i in range(0, len(bb), 16):
            if (i & 0xff) == 0:
                print >>hh
            for c in bb[i:i+16]:
                print >>hh, "0x%02x, " % c,
            print >>hh
        print >>hh, "};"

    def decompress(self, sched):
        s = ""
        for c in sched:
            if len(c) == 1:
                s += c
            else:
                (offset, l) = c
                for i in range(l):
                    s += s[offset]
        return s

def main():
    from optparse import OptionParser
    parser = OptionParser("%prog [ --lookback O ] [ --length L ] --name NAME inputfile outputfile")

    parser.add_option("--lookback", type=int, default=8, dest="O", help="lookback field size in bits")
    parser.add_option("--length", type=int, default=3, dest="L", help="length field size in bits")
    parser.add_option("--name", type=str, default="data", dest="NAME", help="name for generated C array")
    parser.add_option("--binary", action="store_true", default=False, dest="binary", help="write a binary file (default is to write a C++ header file)")
    options, args = parser.parse_args()

    if len(args) != 2:
        parser.error("must specify input and output files");

    print options.O
    print options.L
    print options.NAME
    print args
    (inputfile, outputfile) = args
    cc = Codec(b_off = options.O, b_len = options.L)
    uncompressed = open(inputfile, "rb").read()
    if options.binary:
        compressed = cc.toarray(uncompressed)
        open(outputfile, "wb").write(compressed.tostring())
    else:
        outfile = open(outputfile, "w")
        cc.to_cfile(outfile, uncompressed, options.NAME)

if __name__ == "__main__":
    main()
